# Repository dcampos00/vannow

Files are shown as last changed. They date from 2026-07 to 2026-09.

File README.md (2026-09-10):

# VanNOW: Sistema de Relés Inalámbricos para Camper Van

Este proyecto (**VanNOW**) contiene el diseño de hardware (como código) y el firmware para un sistema de conmutación de relés y transistores inteligente en una camper van, controlado de forma inalámbrica por ESP32 mediante el protocolo autónomo ESP-NOW.

---

## Estructura del Repositorio

- **`docs/`**: Contiene la documentación técnica, decisiones de arquitectura, especificaciones mecánicas y auditorías.
  - [**docs/README.md**](docs/README.md): **Centro de Documentación y Catálogo Maestro.**
  - [propuesta_proyecto.md](docs/propuesta_proyecto.md): Propuesta inicial aprobada.
  - [mechanical_and_enclosure_specs.md](docs/mechanical_and_enclosure_specs.md): Especificaciones de enclosures, cotas y mandos magnéticos.
- **`firmware/`**: Código fuente C++ para los microcontroladores (gestión con PlatformIO).
  - **`central/`**: Firmware del receptor en el gabinete eléctrico central. Controla MOSFETs, PROFETs y optoacopladores.
    - [platformio.ini](firmware/central/platformio.ini)
    - [src/main.cpp](firmware/central/src/main.cpp)
  - **`remote/`**: Firmware para los paneles de pulsadores inalámbricos autónomos. Utiliza Deep Sleep profundo y envía comandos al central.
    - [platformio.ini](firmware/remote/platformio.ini)
    - [src/main.cpp](firmware/remote/src/main.cpp)
- **`hardware/`**: Código de diseño de circuito impreso (PCB) y modelos CAD paramétricos 3D.
  - **`central-pcb/`**: Diseño Atopile de la placa de control central.
    - [ato.yaml](hardware/central-pcb/ato.yaml)
    - [central.ato](hardware/central-pcb/central.ato): Esquema y conexiones de la placa central.
  - **`enclosures/`**: Modelos 3D paramétricos generados con Python (`build123d`), archivos STEP/STL y renders.

---

## Cómo Empezar

### 1. Firmware (PlatformIO)

Para cargar el software en tus módulos ESP32:

1. Abre la carpeta `firmware/central/` o `firmware/remote/` en VS Code con la extensión **PlatformIO** instalada.
2. En el módulo **Central**, compila y sube el código. Abre el monitor serial a `115200 baudios` y copia la **Dirección MAC** del dispositivo.
3. En el archivo [src/main.cpp del módulo remoto](firmware/remote/src/main.cpp#L17), reemplaza la dirección MAC en `centralMacAddress` con la dirección que copiaste del central:

   ```cpp
   uint8_t centralMacAddress[] = {0x12, 0x34, 0x56, 0x78, 0x9A, 0xBC};
   ```

4. Carga el código en el módulo remoto.
5. ¡Listo! Al presionar los pulsadores (conectados a los pines indicados), el remoto transmitirá la señal de conmutación al central.

### 2. Hardware (Atopile)

Para compilar el circuito y generar los archivos de KiCad:

1. Asegúrate de tener instalado Python y Atopile (`pip install atopile`).
2. Abre una terminal en `hardware/central-pcb/`.
3. Ejecuta el comando para compilar:

   ```bash
   ato build
   ```

4. Esto validará las conexiones eléctricas y generará los esquemáticos y la netlist en formato compatible con **KiCad**.

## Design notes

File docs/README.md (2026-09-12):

# VanNOW Documentation Hub

Welcome to the **VanNOW** (Wireless Camper Van Relay System) engineering knowledge base. This directory compiles all architecture proposals, hardware evaluations, firmware specifications, mechanical 3D blueprints, safety audits, and feasibility studies.

---

## 🧭 Role-Based Navigation ("Where Do I Start?")

- **Working on Firmware?** Start with [`firmware_documentation.md`](firmware_documentation.md) for class models and state machines, then check [`roadmap.md`](roadmap.md) for prioritized features and [`logic_audit_2026-09-11.md`](logic_audit_2026-09-11.md) for the active logic findings (channel-map identity, Shower Mode keep-alive oscillation, encoder dual-dispatch).
- **Working on Hardware & PCB?** Review [`logic_audit_2026-09-11.md`](logic_audit_2026-09-11.md) for the current hardware/firmware desynchronization and residual electrical issues, [`logic_audit_2026-09-03.md`](logic_audit_2026-09-03.md) for the historical DevKit socket short (now fixed), [`evaluacion_hardware.md`](evaluacion_hardware.md) for MCU specs, [`analisis_critico_riesgos.md`](analisis_critico_riesgos.md) for flyback/bypass safety rules, and inspect [`references/`](references/) for component datasheets.
- **Working on 3D Printing & Enclosures?** Read [`mechanical_and_enclosure_specs.md`](mechanical_and_enclosure_specs.md) for DIN cabinet envelopes, 50 mm wiring clearances, and magnetic dock retention physics. Check `hardware/enclosures/` for Python CAD generators (`generate_enclosures.py`) and exported STEP/STL models.
- **Benchmarking & Power Budgets?** Review [`eficiencia_energetica.md`](eficiencia_energetica.md) for standby power analysis and [`evaluacion_costos_vanpi.md`](evaluacion_costos_vanpi.md) for BOM costing.

---

## 📚 Master Document Catalog

### 1. Architecture, System Design & Planning
| Document | Language | Status | Summary |
| :--- | :---: | :---: | :--- |
| [**project_status_and_tracking.md**](project_status_and_tracking.md) | EN | Active (Alpha) | Cross-domain status. Not a 1.0 or fab release. 11/24-ch flash envs. |
| [**central_controller_24ch_architecture.md**](central_controller_24ch_architecture.md) | EN | Active (Spec) | Expanded 24-channel Central Controller architecture, 14 PROFET + 10 optocoupler allocation, and modular firmware design. |
| [**propuesta_proyecto.md**](propuesta_proyecto.md) | ES | Active (Base) | Approved baseline project proposal: ESP-NOW wireless topology, 12V channel definitions, and Atopile introduction. |
| [**roadmap.md**](roadmap.md) | ES/EN | Active (Living) | Prioritized 4-tier feature roadmap (NVS persistence, WDT, anti-replay, scenes, LED feedback, web diagnostics). |
| [**gestion_repositorios_dual.md**](gestion_repositorios_dual.md) | ES | Active (Ops) | Private/public repo synchronization procedure and `sync_public.sh` documentation. |

### 2. Firmware & Wireless Protocols
| Document | Language | Status | Summary |
| :--- | :---: | :---: | :--- |
| [**firmware_documentation.md**](firmware_documentation.md) | ES | Active (Master) | Unified firmware architecture, class diagrams, 200 Hz PWM dimming, button/matrix FSMs, and PlatformIO environments. |
| [**atenuacion_remota.md**](atenuacion_remota.md) | ES | Active (Spec) | Remote dimmer button UX: Short-press toggle vs long-press ramp with 150 ms keep-alive packets. |
| [**control_encoder_rotativo.md**](control_encoder_rotativo.md) | ES | Active (Spec) | Rotary encoder (EC11) wireless logic, "Active-on-Demand" 1.5s timeout, and LP-GPIO pinouts. |
| [**analisis_seguridad_rf.md**](analisis_seguridad_rf.md) | ES | Decision | Threat model comparing 433 MHz ASK/OOK vs ESP-NOW; justifies discarding 433 MHz due to replay attacks. |
| [**integracion_cc1101_433mhz.md**](integracion_cc1101_433mhz.md) | ES | Evaluated | Technical evaluation of CC1101 Sub-GHz transceiver integration via SPI (alternative RF route). |

### 3. Hardware, PCB & Mechanical Engineering
| Document | Language | Status | Summary |
| :--- | :---: | :---: | :--- |
| [**remote_pcbs_architecture.md**](remote_pcbs_architecture.md) | EN | Active (Spec) | Architectural specification, UX evaluation & Diode-OR wakeup schematics for Cockpit Hub and Master Entrance Remote. |
| [**mechanical_and_enclosure_specs.md**](mechanical_and_enclosure_specs.md) | EN | Active (Master) | Enclosure dimensions, DIN-rail mounting, 50 mm wiring clearances, magnetic dockable remote (10.5N retention), PETG/ASA printing specs. |
| [**evaluacion_hardware.md**](evaluacion_hardware.md) | ES | Decision | Hardware selection: Lonely Binary ESP32-S3 N16R8 for Central, XIAO ESP32-C6 for Remotes, PCA9685 vs direct GPIOs. |
| [**opciones_encoders_bajo_perfil.md**](opciones_encoders_bajo_perfil.md) | ES | Component | Low-profile (5 mm) encoder selection: Panasonic EVQ-WGD thumbwheel, Alps EC12E SMD, and Alps EC10E hollow-shaft. |
| [**breadboard_prototyping_and_validation_guide.md**](breadboard_prototyping_and_validation_guide.md) | EN | Active (Lab) | Bench bring-up for 24-ch firmware + entrance remote: USB Phase A, fused 12 V Phase B, current pin map. |
| [**lista_compras_prototipo.md**](lista_compras_prototipo.md) | ES | Lab Guide | Component checklist and wiring guide for the breadboard prototype, including 3-step test plan. |
| [**skills/schematic-design**](../.agents/skills/schematic-design/SKILL.md) | EN | Skill | Comprehensive guide for Hardware-as-Code (Atopile), automotive power entry, PROFET switching, ADC clamping, and automotive protection. |
| [**skills/pcb-layout-automation**](../.agents/skills/pcb-layout-automation/SKILL.md) | EN | Skill | Procedural PCB layout, IPC-2152 automotive trace routing, thermal via arrays, and headless KiCad pcbnew DRC validation. |
| [**skills/esp32-firmware-engineering**](../.agents/skills/esp32-firmware-engineering/SKILL.md) | EN | Skill | Embedded firmware engineering for ESP32-S3 and ESP32-C6, 200 Hz PROFET PWM, sliding window anti-replay, LP-GPIO sleep wakeups, and native TDD. |
| [**skills/pcb-rendering**](../.agents/skills/pcb-rendering/SKILL.md) | EN | Skill | Automated KiCad raytracing, 1440p/4K isometric visualization, populated 3D STEP solid export, and ECAD/MCAD clash detection in build123d. |
| [**skills/parametric-cad-enclosures**](../.agents/skills/parametric-cad-enclosures/SKILL.md) | EN | Skill | Production guide for Python Code-as-CAD (`build123d`), heat-set fastener sizing, stepped joints, and software Z-buffer mesh verification. |
| [**skills/cross-domain-sync**](../.agents/skills/cross-domain-sync/SKILL.md) | EN | Skill | Cross-domain co-design audit matrix synchronizing Atopile netlists, KiCad layout, firmware GPIOs, and parametric CAD apertures. |
| [**references/**](references/) | PDF/XLSX | Assets | Official component datasheets (BTS5008 PROFET, MP1584EN, PC817, ESP32-S3, ESP32-C6). |

### 4. Audits, Verification & Risk Analysis
| Document | Language | Status | Summary |
| :--- | :---: | :---: | :--- |
| [**logic_audit_2026-09-11.md**](logic_audit_2026-09-11.md) | EN | Active (Must Read) | Current comprehensive logic audit: 11ch vs 24ch identity split, Shower Mode keep-alive oscillation, encoder dual-dispatch, missing DoubleClick, XIAO D10/GPIO9 LED error. |
| [**logic_audit_2026-09-03.md**](logic_audit_2026-09-03.md) | EN | Historical (Closed blockers) | Prior audit of 7 critical flaws (DevKit GND short, replay bypass, 5 kHz PWM, 3.3V Zener). Blockers fixed; superseded by 2026-09-11. |
| [**auditoria_logica_2026-07-11.md**](auditoria_logica_2026-07-11.md) | ES | Historical | Preliminary audit uncovering 25 hardware/firmware issues (USB-JTAG collisions on GPIO 19/20, PSRAM collisions). |
| [**analisis_critico_riesgos.md**](analisis_critico_riesgos.md) | ES | Active (Safety) | Electrical fire hazards, inductive flyback diode (1N5408), diesel heater/fridge PC817 logic, and ON-OFF-AUTO bypass panel mounting. |

### 5. Feasibility, Energy Budgets & Benchmarking
| Document | Language | Status | Summary |
| :--- | :---: | :---: | :--- |
| [**eficiencia_energetica.md**](eficiencia_energetica.md) | ES | Active (Budget) | Standby power budget: VanNOW (0.15 W, 0.25 Ah/day -> 400 days on 100Ah) vs Home Assistant/VanPi (10–15 W, 20–30 Ah/day -> 5 days). |
| [**evaluacion_costos_vanpi.md**](evaluacion_costos_vanpi.md) | ES | Reference | Cost estimation: VanNOW DIY (~$137 USD) vs Pekaway VanPi official hardware (~348 EUR). |
| [**proyectos_existentes_maduros.md**](proyectos_existentes_maduros.md) | ES | Reference | Industry benchmark comparing VanPi, Home Assistant + ESPHome, and Victron Venus OS. |
| [**estimacion_complejidad_tiempo.md**](estimacion_complejidad_tiempo.md) | ES | Reference | 4-phase project timeline breakdown: 30–50 active hours across 6–10 calendar weeks. |

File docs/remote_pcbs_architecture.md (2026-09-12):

# VanNOW — Cockpit Switch Hub & Master Magnetic Remote Architectural Specification

This document presents the UX evaluation, electrical schematics, mechanical integration, and firmware protocol mapping for the two new remote units in the **VanNOW** camper ecosystem:
1. **Cockpit Dashboard Switch Box (`cockpit-pcb`):** A hidden, battery-powered interface transmitter behind the van dash connecting directly to user-supplied automotive Carling rocker switch blanks.
2. **Master Magnetic Entrance Remote (`entrance-remote-pcb`):** A dockable multi-button and rotary dimmer panel retained magnetically at the van sliding door.

---

## 1. UX & Ergonomic Evaluation: Master Entrance Remote Dimming & Configurations

The user requested an evaluation comparing **Option 1 (Buttons + Rotary Dimmer Knob)** versus **Option 3 (Expanded 10–12 Button Matrix / Dedicated Configuration Buttons)** for intuitive van lighting control.

```
+-----------------------------------------------------------------------------------------------+
|                       COMPARATIVE EVALUATION: VAN ENTRANCE CONTROLLER                         |
+------------------------------+--------------------------------+-------------------------------+
| CRITERIA                     | OPTION 1: 6 BUTTONS + ENCODER  | OPTION 3: 10-12 BUTTON MATRIX |
+------------------------------+--------------------------------+-------------------------------+
| Primary Interaction          | "Select Zone -> Turn Knob"     | "One-Touch Scene / Function"  |
| Dimming Granularity          | 1% steps (tactile detents)     | Timed Hold or 3-step presets  |
| Mechanical Complexity        | Rotary shaft + 6 push buttons  | 10-12 membrane / tactile keys |
| Darkness / Blind Ergonomics  | Tactile knob easily found      | Requires searching key grid   |
| Multi-Scene / Presets        | Click encoder for mode/preset  | Dedicated button per scene    |
| Existing 3D CAD Alignment    | 100% matched to 86x86 mm CAD   | Requires larger faceplate     |
+------------------------------+--------------------------------+-------------------------------+
```

### 1.1 The Challenge: Multi-Zone Dimming in a Camper Van
A camper van has 4 distinct dimmable lighting zones:
- **Zone 1:** Main Ceiling Downlights (200 Hz PWM)
- **Zone 2:** Kitchen Galley Worktop (200 Hz PWM)
- **Zone 3:** Bed / Reading Nook (200 Hz PWM)
- **Zone 4:** Porch / Exterior Awning (PROFET Aux 1)

In addition, it controls high-power appliances: **Water Pump (Seaflo 7.5A)**, **Inverter (Multiplus II)**, and **Ceiling Vent Fan**.

### 1.2 Paradigm Analysis

#### Paradigm A: "Select & Turn" (Option 1 — 6 Buttons + EC11 Rotary Encoder)
- **How It Works:**
  1. Each zone has its own tactile button with a label/icon (Ceiling, Galley, Bed, Porch).
  2. Tapping a button toggles that zone ON/OFF immediately and selects it as the *Active Focus Zone* for 3.0 seconds.
  3. Turning the EC11 rotary knob adjusts the brightness of the active zone in real time with continuous tactile feedback (clicks).
  4. Pushing the encoder knob itself operates as **Instant 100% Boost** or cycles through brightness presets (20% -> 50% -> 100%).
  5. Buttons 5 and 6 are dedicated to **Water Pump Toggle** and **Master Night Shutdown (All OFF)**.
- **Ergonomic Verdict:** **Superior for fine-grained lighting comfort.** When reading or cooking, you can set the exact lumen output in 0.5 seconds without waiting for a slow software ramp.

#### Paradigm B: "Dedicated Scene Presets" (Option 3 — 10–12 Button Keypad Matrix)
- **How It Works:**
  Instead of manual dimming adjustments every time, van lighting is organized into pre-programmed camper scenes:
  - **Button 1 (Day / Bright):** Ceiling 100%, Galley 100%, Bed OFF.
  - **Button 2 (Galley / Cooking):** Galley 100%, Ceiling 40%, Fan ON.
  - **Button 3 (Evening / Cozy):** Ceiling 20%, Bed 25%, Warm ambient.
  - **Button 4 (Night / Sleep):** All lights OFF, Water Pump OFF.
  - **Button 5 (Exterior / Campsite):** Porch ON 80%, Step lights ON.
  - **Buttons 6–10:** Individual toggles for Water Pump, Inverter, Vent Fan, Fridge, Aux.
- **Ergonomic Verdict:** **Superior for zero-cognitive-load operation.** Any guest, child, or tired traveler can hit "Bedtime" or "Cooking" and the entire van configures itself without touching individual dimmers.

### 1.3 Recommended Architectural Decision: The Unified Hybrid Model
We can achieve the best of both paradigms within the **exact 86 mm x 86 mm physical form factor** already designed in 3D CAD:
1. **Short Tap on Zone Button:** Toggles ON/OFF.
2. **Double Tap on Zone Button:** Activates that Zone's Favorite Preset (e.g. 30% Nightlight).
3. **Turn Rotary Knob:** Adjusts brightness of the active zone up/down.
4. **Dedicated Master Night Shutdown Button:** One-touch full van shutdown.
5. **Hardware Compatibility:** The carrier board PCB is engineered with standard matrix traces, allowing the exact same microcontroller firmware to support either:
   - The 6-Button + EC11 Encoder Faceplate (Dockable remote).
   - A 10-Keypad tactile membrane panel if preferred.

---

## 2. Cockpit Dashboard Switch Box (`cockpit-pcb`)

### 2.1 Concept & Vehicle Integration
Modern camper vans (Mercedes Sprinter, Ford Transit, Ram ProMaster, VW Crafter) feature standard blank switch plates on the center console and lower dash. Installing custom all-in-one screens or surface boxes on the dash disrupts vehicle aesthetics and creates clutter.

```
DASHBOARD INTERFACE ARCHITECTURE:
+-------------------------------------------------------------------------+
| VEHICLE COCKPIT DASHBOARD                                               |
|                                                                         |
|   [ Carling Blank 1 ]  [ Carling Blank 2 ]  [ Carling Blank 3 ]         |
|   (Exterior Driving)   (Orion-XS DC-DC)     (Cabin Main Lights)         |
|   [ Carling Blank 4 ]  [ Carling Blank 5 ]  [ Carling Blank 6 ]         |
|   (Water Pump)         (Inverter AC)        (Aux 12V / Fan)             |
|            |                    |                    |                  |
|            +--------------------+--------------------+                  |
|                                 | (Automotive Signal Harness, 22 AWG)   |
|                                 v                                       |
|               +-----------------------------------+                     |
|               | COCKPIT TRANSMITTER BOX (HIDDEN)  |                     |
|               | - 6x Screw Terminal Block         |                     |
|               | - Diode-OR Wakeup (BAS70-04)      |                     |
|               | - Seeed Studio XIAO ESP32-C6      |                     |
|               | - 2x AA Battery Bay (Internal)    |                     |
|               | - Sub-15 uA Deep Sleep            |                     |
|               +-----------------------------------+                     |
|                                 |                                       |
|                                 | ESP-NOW (Encrypted, 2.4 GHz)          |
|                                 v                                       |
|                  [ Central Relay Electrical Cabinet ]                   |
+-------------------------------------------------------------------------+
```

### 2.2 Technical Specifications

| Parameter | Specification | Notes |
| :--- | :--- | :--- |
| **Enclosure Envelope** | $76.0\,\text{mm} \times 58.0\,\text{mm} \times 30.0\,\text{mm}$ | `cockpit_enclosure_*` (20 mm base + 10 mm lid) with dual M4 ears (108 mm span). |
| **Power Supply** | $2\times\,\text{AA}$ Alkaline Cells ($3.0\,\text{V}$ nominal) | Direct connection to $3.3\,\text{V}$ rail. Shelf life $>5$ years. |
| **Standby Current** | **$14.8\,\mu\text{A}$** in Deep Sleep | $2600\,\text{mAh} / 0.015\,\text{mA} \approx 173,000\,\text{hours} \approx 19\,\text{years}$. |
| **Switch Inputs** | 6 independent channels via 3.5 mm pluggable terminal blocks | Compatible with momentary rocker switches, pushbuttons, and Carling V-Series. |
| **Wakeup Architecture** | Diode-OR Schottky matrix to `LP-GPIO 0` (Header D0) | Wakes in $<2\,\text{ms}$ upon pressing any dash switch. |
| **RF Protocol** | ESP-NOW with RFC 6479 anti-replay sequence tracking | Transmission latency $<12\,\text{ms}$ from button press to central relay toggle. |

### 2.3 Switch Mapping from Cockpit

| Channel | Dashboard Switch Target | Load Controlled at Central | Action |
| :---: | :--- | :--- | :--- |
| **SW1** | **Exterior Auxiliary Lights** | Channel 5 Exterior Driver (BTS5008) | Edge Click: Toggle ON / OFF |
| **SW2** | **Victron Orion-XS DC-DC #1** | Channel 15 (PC817 remote enable) | Edge Click: Enable / Disable charger |
| **SW3** | **Cabin Interior Lights** | Channel 0 Zone 1 (200 Hz LEDC) | Edge Click: Toggle ON / OFF |
| **SW4** | **Water Pump (Seaflo)** | Channel 4 (BTS5008 + flyback) | Edge Click: Toggle (10-min failsafe) |
| **SW5** | **Inverter (Multiplus II)** | Channel 14 (PC817 remote switch) | Edge Click: Toggle AC inverter |
| **SW6** | **Maxxair Fan Power** | Channel 8 (BTS5008 12 V cut) | Edge Click: Toggle fan standby power |

---

## 3. Master Magnetic Entrance Remote (`entrance-remote-pcb`)

### 3.1 Physical & Mechanical Alignment
This PCB matches the mechanical clearances of [`remote_enclosure_body.step`](file:///var/home/daniel/Projects/vannow/hardware/enclosures/models/remote_enclosure_body.step) and [`remote_enclosure_faceplate.step`](file:///var/home/daniel/Projects/vannow/hardware/enclosures/models/remote_enclosure_faceplate.step):

```
PCB MECHANICAL OUTLINE:
+-------------------------------------------------------------+ (80.0 mm)
|   [Mount M2.5]                                 [Mount M2.5] |
|                      (O) EC11 ROTARY ENCODER                |
|                           (Master Dimmer)                   |
|                                                             |
|                            (*) Status LED                   |
|                                                             |
|       [BTN 1: Zone 1]                  [BTN 2: Zone 2]      |
|       (Main Ceiling)                   (Kitchen Galley)     |
|                                                             |
|       [BTN 3: Zone 3]                  [BTN 4: Zone 4]      |
|       (Bed / Reading)                  (Porch / Awning)     |
|                                                             |
|       [BTN 5: Water Pump]              [BTN 6: Master OFF]  |
|       (Seaflo 12V)                     (Night Shutdown)     |
|                                                             |
|   +-----------------------------------------------------+   |
|   |         2x AA BATTERY BAY CLEARANCE CUTOUT          |   |
|   +-----------------------------------------------------+   |
|   [Mount M2.5]                                 [Mount M2.5] |
+-------------------------------------------------------------+ (80.0 mm)
```

- **PCB Dimensions:** $80.0\,\text{mm} \times 80.0\,\text{mm} \times 1.6\,\text{mm}$ (clears $2.5\,\text{mm}$ enclosure walls).
- **Mounting Standoffs:** 4x M2.5 holes located at $(\pm 30.0\,\text{mm}, \pm 30.0\,\text{mm})$ from center.
- **Magnet Keep-Out Zones:** 4x clearance areas along the edge centers $(X=\pm 28\,\text{mm}, Y=0)$ and $(X=0, Y=\pm 28\,\text{mm})$ to allow enclosure magnet pockets to seat without copper interference.
- **Component Height Budget:**
  - Omron B3F tactile switches: $5.0\,\text{mm}$ total height.
  - Low-profile EC11 rotary encoder: $5.0\,\text{mm}$ bushing, $15.0\,\text{mm}$ shaft.
  - Seeed Studio XIAO ESP32-C6: socketed via female headers on the rear/bottom.

---

## 4. Hardware Schematics & Wake-Up Circuitry

### 4.1 Cockpit Transmitter Schematics (`cockpit.ato`)
The cockpit PCB uses a 6-channel Diode-OR circuit to wake the ESP32-C6 from deep sleep on any pin transition, while routing each switch line to an independent GPIO for identification:

```
COCKPIT DIODE-OR WAKEUP MATRIX:
                       +3.3V
                         |
                      [47k R1]
                         |
      +------------------+-------------------> D0 / GPIO 0 (LP_GPIO EXT1 Wakeup)
      |         |        |        |        |        |
    [D1]      [D2]     [D3]     [D4]     [D5]     [D6]  (BAS70-04 Low-Leakage Schottky)
      |         |        |        |        |        |
      +---------+--------+--------+--------+--------+
      |         |        |        |        |        |
    (SW1)     (SW2)    (SW3)    (SW4)    (SW5)    (SW6) (Terminal Block Inputs from Dash)
      |         |        |        |        |        |
     GND       GND      GND      GND      GND      GND
      |         |        |        |        |        |
      v         v        v        v        v        v
     D1        D2       D3       D4       D5       D6   (Individual Sense Pins on XIAO)
  (GPIO 1)  (GPIO 2) (GPIO 21) (GPIO 22) (GPIO 23) (GPIO 16)
```

### 4.2 Master Remote Schematics (`entrance_remote.ato`)
The entrance remote incorporates both the 6 tactile push buttons (diode-ORed to D0) and the 2 EC11 quadrature signals:
- **D0 (GPIO 0 / LP-GPIO):** Wakeup line from Buttons 1–6 and Encoder Switch.
- **D1 (GPIO 1 / LP-GPIO):** Encoder Channel A (supports EXT1 wakeup on knob rotation).
- **D2 (GPIO 2 / LP-GPIO):** Encoder Channel B (supports EXT1 wakeup on knob rotation).
- **D3 (GPIO 21):** Sense Button 1 (Zone 1 Lights).
- **D4 (GPIO 22):** Sense Button 2 (Zone 2 Lights).
- **D5 (GPIO 23):** Sense Button 3 (Zone 3 Lights).
- **D6 (GPIO 16):** Sense Button 4 (Zone 4 Lights).
- **D7 (GPIO 17):** Sense Button 5 (Water Pump).
- **D8 (GPIO 19):** Sense Button 6 (Master Night Shutdown).
- **D9 (GPIO 20):** Sense Encoder Push Button.
- **D10 (GPIO 18):** Status Micro-LED (ESP-NOW ACK). GPIO 9 is the BOOT strap and is not used.

### 4.3 Timed Water Pump Shower Mode & User Notification
To conserve fresh water and prevent grey water overflows, the water pump incorporates a dedicated **Shower Mode** (default 5 minutes = 300 seconds with NVS persistence):
* **Triggering:**
  - **Double-Click** or **Long-Press (>400 ms / 1.5s)** on the Water Pump button engages Shower Mode.
  - Single Click operates as standard ON/OFF toggle (backed by the 10-minute flood failsafe).
  - Pressing the button at any time during the 5 minutes immediately cancels and turns the pump OFF.
* **Dual Feedback & Notification System:**
  1. **Visual Remote Feedback:** The status Micro-LED on the remote panel (GPIO 18 / D10) flashes **3 rapid pulses (80 ms ON / 80 ms OFF)** upon initiating Shower Mode.
  2. **Hydraulic / Acoustic Pump Chirp:** The central controller pulses the pump twice (**150 ms ON, 120 ms OFF, 150 ms ON, 120 ms OFF**) before entering steady flow. The mechanical pressure bump creates an audible confirmation through the camper plumbing lines, informing anyone inside the shower stall that the timer is active.
* **NVS Persistence:** The timer duration is persisted in NVS namespace `vannow_state`, key `pump_shower_ms` (configurable programmatically or via serial/web).

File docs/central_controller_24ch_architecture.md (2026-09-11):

# VanNOW Expanded 24-Channel Central Controller Architecture

## 1. Overview & Architectural Motivation

The VanNOW system centralizes all camper van switching, dimming, and energy control inside the electrical cabinet. As van builds scale to incorporate comprehensive power systems (e.g., Victron MultiPlus inverter/chargers, dual Orion-XS DC-DC chargers, MPPT solar regulators), multi-zone dimmable lighting, smart ventilation (Maxxair Fan), plumbing automation, and climate control (diesel heater, 12V compressor fridge), a standard 8-to-11 channel controller quickly becomes saturated.

This architecture expands the Central Controller to **24 independent channels** while establishing a fully modular, parameterized firmware design that allows arbitrary channel configurations (from 1 to 32 channels) to be provisioned through parameters with zero firmware re-compilation.

---

## 2. Load Allocation & Channel Breakdown

The 24 channels are divided into two distinct electrical topologies:
1. **14 High-Side Power Channels (12V PROFET BTS5008-1EKB):** High-current automotive solid-state switching with integrated over-current, thermal shutdown, and short-circuit protection.
2. **10 Isolated Signal Channels (PC817 Optocouplers / Dry Contacts):** Galvanically isolated semiconductor contacts designed for control logic lines, remote terminals, thermostat signals, and momentary keypad simulation.
3. **1 Analog Telemetry Channel (GPIO 1):** Main 12V cabin battery voltage sensing.

### Master Channel Assignment Matrix

| Channel | Category | Hardware Type | Pin (ESP32-S3) | Designated Load / Device | Operational Mode / Safety Policy |
| :--- | :--- | :--- | :--- | :--- | :--- |
| **Ch 0** | Power | PROFET BTS5008 | GPIO 12 | Interior Lights Zone 1 | Dimmable (LEDC PWM 200 Hz), Restore ON |
| **Ch 1** | Power | PROFET BTS5008 | GPIO 13 | Interior Lights Zone 2 | Dimmable (LEDC PWM 200 Hz), Restore ON |
| **Ch 2** | Power | PROFET BTS5008 | GPIO 14 | Interior Lights Zone 3 | Dimmable (LEDC PWM 200 Hz), Restore ON |
| **Ch 3** | Power | PROFET BTS5008 | GPIO 15 | Interior Lights Zone 4 | Dimmable (LEDC PWM 200 Hz), Restore ON |
| **Ch 4** | Power | PROFET BTS5008 | GPIO 4 | Fresh Water Pump | Digital Switch, 10 min Auto-Off, Shower Mode, **Restore = False** |
| **Ch 5** | Power | PROFET BTS5008 | GPIO 5 | Exterior Driver Light | Digital Switch, Restore ON |
| **Ch 6** | Power | PROFET BTS5008 | GPIO 6 | Exterior Passenger Light | Digital Switch, Restore ON |
| **Ch 7** | Power | PROFET BTS5008 | GPIO 7 | Aux Lightbar / Roof Light | Digital Switch, Restore ON |
| **Ch 8** | Power | PROFET BTS5008 | GPIO 17 | Maxxair Fan 12V Main Power | Digital Switch (Standby Cut), 1N5408 Diode, Restore ON |
| **Ch 9** | Power | PROFET BTS5008 | GPIO 8 | Aux Power 1 (Water Boiler) | Digital Switch, Restore ON |
| **Ch 10** | Power | PROFET BTS5008 | GPIO 9 | Aux Power 2 (Grey Dump Valve) | Digital Switch, Motorized Ball Valve, **Restore = False** |
| **Ch 11** | Power | PROFET BTS5008 | GPIO 10 | Aux Power 3 (Tank Heating Pad) | Digital Switch, Low-temp Freeze Protection, **Restore = False** |
| **Ch 12** | Power | PROFET BTS5008 | GPIO 11 | Aux Power 4 (Aux 12V Sockets) | Digital Switch, USB-C PD / 12V Sockets, Restore ON |
| **Ch 13** | Power | PROFET BTS5008 | GPIO 18 | Aux Power 5 (Motorized Awning) | Digital Switch, Auxiliary / Awning, Restore ON |
| **Ch 14** | Signal | Optocoupler PC817 | GPIO 21 | Victron MultiPlus II Remote | Isolated Dry Contact (Remote Switch H/L), Restore ON |
| **Ch 15** | Signal | Optocoupler PC817 | GPIO 38 | Victron Orion-XS #1 Remote | Isolated Dry Contact (Remote Terminal), Restore ON |
| **Ch 16** | Signal | Optocoupler PC817 | GPIO 39 | Victron Orion-XS #2 Remote | Isolated Dry Contact (Remote Terminal), Restore ON |
| **Ch 17** | Signal | Optocoupler PC817 | GPIO 40 | Victron SmartSolar MPPT | Isolated Dry Contact (Remote Terminal), Restore ON |
| **Ch 18** | Signal | Optocoupler PC817 | GPIO 41 | Diesel Heater Thermostat | Isolated Dry Contact (Thermostat Signal Wire), Restore ON |
| **Ch 19** | Signal | Optocoupler PC817 | GPIO 42 | 12V Compressor Fridge | Isolated Dry Contact (Secop/Danfoss T and C), Restore ON |
| **Ch 20** | Signal | Optocoupler PC817 | GPIO 47 | Maxxair Keypad Power Pulse | Momentary Pulse (250 ms), Non-latching, **Restore = False** |
| **Ch 21** | Signal | Optocoupler PC817 | GPIO 48 | Aux Signal 1 (Alarm Chirp) | Digital Switch / Siren Trigger, **Restore = False** |
| **Ch 22** | Signal | Optocoupler PC817 | GPIO 2 | Aux Signal 2 (LPG Gas Solenoid) | Digital Switch, Solenoid Valve, **Restore = False** |
| **Ch 23** | Signal | Optocoupler PC817 | GPIO 16 | Aux Signal 3 (Generator Start) | Momentary Pulse (500 ms), Cranking Pulse, **Restore = False** |
| **ADC** | Telemetry | Analog Resistor Div | GPIO 1 | Main 12V Cabin Battery | 100k / 18k Divider (Ratio 6.555), 1k ESD Protection |

---

## 3. Specific Device Integration Specifications

### 3.1 Maxxair Fan Dual-Channel Architecture
The Maxxair Deluxe roof fan requires a specialized two-tier control strategy:
- **Quiescent Drain Problem:** When off, the internal logic board continuously draws ~15 mA (0.18 W) in standby.
- **Power Restoration Behavior:** Abruptly restoring 12V does not spin up the fan; the internal microcontroller boots up in Standby mode with the dome closed.
- **Solution:**
  1. **Channel 8 (GPIO 17, PROFET):** Hard 12V power cut. Completely eliminates standby drain during storage or parked mode.
  2. **Channel 20 (GPIO 47, PC817 Optocoupler):** Momentary pulse (250 ms). Optocoupler collector and emitter are wired in parallel across the keypad membrane `ON/OFF` button contacts. Emitting a 250 ms pulse simulates a physical keypress, toggling the fan on/off without modifying manufacturer firmware.

### 3.2 Victron Power System Control
- **MultiPlus II Inverter/Charger (Channel 14):** The MultiPlus remote connector features two terminals (`H` and `L`). Connecting them enables the inverter. PC817 collector connects to `H` and emitter to `L`.
- **Orion-XS DC-DC Chargers #1 and #2 (Channels 15 & 16):** Independent remote switching enables flexible alternator charging control (e.g., run 1 charger at 50A for city driving; run both at 100A for highway cruising).
- **SmartSolar MPPT (Channel 17):** Allows remote solar isolation when servicing electrical systems or when the lithium battery is at low temperatures.

### 3.3 Diesel Heater (Channel 18)
- **CRITICAL SAFETY DIRECTIVE:** The main 12V power supply to the diesel heater must NEVER be cut with a relay while operating, as this bypasses the essential cooldown purge cycle and melts the heat exchanger.
- **Implementation:** 12V power remains permanently connected to the fused battery bus. Channel 18 (PC817) switches ONLY the thermostat signal wire (or external on/off remote input on Autoterm/Webasto/Eberspächer units).

### 3.4 12V Compressor Refrigerator (Channel 19)
- Operates Secop / Danfoss BD35F/BD50F controllers via terminals `T` (thermostat) and `C` (common). Closing the contact runs the compressor; opening it shuts down the compressor safely while keeping internal display/thermostat logic active.

### 3.5 Water Pump Safety Automation (Channel 4)
- **10-Minute Safety Auto-Off:** Prevents catastrophic van flooding in case of burst PEX pipe or faucet left on.
- **5-Minute Shower Mode:** Activated via remote `DoubleClick` or `StartHold`. Emits an acoustic double-pulse confirmation chirp (150 ms on, 120 ms pause, 150 ms on, 120 ms pause, continuous run) and automatically terminates after the configured duration (restorable via NVS).
- **Flood Prevention Boot Policy:** `restoreOnBoot = false`. Following a brownout or MCU restart, the pump remains OFF.

---

## 4. ESP32-S3 DevKitC-1 N16R8 Hardware Pinout Matrix

To ensure 100% hardware reliability, all 24 GPIO assignments strictly avoid:
- **Boot Strapping Pins:** GPIO 0, 3, 45, 46.
- **Octal SPI Flash & PSRAM Pins:** GPIO 33, 34, 35, 36, 37 (connected internally on N16R8 modules).
- **Native USB PHY Pins:** GPIO 19, 20 (reserved for native USB debugging and flashing).
- **UART0 Pins:** GPIO 43 (TX), 44 (RX) (reserved for serial telemetry).

### DevKit Header Pin Distribution

```
                 ESP32-S3 DevKitC-1 v1.1
                 +---------------------+
           3V3 --| 1  (J1)     (J3)  1 |-- GND
           3V3 --| 2                 2 |-- TX (GPIO 43) [DEBUG]
            EN --| 3                 3 |-- RX (GPIO 44) [DEBUG]
 [CH 4] GPIO 4 --| 4                 4 |-- GPIO 1  [BATTERY ADC]
 [CH 5] GPIO 5 --| 5                 5 |-- GPIO 2  [CH 22: LPG Solenoid]
 [CH 6] GPIO 6 --| 6                 6 |-- GPIO 42 [CH 19: 12V Fridge]
 [CH 7] GPIO 7 --| 7                 7 |-- GPIO 41 [CH 18: Diesel Heater]
 [CH 3] GPIO 15 -| 8                 8 |-- GPIO 40 [CH 17: MPPT Remote]
[CH 23] GPIO 16 -| 9                 9 |-- GPIO 39 [CH 16: Orion #2]
 [CH 8] GPIO 17 -| 10               10 |-- GPIO 38 [CH 15: Orion #1]
[CH 13] GPIO 18 -| 11               11 |-- GPIO 37 [OCTAL FLASH - NC]
 [CH 9] GPIO 8 --| 12               12 |-- GPIO 36 [OCTAL FLASH - NC]
  [USB] GPIO 19 -| 13               13 |-- GPIO 35 [OCTAL PSRAM - NC]
  [USB] GPIO 20 -| 14               14 |-- GPIO 0  [BOOT - NC]
 [STRAP] GPIO 3 -| 15               15 |-- GPIO 45 [STRAP - NC]
[STRAP] GPIO 46 -| 16               16 |-- GPIO 48 [CH 21: Aux Signal 1]
[CH 10] GPIO 9 --| 17               17 |-- GPIO 47 [CH 20: Maxxair Pulse]
[CH 11] GPIO 10 -| 18               18 |-- GPIO 21 [CH 14: Inverter Remote]
[CH 12] GPIO 11 -| 19               19 |-- GPIO 14 [CH 2: Light Zone 3]
 [CH 0] GPIO 12 -| 20               20 |-- GPIO 13 [CH 1: Light Zone 2]
           5V  --| 21               21 |-- GND
           GND --| 22               22 |-- GND
                 +---------------------+
```

---

## 5. Modular Firmware Architecture

The firmware decouples physical hardware configuration from switching logic:

### 5.1 Polymorphic Channel Classes
- `Channel` (Abstract Base): Defines `handleAction(ActionType, int8_t)`, `setState(bool)`, `update()`, persistence flags, and state-change callbacks.
- `DimmableChannel`: Implements 200 Hz LEDC PWM, 1% per 5 ms smooth exponential fading, 30 ms hold ramping, and rotary encoder velocity scaling.
- `DigitalChannel`: Implements latching on/off switching, configurable auto-off safety timers, and timed shower mode with acoustic chirping.
- `PulseChannel`: Implements non-latching momentary pulse generation with configurable active duration (e.g., 250 ms for Maxxair, 500 ms for generator start).

### 5.2 Parameterized SystemController
```cpp
enum class ChannelType : uint8_t { Dimmable, Digital, MomentaryPulse };

struct ChannelConfig {
    const char* name;
    uint8_t pin;
    ChannelType type;
    uint32_t autoOffTimeoutMs;
    bool restoreOnBoot;
    uint8_t defaultBrightness;
    bool activeLow;
};

// Parameterized initialization supports custom configurations:
SystemController controller(customConfigs, channelCount, customMappings, mappingCount);
```

### 5.3 Decoupled Remote Routing Table
Remote panels emit packets containing `remote_id`, `button_index`, `action`, and `seq`. The routing table maps `(remote_id, button_index)` to target channels or global macro actions:
- `Remote 1 (Entry Panel)`: Zone 1, Zone 2, Water Pump, Inverter, Zone 3, Zone 4, Maxxair Power.
- `Remote 2 (Bed Panel)`: Zone 3, Zone 4, Maxxair Power, **TurnOffAllLights (Macro)**, Zone 1, Zone 2, Water Pump.
- `Remote 3 (Cockpit Panel)`: Exterior Driver, Orion-XS #1, Zone 1, Water Pump, Inverter, Maxxair Power.

---

## 6. Physical Packaging & Parametric 3D Enclosure

### 6.1 Carrier Board Packaging
- **PCB Dimensions:** 180.0 mm × 110.0 mm (FR4 double-sided, 2 oz copper).
- **Connector Strategy:** High-density two-tier (double-decker) 5.08 mm pitch screw terminal blocks. Placing terminals in two vertical tiers accommodates 48 connection poles within a 140 mm run along the board edges.
- **Mounting Holes:** 4x M3 at (±85.0 mm, ±50.0 mm) (170.0 mm × 100.0 mm pitch).

### 6.2 Parametric Enclosure Dimensions (`build123d`)
The 3D model is generated parametrically by `hardware/enclosures/scripts/generate_enclosures.py`:
- **Outer Shell Dimensions:** 205.0 mm (Length) × 135.0 mm (Width) × 52.0 mm (Height).
- **Y-Axis Mounting Ears:** Dual mounting ears placed along the 135 mm width axis with 4.5 mm M4 holes:
  $$\text{Total Width with Ears} = 135.0\,\text{mm} + 2 \times 22.0\,\text{mm} = 179.0\,\text{mm}$$
- **Cabinet Envelope Verification:**
  - Length: 205.0 mm $\le$ 230.0 mm cabinet limit (**25 mm clearance**).
  - Width: 179.0 mm $\le$ 190.0 mm cabinet limit (**11 mm clearance**).
  - Height: 54.2 mm (base + lid) $\le$ 85.0 mm cabinet limit (**30.8 mm clearance**).
  - Wiring Drop: Front cable gland ports preserve $\ge 50.0\,\text{mm}$ drop clearance.
- **Mechanical Features:**
  - Stepped interlocking lip and groove (+2.2 mm / -2.4 mm) for dust and splash sealing.
  - 4x M3 brass heat-set insert corner bosses (dia 4.0 mm × depth 6.0 mm).
  - 4x M3 PCB standoffs with triangular reinforcing gusset ribs.
  - 6x PG9/PG11 cable gland collars (dia 16.0 mm with 22.0 mm outer boss).
  - Convective ventilation slots for PROFET thermal dissipation.
  - 6x SPDT toggle switch mounting stations on the lid with anti-rotation keyways.

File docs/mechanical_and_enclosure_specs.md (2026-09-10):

# VanNOW: Mechanical Enclosure Specifications, 3D Architecture, and Spatial Budget

This specification defines the physical envelopes, 3D mechanical designs, spatial budgeting, mounting interfaces, and thermal/wire management requirements for the **VanNOW** camper van relay system.

---

## 1. Spatial Budget Summary

```
+-----------------------------------------------------------------------------------------+
|                               VAN INTERIOR SPATIAL BUDGET                               |
+------------------------------------+----------------------------------------------------+
| LOCATION                           | ENVELOPE (W x H x D)      | MOUNTING TYPE          |
+------------------------------------+----------------------------------------------------+
| 1. Main Electrical Cabinet         | 230 mm x 190 mm x 85 mm   | 35mm DIN-Rail / M4 Tab |
| 2. Bed Wall Panel (Fixed)          | 86 mm x 86 mm x 22 mm     | Surface / Semi-Flush   |
| 3. Sliding Door Panel (Dockable)   | 90 mm x 135 mm x 24 mm    | Magnetic Self-Aligning |
+------------------------------------+----------------------------------------------------+
```

---

## 2. Central Electrical Cabinet Enclosure

### 2.1 Dimensions & Clearances

| Component | Width ($X$) | Height ($Y$) | Depth ($Z$) | Notes |
| :--- | :---: | :---: | :---: | :--- |
| **Bare PCB Assembly** | **150 mm** | **95 mm** | **28 mm** | 2-layer FR4, 2 oz copper; includes socketed ESP32-S3 and MP1584EN. |
| **External Enclosure** | **175 mm** | **125 mm** | **65 mm** | Rugged industrial ABS/Polycarbonate housing with clear tinted lid. |
| **Required Installation Envelope** | **230 mm** | **190 mm** | **85 mm** | **Total free clearance needed inside cabinet** for wiring & switches. |

### 2.2 Wire Dress & Bend Radius Requirements
* **Automotive Wire Guages:** 12 AWG (Pump, Aux outlets) and 14 AWG (LED zones, ceiling fan) require a minimum static bend radius:
  $$R_{bend} \ge 4 \times D_{wire} \approx 25\,\text{mm} - 35\,\text{mm}$$
* **Vertical Wiring Clearance:** A dedicated clearance zone of **50 mm beneath the enclosure** is strictly mandated. This ensures that wire bundles routed out of the 5.08 mm pitch pluggable screw terminals exit cleanly into slotted cable ducting (40 mm $\times$ 40 mm) without placing mechanical cantilever strain on PCB solder joints.
* **Cable Ingress:** Bottom wall fitted with 4x **PG9 / PG11 cable glands** or silicone multi-cable pass-through grommets.

### 2.3 Mechanical Redundancy Panel (Front Cover)
* **Toggle Switches:** 5x heavy-duty SPDT miniature toggle switches (**ON-OFF-ON / ON-OFF-AUTO**) mounted through 6.35 mm (1/4") panel holes on the lid.
* **Faston Terminal Clearance:** The 65 mm enclosure depth guarantees a minimum 18 mm air gap between the switch rear crimp terminals and the tallest PCB components, eliminating electrical flashover risks.

### 2.4 Thermal Dissipation
* The 8 Infineon BTS5008-1EKB PROFET smart switches utilize large continuous top and bottom copper pours interconnected with $0.3\,\text{mm}$ thermal vias.
* The PCB must be elevated on **M3 $\times$ 15 mm brass threaded standoffs** to permit convective airflow beneath the board.

---

## 3. Remote Wall Switch Panels (Bed & Living Area)

### 3.1 Dimensions & Form Factor
* **Outer Faceplate:** **86 mm $\times$ 86 mm** (standard European / Berker Integro RV switch plate footprint).
* **Overall Thickness:** **22 mm total depth** (housing the carrier PCB, Seeed Studio XIAO ESP32-C6, and 2x AA alkaline batteries).
* **Weight:** $\approx 110\,\text{g}$ (including batteries).

### 3.2 Mounting Modes
1. **Full Surface Mount (Recommended):**
   * Base plate fixed directly to the plywood wall with 4x countersunk $3.0 \times 12\,\text{mm}$ wood screws or **3M VHB 5952 automotive tape**.
   * Protrudes only 22 mm, preventing snagging in camper hallways.
2. **Semi-Recessed Mount:**
   * For 15 mm plywood wall panels, a shallow blind pocket of **55 mm $\times$ 55 mm $\times$ 12 mm** reduces external projection to just **10 mm**.

---

## 4. Dockable Magnetic Entrance / Porch Remote

### 4.1 Concept & Operational Overview
The sliding door entrance panel is engineered as a **dockable dual-purpose controller**:
* **Docked Mode:** Snaps magnetically into its wall cradle on the B-pillar or kitchen galley side. Functions as a permanent tactile entrance switch plate.
* **Handheld / Outdoor Mode:** Effortlessly detached with one hand to control porch lights, exterior awning lights, water pump, or execute a master shutdown from the campsite table, campfire, or outdoor shower.

```
DOCKABLE MAGNETIC ASSEMBLY (EXPLODED VIEW):
                                               +-------------------------+
                                               | HANDHELD REMOTE UNIT    |
                                               | - Seeed XIAO ESP32-C6   |
                                               | - 7-Button Diode Matrix |
                                               | - 2x AA Battery Bay     |
+--------------------------+                   | - 4x Ferrous Discs      |
| WALL CRADLE (FIXED)      |                   +-------------------------+
| - Screwed to Van Pillar  |        Snap Pull               |
| - 4x Neodymium N52 Discs | <====================>         v
| - Self-Centering Bezel   |        Snap Dock       [ Ergonomic Grip ]
+--------------------------+
```

### 4.2 Magnetic Retention & Vehicular Vibration Physics
* **Vibration Acceleration:** Off-road driving and washboard gravel roads induce accelerations exceeding $3.0\,g$ ($a \approx 30\,\text{m/s}^2$).
* **Retention Force Calculation:**
  For a remote mass $m = 0.12\,\text{kg}$, the inertial detachment force is:
  $$F_{inertial} = m \cdot a = 0.12\,\text{kg} \times 30\,\text{m/s}^2 = 3.6\,\text{N}$$
  Applying a safety factor $S_f = 2.5$ against road shocks:
  $$F_{retention} \ge 9.0\,\text{N} \quad (\approx 0.92\,\text{kgf})$$
* **Magnet Configuration:**
  * 4x **Neodymium N52 countersunk magnets** ($\varnothing 10\,\text{mm} \times 2\,\text{mm}$ thickness) positioned at the four corners of the wall cradle.
  * Combined magnetic attraction provides **$10.5\,\text{N}$ of holding force**, guaranteeing the remote will never rattle or dislodge during severe off-road driving, while allowing clean one-handed intentional detachment.
  * **Self-Centering Geometry:** The cradle incorporates a $3\,\text{mm}$ perimeter chamfered lip that physically guides the remote into perfect alignment upon proximity.

### 4.3 Zero Electrical Contacts (Corrosion-Free Design)
* Standard pogo-pin dock contacts rapidly corrode and pit in outdoor marine and humid van environments.
* Because the Seeed Studio XIAO ESP32-C6 consumes only **~15 µA in Deep Sleep**, the remote operates for **$>2.5$ years on 2x standard AA alkaline cells**.
* The dock contains **zero electrical contacts**—it is 100% mechanical and magnetic, making it immune to dust, rain, and oxidation.
* The battery hatch uses a toolless magnetic sliding cover for fast battery replacement without disassembling the enclosure.

### 4.4 Exterior Campsite Keypad Mapping (7-Button Matrix)
The 7-button diode binary matrix provides dedicated control tailored for outdoor camping:

| Button Index | Function | Remote Action | Central Channel Target |
| :---: | :--- | :--- | :--- |
| **0** | **Porch / Awning Light** | Click: Toggle / Hold: Dim | Aux 1 (12V High-Side PROFET) |
| **1** | **Entry Step / Puddle Light** | Click: Toggle ON/OFF | Aux 2 (12V High-Side PROFET) |
| **2** | **Kitchen Galley Lights** | Click: Toggle / Hold: Dim | Zone 2 (PWM 200 Hz) |
| **3** | **Cabin Main Ceiling Lights** | Click: Toggle / Hold: Dim | Zone 1 (PWM 200 Hz) |
| **4** | **Water Pump (Seaflo)** | Click: Toggle ON/OFF | Channel 4 (PROFET + Flyback) |
| **5** | **Ceiling Ventilation Fan** | Click: Toggle ON/OFF | Channel 8 (P-MOSFET) |
| **6** | **Master Night Shutdown** | Click: All Lights & Pump OFF | Global Central Safety Action |

### 4.5 RF Propagation & Open-Air ESP-NOW Range
* **Frequency:** 2.4 GHz ISM band, 802.11 DSSS/OFDM PHY.
* **Line-of-Sight Range (Outdoor Campsite):** **35 to 50 meters** line-of-sight using the integrated ceramic/PCB antenna of the XIAO ESP32-C6.
* **Penetration Range (Through closed van body/windows):** **15 to 25 meters**.
* **Protocol Resilience:** Includes automatic hardware retry (up to 5 attempts) and cryptographic replay protection.

---

## 5. 3D Printing & Manufacturing Guidelines

For DIY fabrication via 3D printing:

| Parameter | Central Enclosure | Remote Faceplates & Cradles |
| :--- | :--- | :--- |
| **Recommended Material** | **PETG** or **ABS / ASA** | **PETG** or **ASA** (UV & Heat resistant) |
| **Prohibited Material** | **PLA** (Warps at $>50^\circ\text{C}$ in hot van interiors) | **PLA** |
| **Layer Height** | $0.20\,\text{mm}$ (Structural) | $0.12\,\text{mm} - 0.16\,\text{mm}$ (Smooth finish) |
| **Infill Density** | $30\% - 40\%$ (Gyroid or Grid) | $25\%$ (Gyroid) |
| **Threaded Fasteners** | M3 $\times$ 4.0 mm brass heat-set inserts | M2.5 $\times$ 3.0 mm brass heat-set inserts |
| **Wall Perimeters** | 4 perimeters ($1.6\,\text{mm}$ wall thickness) | 3 perimeters ($1.2\,\text{mm}$ wall thickness) |

---

## 6. Parametric CAD Models & 3D Engineering Verification

All enclosures and cradles are generated programmatically using **`build123d` (Python Code-as-CAD on OpenCASCADE)** and verified with a custom headless **software Z-buffer rasterizer**.

### 6.1 Generated CAD Inventory

| Part Name | File (STEP / STL) | Outer Envelope ($X \times Y \times Z$) | Solid Volume | Key Engineering Features |
| :--- | :--- | :---: | :---: | :--- |
| **Central Enclosure Base** | [`central_enclosure_base.step`](../hardware/enclosures/models/central_enclosure_base.step) | $219.0 \times 127.2 \times 47.2\,\text{mm}$ | $166.6\,\text{cm}^3$ | Integrated M4 mounting ears, stepped alignment lip ($+2.2\,\text{mm}$), 4x gusseted M3 standoff towers, 4x PG9/PG11 gland collars, passive side vents. |
| **Central Enclosure Lid** | [`central_enclosure_lid.step`](../hardware/enclosures/models/central_enclosure_lid.step) | $175.0 \times 125.0 \times 18.0\,\text{mm}$ | $100.4\,\text{cm}^3$ | $3.5\,\text{mm}$ top wall, $1.5\,\text{mm}$ counterbore clamping shoulder, internal boss columns, perimeter mating groove, 5x SPDT keyway notches. |
| **Remote Enclosure Body** | [`remote_enclosure_body.step`](../hardware/enclosures/models/remote_enclosure_body.step) | $86.0 \times 86.0 \times 18.0\,\text{mm}$ | $39.6\,\text{cm}^3$ | $3.5\,\text{mm}$ floor ($1.4\,\text{mm}$ solid backing behind magnets), 4x edge-centered magnet pockets, 2x AA battery bay, 4x M2.5 corner bosses. |
| **Remote Faceplate** | [`remote_enclosure_faceplate.step`](../hardware/enclosures/models/remote_enclosure_faceplate.step) | $86.0 \times 86.0 \times 5.4\,\text{mm}$ | $33.4\,\text{cm}^3$ | Stepped alignment tongue, 4x M2.5 countersinks, 6x chamfered button apertures, recessed rotary dial pocket with anti-rotation tab, LED light cone. |
| **Magnetic Wall Cradle** | [`remote_magnetic_cradle.step`](../hardware/enclosures/models/remote_magnetic_cradle.step) | $96.0 \times 96.0 \times 11.0\,\text{mm}$ | $47.9\,\text{cm}^3$ | $45^\circ$ self-centering lead-in chamfer, **dual ergonomic finger extraction scallops** ($R=16\,\text{mm}$), 4x magnet pockets, 2x recessed wall countersinks. |

### 6.2 Automation Scripts & Skills
* **Parametric Generator:** [`hardware/enclosures/scripts/generate_enclosures.py`](../hardware/enclosures/scripts/generate_enclosures.py)
* **Software Z-Buffer Renderer:** [`hardware/enclosures/scripts/render_stl.py`](../hardware/enclosures/scripts/render_stl.py)
* **CAD Design Skill & Reference Standards:** [`.agents/skills/parametric-cad-enclosures/SKILL.md`](../.agents/skills/parametric-cad-enclosures/SKILL.md)

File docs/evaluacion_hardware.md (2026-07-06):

# Evaluación de Hardware: Módulos ESP32 y Técnicas de Multiplexación

Este documento evalúa las opciones para simplificar el hardware de control central de la van utilizando técnicas de multiplexación de pines (expansores I2C) y realiza una recomendación técnica comparativa sobre qué variantes del chip ESP32 (S3, C6, C3, Classic) son más adecuadas para cada componente del sistema.

---

## 1. Multiplexación de Salidas (¿Cómo reducir el uso de GPIOs?)

¡Sí, es totalmente posible y muy recomendable! De hecho, usar multiplexación o expansión por I2C en la unidad central es una práctica de diseño excelente por tres razones:

1.  **Reduce el número de pines necesarios** en el ESP32 de 11 a solo **2 pines** (SDA y SCL).
2.  **Protege al ESP32** contra transitorios de corriente o fallas en la etapa de potencia (si un canal falla catastróficamente, destruye el chip expansor de $2, no al microcontrolador principal).
3.  **Facilita el ruteado de la placa (PCB)** y permite ampliar canales en el futuro sin cambiar el controlador.

A continuación, se evalúan las dos mejores alternativas para expandir pines vía I2C:

### Opción A: PCA9685 (Controlador PWM de 16 Canales I2C) - ¡RECOMENDADO!

Este chip se comunica por I2C y ofrece 16 canales de salida con modulación por ancho de pulsos (PWM) por hardware de 12 bits de resolución.

- **Por qué es ideal para tu Van:**
  - **Atenuación nativa de luces:** Puedes controlar el brillo de las 4 zonas de luces LED de forma independiente y ultra suave sin consumir ciclos del procesador del ESP32.
  - **Control de todo tipo de cargas:** Además de PWM para luces, sus salidas pueden conmutar a ON/OFF digital puro (brillo 0% o 100%) para activar los PROFETs de la bomba de agua, ventiladores, o los optoacopladores del inversor.
  - **Solo consume 2 pines** del ESP32 (SDA/SCL).

### Opción B: MCP23017 (Expansor de E/S Digitales de 16 Canales I2C)

Este chip ofrece 16 pines que pueden configurarse individualmente como entradas o salidas digitales.

- **Limitación:** Solo maneja estados lógicos llanos (HIGH/LOW). No soporta PWM por hardware.
- **Uso:** Excelente si solo vas a usar relés mecánicos de encendido/apagado absoluto, pero no sirve para hacer atenuación progresiva en tus zonas de luces de forma eficiente.

---

## 2. Evaluación Comparativa de Módulos ESP32

Analizamos las cuatro principales variantes de SoC (System on Chip) de Espressif disponibles para determinar cuál se adapta mejor al gabinete eléctrico (Central) y a los paneles de pulsadores (Remotos).

| Característica | ESP32-C6 | ESP32-S3 | ESP32-C3 | ESP32 Classic (WROOM) |
| :--- | :--- | :--- | :--- | :--- |
| **Arquitectura** | RISC-V Single-core (160 MHz) | Xtensa LX7 Dual-core (240 MHz) | RISC-V Single-core (160 MHz) | Xtensa Dual-core (240 MHz) |
| **Conectividad** | Wi-Fi 6 (802.11ax), BLE 5.3, **Zigbee 3.0, Thread/Matter** | Wi-Fi 4, BLE 5.0 | Wi-Fi 4, BLE 5.0 | Wi-Fi 4, BLE 4.2 |
| **Pines GPIO (DevKit)** | ~22 pines | **~45 pines** | ~15 pines | ~25 pines |
| **Consumo Deep Sleep**  | **Excelente (~15 $\mu$A)** | Medio (~30-40 $\mu$A) | Excelente (~20 $\mu$A) | Alto (~100-150 $\mu$A) |
| **Formatos XIAO** | **Sí (Seeed Studio)** | Sí (Seeed Studio) | Sí (Seeed Studio) | No (Solo placas grandes) |
| **Soporte ESP-NOW** | Sí (con Wi-Fi 6) | Sí | Sí | Sí |

---

## 3. Recomendación Arquitectónica del Sistema

### A. Para los Módulos Remotos (Pulsadores)

- **Módulo Recomendado:** **Seeed Studio XIAO ESP32-C6**
- **Razón:**
  1.  **Consumo Ultra Bajo:** Al contar con la tecnología de procesamiento de Wi-Fi 6 y la arquitectura RISC-V, consume muy poca corriente en deep sleep (~15 $\mu$A). Tus 2 baterías AA durarán años.
  2.  **Tamaño Mini:** Con solo 17.5 x 21 mm, cabe perfectamente en el espacio interior de cualquier cajetín de interruptor de pared de la van.
  3.  **Futuro Matter/Zigbee:** Si decides integrar el sistema a un hub domótico Matter más adelante, el C6 ya tiene el transceptor de radio necesario (802.15.4) integrado físicamente.

### B. Para la Unidad Central (Gabinete Eléctrico) - ¡SELECCIONADO: Lonely Binary ESP32-S3 N16R8!

Se ha seleccionado el **Lonely Binary ESP32-S3 N16R8** para la unidad central debido a su facilidad de conexionado directo, alta calidad de fabricación (acabado de oro por inmersión) y gran capacidad de almacenamiento y memoria de trabajo (16MB Flash, 8MB PSRAM), descartando el uso de expansores de pines I2C en esta etapa.

- **Componentes:** 1x Lonely Binary ESP32-S3 N16R8.
- **Justificación de Consumo y Compatibilidad:**
  - **Consumo Diario Continuo (24/7):** Al ser un receptor, la central debe mantener su radio de Wi-Fi encendida en modo de escucha activo (Rx) constantemente. A 3.3V, el ESP32-S3 consume ~90 mA, mientras que el C6 consume ~50 mA. Pasado por un regulador buck eficiente (90%), el S3 consume **~0.66 Ah al día a 12V** (frente a los ~0.37 Ah del C6). Esta diferencia de ~0.29 Ah diarios es completamente despreciable en una batería de van típica de 100Ah-200Ah (menos del 0.3% diario).
  - **Compatibilidad ESP-NOW:** La comunicación inalámbrica cruzada entre el emisor (XIAO ESP32-C6, Wi-Fi 6) y el receptor (ESP32-S3, Wi-Fi 4) mediante ESP-NOW es **100% compatible nativamente**. El C6 baja automáticamente a modo de compatibilidad de tramas 802.11b/g/n para comunicarse.
  - **Simplicidad de Hardware:** Con más de 40 GPIOs disponibles en el S3, se conectan directamente todos los canales MOSFET, relés y optoacopladores sin necesidad de integrar un chip multiplexor PCA9685, reduciendo la complejidad del circuito y del firmware.

---

## 4. Próximos Pasos de Diseño (Con ESP32-S3 Central)

Al optar por el **ESP32-S3** para la unidad central:

1.  **Mapeo de Pines:** Definiremos las salidas GPIO directas del ESP32-S3 hacia las señales de control de los optoacopladores (para inversor/calefactor) y los módulos MOSFET (para iluminación y bomba).
2.  **Simplificación del Firmware:** El control se realizará mediante llamadas directas `digitalWrite()` y `ledcWrite()` (para atenuación PWM en canales de iluminación), eliminando la necesidad de gestionar el bus I2C y librerías externas de multiplexación.
3.  **Esquema en Atopile:** El diseño del hardware en Atopile conectará los pines del ESP32-S3 directamente a las etapas de potencia, facilitando la creación de la PCB final (placa base/carrier board) donde se pinchará el DevKitC.

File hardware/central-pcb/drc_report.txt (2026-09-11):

** Drc report for profet.kicad_pcb **
** Created on 2026-09-10T19:34:22 **
** Report includes: Errors **

** Found 0 DRC violations **

** Found 0 unconnected pads **

** Found 0 Footprint errors **

** Ignored checks **
    - Footprint has no courtyard defined
    - Track endpoint not centered on via
    - Tuning profile track geometries
    - Footprint doesn't match symbol's footprint filters
    - Footprint component type doesn't match footprint pads

** End of Report **

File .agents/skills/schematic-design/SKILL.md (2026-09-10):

---
name: schematic-design
description: >-
  Comprehensive guide and verification workflow for designing electronic schematics and Hardware-as-Code
  (Atopile, KiCad). Use when creating or auditing microcontroller carrier boards, automotive 12V/24V power entry,
  smart power switching stages (PROFETs/MOSFETs), precision ADC analog front-ends, or ultra-low-power deep sleep wake-up circuits.
---

# Electronic Schematic Design & Verification Guide

This skill provides a standardized, mathematically rigorous procedure for designing, auditing, and compiling electronic schematics, with specific emphasis on **Hardware-as-Code (Atopile)**, **Automotive 12V/24V Systems**, and **Low-Power Embedded Microcontrollers** (ESP32-S3, ESP32-C6).

---

## Core Principles

1. **Datasheet-First Verification:** Never trust third-party pinout graphics or AI hallucinated pin assignments. Always trace physical pin numbers to official manufacturer schematics and verify top vs. bottom board perspective.
2. **Safety & Automotive Hardening:** Every vehicle-connected DC rail must incorporate reverse polarity protection, transient voltage suppression (ISO 7637-2 / ISO 16750-2), and high-side switching.
3. **Impedance & Bandwidth Matching:** Match analog sensor output impedance to the microcontroller ADC sampling characteristics (R_Th ≤ 10 kΩ, reservoir capacitor C_f = 100 nF). Never clamp high-impedance ADC inputs with low-voltage Zener diodes.
4. **Compile-Time Hardware Constraints:** In Hardware-as-Code (Atopile), enforce programmatic assertions (`assert vcc != gnd`) to detect short circuits, inverted rails, and pin conflicts before PCB layout.

---

## Step-by-Step Schematic Design Workflow

```mermaid
flowchart TD
    A["1. Define Interfaces & Requirements"] --> B["2. Power Entry & Transient Architecture"]
    B --> C["3. Microcontroller Pinout & Carrier Board Mapping"]
    C --> D["4. Switching & Actuation Stages (PROFET / FET)"]
    D --> E["5. Analog Front-End & Clamping"]
    E --> F["6. Low-Power Wakeup Matrix"]
    F --> G["7. Compilation, DRC & Automated Netlist Audit"]
```

### Step 1: Power Entry & Automotive Protection
When designing 12V/24V automotive supplies:
1. **Reverse Polarity Protection:** Use a high-side P-Channel MOSFET with a 15V Zener clamp between Gate and Source to prevent gate oxide punch-through during load dumps.
   - Detailed guide: [automotive_power_entry.md](./references/automotive_power_entry.md)
2. **TVS Clamping (ISO 7637-2 / ISO 16750-2):**
   - Reverse Standoff Voltage: V_RWM ≥ 24 V (to survive 24V jump-starts).
   - Maximum Clamping Voltage: V_C ≤ 38 V (below the 41 V breakdown of downstream silicon).
   - Recommended part: DO-218AB automotive TVS (e.g., `SM8S24A` or `SLD8S24A`).
3. **Buck Converter π-Filter Damping:** Follow the Middlebrook Criterion to prevent negative input resistance oscillation. Add an electrolytic damping capacitor (C_d ≥ 4 · C_in2) with series damping resistor (R_d ≈ √(L / C_in2)).

---

### Step 2: Microcontroller Carrier Board & Pinout Mapping
When embedding commercial dev boards (e.g., ESP32-S3 DevKitC-1, Seeed XIAO ESP32-C6):
1. **Perspective Check:** Verify whether the datasheet pinout is **Top View** (looking at components) or **Bottom View** (looking at solder pins). Carrier board female headers interface with the bottom of the module.
2. **Atopile Architectural Separation:**
   - Define a generic physical header component (`Header_1x22`) with strict pin-to-pad bindings (`signal pin_1 ~ pin 1`).
   - Define semantic interfaces (`Power`, `UART`, `SPI`).
   - Connect the semantic signals to the physical header pins inside the module wrapper.
3. **Compile-Time Assertions:**
   ```ato
   assert power_5v.vcc != power_5v.gnd
   assert j1_left.pin_21 != j3_right.pin_1
   ```
4. Detailed guide: [hardware_as_code_atopile.md](./references/hardware_as_code_atopile.md)

---

### Step 3: Power Switching & PWM Limitations
When switching automotive loads (lights, pumps, fans):
1. **High-Side Switching Only:** Keep chassis ground direct. Use Smart High-Side Switches (Infineon PROFET+ BTS5008-1EKB) with integrated short-circuit, over-temperature, and active inductive clamping.
2. **PWM Frequency Calculation:**
   - Automotive PROFET switches intentionally throttle slew rates (dV/dt) for CISPR 25 Class 5 EMI compliance (t_ON, t_OFF ≈ 150 µs - 250 µs).
   - **Never operate PROFETs at standard 5 kHz PWM.** The period (200 µs) is shorter than the switching transition (500 µs), leading to thermal runaway.
   - **Mandatory PWM Frequency:** Configure firmware PWM between **100 Hz and 400 Hz** (nominally **200 Hz**).
3. **Current Sense (IS) Protection:** When a PROFET faults, the IS pin sources up to 7 mA, generating > 8 V across R_IS. Clamp the IS line to 3.3V using a dual Schottky diode (`BAT54S`) and a series resistor (R_series ≥ 2.2 kΩ).
4. Detailed guide: [power_switching_profet.md](./references/power_switching_profet.md)

---

### Step 4: Analog Front-End & ADC Protection
When measuring voltages with microcontroller SAR ADCs (e.g., ESP32 ADC):
1. **Avoid Low-Voltage Zener Diodes:** 3.3V Zener diodes (e.g., `BZX84-C3V3`) have a very soft knee and leak tens of microamps below breakdown. Across a 15 kΩ divider, this introduces a **≈ 5 V measurement error**!
2. **Use Schottky Rail Clamping:** Connect a `BAT54S` Schottky diode to the 3.3V rail. It provides sharp overvoltage clamping at V_DD + 0.3 V with negligible reverse leakage (< 100 nA).
3. **SAR ADC Reservoir Capacitor:** ESP32 ADCs draw instantaneous charge during sampling (C_sample ≈ 5 pF). Place a 100 nF ceramic capacitor directly at the ADC pin to buffer the sample-and-hold circuit and provide anti-aliasing.
4. Detailed guide: [analog_frontends.md](./references/analog_frontends.md)

---

### Step 5: Low-Power Deep Sleep Wake-Up Design
When designing battery-powered remotes (e.g., ESP32-C6):
1. **LP-GPIO vs. HP-GPIO Constraints:** In Deep Sleep, the High-Power (HP) domain is completely powered off. Only Low-Power (LP) GPIOs (GPIO 0–7) can wake the MCU via `EXT1`.
   - On the Seeed Studio XIAO ESP32-C6, header pins `D0`, `D1`, `D2` are LP-GPIOs. Header pin `D3` is GPIO 21 (HP-GPIO) and **cannot wake the chip**.
2. **Hardware Diode-OR Wakeup Matrix:**
   - If more physical buttons are needed than available LP-GPIO pins, route each button to an HP-GPIO for identification, and diode-OR all buttons through low-leakage Schottky/switching diodes (`1N4148W` or `BAT54C` in SOD-123) to a single shared LP-GPIO wake pin.
   - **Diode Polarity:** Connect Diode Anode to the shared `wakeup_bus` (pulled up to 3.3V via 47 kΩ) and Cathode to the button/switch sense line (pulled to GND upon activation).
   - **Debounce Filtering:** Include a 10 kΩ pull-up and 100 nF ceramic debounce capacitor per switch channel to eliminate mechanical contact bounce while maintaining zero deep-sleep leakage.
3. Detailed guide: [ultra_low_power_wakeups.md](./references/ultra_low_power_wakeups.md)

---

### Step 6: PCB 3D Rendering, Mechanical CAD Export & Fit Check
Before fabricating PCBs, verify component clearances, connector ergonomics, and enclosure mechanical fit:
1. **Raytraced 3D Render:** Run `kicad-cli pcb render` with perspective and floor shadows to inspect physical component spacing and silkscreen legibility.
2. **Populated 3D STEP Export:** Export board solid via `kicad-cli pcb export step --subst-models` and import into `build123d` enclosure models to verify standoff alignment and port clearances.
3. Detailed guide: [pcb_rendering_and_visualization.md](./references/pcb_rendering_and_visualization.md)

---

## Verification & Pre-Fabrication Checklist

Before ordering PCBs or committing schematic changes, verify every item in this checklist:

- [ ] **Physical Header Pinout:** Verified against the manufacturer's primary schematic PDF (not marketing pinout diagrams).
- [ ] **Power/GND Isolation:** Verified that V_IN and GND pins are not shorted or inverted on the carrier board.
- [ ] **Reverse Polarity Protection:** High-side P-MOSFET configured with Source to V_IN and Drain to Load, with 15V Zener across Gate-Source.
- [ ] **Load Dump TVS Rating:** DO-218AB TVS diode with V_RWM ≥ 24 V and V_C ≤ 38 V.
- [ ] **PROFET PWM Frequency:** Firmware configured for 100 Hz - 400 Hz (nominally 200 Hz).
- [ ] **PROFET IS Clamp:** Dual Schottky diode (`BAT54S`) clamping IS to 3.3V with R_series ≥ 2.2 kΩ.
- [ ] **ADC Divider Impedance:** Thévenin resistance R_Th ≤ 15 kΩ with a 100 nF ceramic reservoir capacitor at the MCU pin.
- [ ] **No Low-Voltage Zeners:** No 3.3V Zeners on high-impedance analog lines.
- [ ] **Deep Sleep Wakeup Pins:** All wake switches connected exclusively to LP-GPIOs (or diode-ORed to an LP-GPIO).
- [ ] **Atopile Compilation:** `ato build` passes with zero errors and electrical checks validated.

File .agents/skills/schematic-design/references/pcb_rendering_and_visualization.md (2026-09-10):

# PCB Rendering, 3D Visualization, and Mechanical CAD Export

This guide documents the engineering workflow for generating photorealistic 3D raytraced renders, 2D vector silkscreen assembly drawings, and populated 3D STEP CAD models from KiCad / Atopile PCB designs.

---

## 1. Overview & Architecture

Modern electronic hardware development requires visual and mechanical verification before sending boards to fabrication (Gerbers/BOM/Pick-and-Place):
1. **Photorealistic 3D Raytracing:** Visual inspection of component placements, clearance between connectors, polarity markings, and aesthetic appearance (solder mask color, silkscreen readability).
2. **Mechanical CAD Assembly Integration:** Populated 3D STEP board export for direct import into enclosure CAD models (`build123d` / FreeCAD / OpenCASCADE) to verify standoff heights, connector aperture cutouts, and wire bend radii.
3. **Vector Assembly Documentation:** High-resolution SVG/PNG 2D engineering drawings for assembly manuals and field wiring diagrams.

```mermaid
flowchart LR
    A["Atopile Circuit Design<br/>(central.ato)"] -->|ato build| B["KiCad PCB Layout<br/>(*.kicad_pcb)"]
    B -->|kicad-cli pcb render| C["Photorealistic 3D Renders<br/>(PNG 1440p/4K)"]
    B -->|kicad-cli pcb export step| D["Populated 3D STEP Model<br/>(*.step)"]
    B -->|kicad-cli pcb export svg| E["Vector Silkscreen Drawing<br/>(*.svg)"]
    D -->|import_step()| F["Enclosure CAD Validation<br/>(build123d Assembly)"]
```

---

## 2. Tooling & Headless Execution

KiCad provides the `kicad-cli` tool for headless batch rendering on Linux workstations, CI/CD pipelines, and containerized environments.

### 2.1 Invocation (Native vs Flatpak)
When KiCad is installed via Flatpak (`org.kicad.KiCad`), execute `kicad-cli` inside the Flatpak sandbox:

```bash
# Native binary
kicad-cli pcb render [options] <file.kicad_pcb>

# Flatpak binary
flatpak run --command=kicad-cli org.kicad.KiCad pcb render [options] <file.kicad_pcb>
```

The automated script [`hardware/central-pcb/scripts/render_pcb.py`](../../../hardware/central-pcb/scripts/render_pcb.py) automatically discovers whether KiCad CLI is installed natively or via Flatpak.

---

## 3. Photorealistic 3D Raytracing (`pcb render`)

KiCad's internal raytracing engine builds bounding volume hierarchy (BVH) trees for pads, copper traces, and 3D component meshes, rendering realistic lighting, ambient occlusion, reflections, and contact shadows.

### 3.1 Recommended CLI Command for Isometric Perspective
```bash
flatpak run --command=kicad-cli org.kicad.KiCad pcb render \
  --output hardware/central-pcb/renders/profet_isometric.png \
  --rotate -50,0,40 \
  --perspective \
  --floor \
  --use-board-stackup-colors \
  --quality high \
  --width 2560 \
  --height 1440 \
  hardware/central-pcb/layouts/profet/profet.kicad_pcb
```

### 3.2 Key Parameters Explained

| Parameter | Recommended Value | Engineering Purpose |
| :--- | :--- | :--- |
| `--rotate` | `-50,0,40` | Sets camera rotation (pitch, yaw, roll) to standard 3/4 isometric perspective. |
| `--perspective` | Flag present | Replaces orthographic parallel projection with real camera perspective (depth foreshortening). |
| `--floor` | Flag present | Generates a neutral ground plane with soft contact shadows beneath the board. |
| `--use-board-stackup-colors` | Flag present | Renders the exact solder mask color (e.g., Matte Black, Purple, Blue) and pad finish (ENIG gold / HASL silver) specified in the board stackup setup. |
| `--quality` | `high` | Enables multi-sample anti-aliasing, soft shadow penumbras, and post-processing shaders. |
| `--side` | `top` or `bottom` | Generates pure orthographic inspection projections (no rotation). |
| `--width / --height` | `2560x1440` (1440p) | High pixel density for sharp silkscreen text and package details. |

---

## 4. Board Outline (`Edge.Cuts`) Requirements

If a `.kicad_pcb` file lacks an explicit closed polygon on the `Edge.Cuts` layer:
- KiCad CLI outputs: `Warning: Board outline is missing or malformed. Run DRC for a full analysis.`
- KiCad defaults the board substrate to an arbitrary bounding box surrounding all footprints, causing ragged or oversized board edges.

### 4.1 Defining Clean Board Outlines
A proper PCB boundary is defined on the `Edge.Cuts` layer. In S-expression syntax:
```scheme
(gr_rect (start 18 18) (end 292 172)
    (stroke (width 0.15) (type solid))
    (fill none)
    (layer "Edge.Cuts")
    (uuid "00000000-edge-cuts-rect-000000000001")
)
```

### 4.2 Integrated Mounting Holes
Physical through-holes (for M3 mounting screws) can be placed directly on `Edge.Cuts`:
```scheme
(gr_circle (center 24 24) (end 25.6 24)
    (stroke (width 0.15) (type solid))
    (fill none)
    (layer "Edge.Cuts")
    (uuid "00000000-edge-cuts-hole-000000000001")
)
```
In 3D raytracing, these circles are rendered as true physical cutouts, allowing light and floor reflections to pass through.

---

## 5. 3D STEP Export for Mechanical Enclosure Assembly

To verify that connectors clear enclosure apertures and that PCB mounting holes align with enclosure standoffs, export the board as a STEP solid:

```bash
flatpak run --command=kicad-cli org.kicad.KiCad pcb export step \
  --output hardware/central-pcb/renders/profet.step \
  --subst-models \
  hardware/central-pcb/layouts/profet/profet.kicad_pcb
```

### 5.1 Verification in Python Code-as-CAD (`build123d`)
The exported STEP model can be imported directly into `build123d` scripts:
```python
from build123d import *

# 1. Import enclosure base
enclosure = import_step("hardware/enclosures/models/central_enclosure_base.step")

# 2. Import populated PCB assembly
pcb = import_step("hardware/central-pcb/renders/profet.step")

# 3. Position PCB onto 12mm standoffs (standoff_z = floor + 12mm)
pcb_mounted = pcb.locate(Location((0, 0, 15.5)))

# 4. Check for interference
collision = enclosure.intersect(pcb_mounted)
assert collision.volume == 0, f"Interference detected: volume = {collision.volume} mm3"
```

---

## 6. 2D Vector Silkscreen & Fabrication Plots

For production manuals, assembly verification, and wiring cheat-sheets, generate vector SVGs:

```bash
# Export single SVG with copper, silkscreen, soldermask, and board edge
flatpak run --command=kicad-cli org.kicad.KiCad pcb export svg \
  --mode-single \
  --layers F.Cu,F.SilkS,F.Mask,Edge.Cuts \
  --exclude-drawing-sheet \
  --page-size-mode 2 \
  -o hardware/central-pcb/renders/profet_silkscreen.svg \
  hardware/central-pcb/layouts/profet/profet.kicad_pcb

# Rasterize to 300 DPI PNG
magick -density 300 hardware/central-pcb/renders/profet_silkscreen.svg hardware/central-pcb/renders/profet_silkscreen.png
```

---

## 7. Project Automated Script

To render all boards and views in one step, use the project script:

```bash
# Render all views for PROFET design
python3 hardware/central-pcb/scripts/render_pcb.py --board profet

# Render all views for both PROFET and Modular designs
python3 hardware/central-pcb/scripts/render_pcb.py --board all
```

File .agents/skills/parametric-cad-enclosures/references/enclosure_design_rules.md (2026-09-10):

# Mechanical Enclosure Design Rules & Sizing Standards

This reference establishes engineering design rules, sizing standards, and clearance requirements for automotive and electronics enclosures fabricated via 3D printing (FDM / SLA) or plastic injection molding.

---

## 1. Wall Thickness Guidelines

| Application | Recommended Wall ($T_{wall}$) | Floor Thickness ($T_{floor}$) | Rationale |
| :--- | :--- | :--- | :--- |
| **Small Handheld Remote (86x86mm)** | $2.5\,\text{mm}$ | $3.5\,\text{mm}$ | Houses $2.1\,\text{mm}$ magnet pockets while preserving $1.4\,\text{mm}$ solid backing. |
| **Central Power Cabinet (175x125mm)** | $3.0\,\text{mm}$ | $3.5\,\text{mm}$ | Structural rigidity under automotive vibration; supports PG cable gland torque. |
| **Docking / Wall Cradle (96x96mm)** | $2.5\,\text{mm}$ | $4.5\,\text{mm}$ | Allows deep countersinks for wall mounting screws flush below pocket floor. |

---

## 2. Fastener Stackup & Counterbore Land Thickness

### The Failure Mode
If a screw counterbore is modeled too deep relative to the wall thickness, the remaining plastic shoulder under the screw head is paper-thin. Under screw torque or vehicle vibration, the screw head punches through the wall, dropping the lid.

```
         ┌───────────────────┐               ▲
         │                   │               │
    ─────┘                   └─────          │ Wall Thickness (3.5 mm)
      │  ▲ Counterbore (2.0mm) │             │
      │  ▼                     │             ▼
    ──┼────────────────────────┼───          ─
      │  Solid Shoulder (1.5mm)│             ▲
    ──┴────────────────────────┴───          ▼
```

### The Rule
$$\text{Clamping Shoulder} = T_{wall} - D_{counterbore} \ge 1.5\,\text{mm}$$

For M3 Socket Head Cap Screws (DIN 912):
* Head Diameter: $5.5\,\text{mm} \implies \text{Counterbore Diameter} = 6.2\,\text{mm}$
* Counterbore Depth: $2.0\,\text{mm}$
* Minimum Top Wall Thickness: $3.5\,\text{mm}$ (leaves $1.5\,\text{mm}$ solid shoulder)
* Through Hole: $3.4\,\text{mm}$ (free fit)

---

## 3. Brass Threaded Heat-Set Insert Sizing

Never screw metal fasteners directly into raw plastic for reusable panels. Heat-set inserts flow plastic into external helical knurls, yielding high pull-out ($>1.2\,\text{kN}$) and torque resistance.

```
         Boss Outer Dia (D_boss)
       ◄─────────────────────────►
       ┌─────┬─────────────┬─────┐
       │     │  Insert ID  │     │
       │     │ ◄── D_pilot ──►   │
       │     │             │     │
       │     │             │     │ ▲ Insert Depth + 1.0mm
       │     │             │     │ ▼
       │     └──────┬──────┘     │
       │            │ Solid Land │ ▲ Min 1.5mm
       └────────────┴────────────┘ ▼
```

* **M3 Standard Insert (Ruthex / McMaster M3x5.7):**
  * $D_{pilot} = 4.0 - 4.1\,\text{mm}$
  * $H_{hole} = 6.0\,\text{mm}$ ($0.3 - 0.5\,\text{mm}$ deeper than insert to capture displaced plastic)
  * $D_{boss} \ge 2.0 \cdot D_{pilot} \approx 8.0 - 8.5\,\text{mm}$
* **M2.5 Small Insert (Ruthex M2.5x4.0):**
  * $D_{pilot} = 3.4 - 3.5\,\text{mm}$
  * $H_{hole} = 4.5\,\text{mm}$
  * $D_{boss} \ge 6.5 - 7.0\,\text{mm}$

---

## 4. Interlocking Stepped Perimeter Joint (Lip-and-Groove)

Flat butt-joints between base and lid allow dust/spray ingress, light bleed, and lateral shifting. Every enclosure assembly must use an interlocking stepped flange:

```
        LID
      ┌─────────────────────────┐
      │  ┌───────────────────┐  │
      │  │                   │  │
      └──┼──────┐     ┌──────┼──┘
         │ 0.2mm│     │0.2mm │
         │ Gap  │     │Gap   │
      ┌──┼──────┘     └──────┼──┐
      │  │                   │  │
      │  └───────────────────┘  │
      └─────────────────────────┘
        BASE
```

* **Tongue Width ($W_{tongue}$):** $1.3 - 1.5\,\text{mm}$
* **Tongue Height ($H_{tongue}$):** $2.0 - 2.5\,\text{mm}$
* **Groove Width ($W_{groove}$):** $W_{tongue} + 2 \cdot \text{Tolerance} \approx 1.7 - 1.9\,\text{mm}$
* **Tolerance Gap:** $0.2\,\text{mm}$ per side for FDM 3D printing; $0.1\,\text{mm}$ for SLA / injection molding.

---

## 5. Ergonomic Magnetic Cradle Design

When mounting dockable remotes using strong NdFeB magnets (e.g. 4x N52 magnets generating $17.6\,\text{N}$ holding force):
1. **The Extraction Problem:** If a flush remote sits in a deep snug pocket with $0.4\,\text{mm}$ clearance, user fingers cannot grip any surface. Extracting the unit requires prying with a screwdriver or blade.
2. **The Solution:**
   * **Dual Finger Scallops:** Two semicircular grip reliefs ($R \ge 14\,\text{mm}$, depth $\ge 6.0\,\text{mm}$) cut through the side walls of the cradle pocket.
   * **Self-Centering Lead-In Chamfer:** A $45^\circ$ lead-in taper ($1.5 - 2.0\,\text{mm}$) around the top rim guides the remote blindly into position as magnetic attraction engages.

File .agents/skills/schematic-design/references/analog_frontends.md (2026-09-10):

# Analog Front-Ends: Battery Telemetry & ADC Protection

Precision analog sensing on microcontrollers requires careful impedance matching and protection against high-voltage transients. This guide details design rules for measuring battery voltages using SAR ADCs (such as ESP32-S3 and ESP32-C6).

---

## 1. High-Precision Battery Divider Front-End

```
High-Precision Battery Telemetry Front-End:
                                                         3.3V Rail
                                                            ^
                                                            |
                                                        [ D_clamp: BAT54S ]
                                                            |
 V_BAT (+12V) ---[ R_high: 100k ]---+---[ R_series: 1k ]----+---> ESP32 ADC (GPIO1)
                                    |                       |
                             [ R_low: 18k ]            [ C_f: 100nF ]
                                    |                       |
                                   GND                     GND
```

---

## 2. Divider Sizing & Thévenin Source Impedance

### 2.1 Voltage Ratio
To scale an automotive battery voltage ($V_{BAT,\max} = 18.0\,\text{V}$) into the linear dynamic range of the ESP32 ADC ($V_{ADC} \le 2.45\,\text{V}$ with 11 dB attenuation):
$$K = \frac{R_{low}}{R_{high} + R_{low}} = \frac{18\,\text{k}\Omega}{100\,\text{k}\Omega + 18\,\text{k}\Omega} = 0.1525$$
At nominal float charge ($V_{BAT} = 14.4\,\text{V}$):
$$V_{ADC} = 14.4 \times 0.1525 = 2.20\,\text{V}$$

### 2.2 Thévenin Resistance
$$R_{Th} = R_{high} \parallel R_{low} = \frac{100\,\text{k}\Omega \times 18\,\text{k}\Omega}{118\,\text{k}\Omega} = 15.25\,\text{k}\Omega$$

---

## 3. SAR ADC Switched-Capacitor Settling & The Reservoir Capacitor

ESP32 SAR ADCs use a switched-capacitor track-and-hold circuit:
- Sampling capacitor: $C_{sample} \approx 2\,\text{pF} - 5\,\text{pF}$
- Internal switch resistance: $R_{sw} \approx 1\,\text{k}\Omega - 2\,\text{k}\Omega$
- Sampling window: $t_{sample} \approx 1\,\mu\text{s} - 2\,\mu\text{s}$

### 3.1 The Sampling Error
During the $1\,\mu\text{s}$ sampling window, $C_{sample}$ must charge to within $\frac{1}{2}\,\text{LSB}$ ($0.012\%$) of the input voltage:
$$e^{-t_{sample} / \tau} \le \frac{1}{8192} \implies t_{sample} \ge 9.0 \cdot \tau$$
$$\tau = (R_{source} + R_{sw}) \cdot C_{sample}$$
If $R_{source} = 15.25\,\text{k}\Omega$, $\tau = (15.25\,\text{k}\Omega + 1.5\,\text{k}\Omega) \times 5\,\text{pF} = 83.7\,\text{ns} \implies 9\tau \approx 753\,\text{ns}$.
While close, any multiplexer switching transient or parasitic trace capacitance causes gain error and cross-channel crosstalk.

### 3.2 The Reservoir Capacitor Solution
Placing a **$100\,\text{nF}$ ceramic capacitor ($C_f$)** directly at the ADC pin:
1. **Charge Reservoir:** $C_f = 100\,\text{nF} \gg 8192 \cdot C_{sample} = 41\,\text{nF}$.
   $C_{sample}$ draws its sampling charge directly from $C_f$ in nanoseconds. The voltage droop on $C_f$ is negligible:
   $$\Delta V = V_{in} \cdot \frac{C_{sample}}{C_f + C_{sample}} = 2.2\,\text{V} \times \frac{5\,\text{pF}}{100\,\text{nF}} = 0.11\,\text{mV} \quad (< 0.15\,\text{LSB})$$
2. **Anti-Aliasing Filter:**
   $$f_c = \frac{1}{2\pi \cdot R_{Th} \cdot C_f} = \frac{1}{2\pi \times 15.25\,\text{k}\Omega \times 100\,\text{nF}} \approx 104.3\,\text{Hz}$$
   This completely suppresses 1 kHz – 3 kHz alternator ripple and high-frequency noise from buck converters.

---

## 4. Why Low-Voltage Zener Diodes Ruin ADC Accuracy

### 4.1 Quantum Tunneling vs. Avalanche Breakdown
- **Diodes with $V_Z > 5.6\,\text{V}$ (Avalanche):** Sharp knee, sub-nanoamp leakage ($I_R < 1\,\text{nA}$) below breakdown.
- **Diodes with $V_Z < 5.1\,\text{V}$ (Zener):** Dominated by quantum tunneling across an ultra-thin barrier. They have a **soft, rounded knee** with massive sub-breakdown leakage.

### 4.2 Quantitative Failure Case: 3.3V Zener (`BZX84-C3V3`)
At a normal measurement level ($V_{ADC} \approx 2.1\,\text{V} - 2.3\,\text{V}$), the BZX84-C3V3 leaks **$30\,\mu\text{A}$ to $60\,\mu\text{A}$**.

Across $R_{Th} = 15.25\,\text{k}\Omega$:
$$\Delta V_{ADC\_drop} = 50\,\mu\text{A} \times 15.25\,\text{k}\Omega = 0.7625\,\text{V}$$
Reflected back to the 12V battery reading ($K^{-1} = 6.556$):
$$\Delta V_{BAT\_error} = 0.7625\,\text{V} \times 6.556 \approx \mathbf{5.0\,\text{V}!}$$

> [!CAUTION]
> A 3.3V Zener diode will cause a healthy 14.4V battery to read as **$\approx 9.4\,\text{V}$**, falsely triggering low-voltage cutoffs. Because Zener leakage varies exponentially with ambient temperature, software calibration is mathematically impossible. **Never place low-voltage Zeners on ADC inputs.**

---

## 5. Correct Rail Clamping (BAT54S)

To protect the ADC against continuous overvoltage ($V_{BAT} > 24\,\text{V}$):
1. Use a dual Schottky diode (**BAT54S**) connected between GND and the 3.3V power rail.
2. Forward voltage $V_f \approx 0.32\,\text{V}$ clamps positive transients to $3.3\,\text{V} + 0.32\,\text{V} = 3.62\,\text{V}$, strictly within the ESP32 absolute maximum rating ($V_{DD} + 0.3\,\text{V}$).
3. Reverse leakage of BAT54 is $<100\,\text{nA}$ at $25^\circ\text{C}$, introducing an error of $<1.5\,\text{mV}$ ($<2\,\text{LSB}$).
4. Series resistor $R_{series} = 1\,\text{k}\Omega$ limits fault current injected into the 3.3V rail.

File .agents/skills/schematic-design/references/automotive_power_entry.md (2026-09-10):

# Automotive 12V DC Power Entry & Transient Protection

Vehicular 12V electrical systems (nominal 13.8V, charging up to 14.4V) present one of the harshest electrical environments in electronics design. Circuitry must withstand continuous voltage fluctuations, inductive kicks, and alternator load dump surges governed by **ISO 7637-2:2011** and **ISO 16750-2:2012**.

---

## 1. Power Entry Block Diagram

```
+12V VEHICLE BATTERY
        |
     [ FUSE ] (15A - 30A Fast Blow)
        |
        v
+-------+-----------------------------------------------------------+
| REVERSE POLARITY PROTECTION (P-MOSFET)                            |
|       +---[ Source ]---[ P-FET ]---[ Drain ]----+----> +12V_PROT  |
|       |                  |                    |                   |
|      [Z1] 15V Zener     [R_G] 100k            |                   |
|       |                  |                    |                   |
|       +--------+---------+                    |                   |
|                |                              |                   |
|               [R1] 10k                        |                   |
|                |                              |                   |
+----------------+------------------------------+                   |
                 |                                                  |
                GND                                                 v
+-------------------------------------------------------------------+
| TRANSIENT SUPPRESSION (TVS)                                       |
|       +12V_PROT ---+---> To PROFETs (BTS5008-1EKB)                |
|                    |                                              |
|                  [TVS] Automotive DO-218AB (SM8S24A)              |
|                    |   (V_RWM = 24V, V_C = 38.9V)                 |
|                   GND                                             |
+--------------------+----------------------------------------------+
                     |
                     v
+-------------------------------------------------------------------+
| LC PI-FILTER & MIDDLEBROOK DAMPING (CISPR 25)                     |
|       +12V_PROT ---[ L1 10uH ]---+------------+---> BUCK VIN      |
|                                  |            |     (MP1584EN)    |
|                                [C_in1]      [C_d] 47uF (Elec)     |
|                                10uF X7R       |                   |
|                                (50V)        [R_d] 1.0 Ohm         |
|                                  |            |                   |
|                                 GND          GND                  |
+-------------------------------------------------------------------+
```

---

## 2. Reverse Polarity Protection

### 2.1 Comparison: Schottky Diode vs. P-MOSFET

| Parameter | Series Schottky Diode (e.g., MBR1045) | High-Side P-MOSFET (e.g., DMP3010LK3) |
| :--- | :--- | :--- |
| **Forward Drop ($V_f$)** | $0.4\,\text{V} - 0.7\,\text{V}$ | $I_L \cdot R_{DS(\text{on})} \approx 0.05\,\text{V}$ |
| **Power Dissipation at 10A** | $5.0\,\text{W} - 7.0\,\text{W}$ (Hot, needs heatsink) | $0.5\,\text{W} - 1.0\,\text{W}$ ($R_{DS(\text{on})} = 8\,\text{m}\Omega$) |
| **High Temperature Leakage** | Severe risk of thermal runaway ($I_R > 30\,\text{mA}$ at $125^\circ\text{C}$) | Completely safe; channel held off by gate oxide |

### 2.2 P-MOSFET Implementation & Gate Oxide Protection
- **Orientation:** Connect **Source to Input ($V_{IN}$)** and **Drain to Protected Rail ($V_{PROT}$)**.
- **Normal Operation:** When $+12\,\text{V}$ is connected, current flows through the P-FET body diode, pulling Source to $11.3\,\text{V}$. Resistor $R_1$ pulls the Gate toward GND. $V_{GS}$ drops to $-11.3\,\text{V}$, driving the MOSFET into full saturation and shorting out the body diode ($V_{DS} \approx 0\,\text{V}$).
- **Reverse Connection:** When $-12\,\text{V}$ is connected to $V_{IN}$, Source is at $-12\,\text{V}$ while Gate is at $0\,\text{V}$ via $R_1$. Thus $V_{GS} > 0\,\text{V}$. The MOSFET channel remains off, and the body diode is reverse-biased, blocking all reverse current.
- **Critical Gate Breakdown Rule ($V_{GS,\max}$):**
  - MOSFET gate oxide ruptures at $V_{GS} > 20\,\text{V}$.
  - During automotive load dump surges ($+35\,\text{V}$ to $+40\,\text{V}$), grounding the Gate directly would apply $V_{GS} = -35\,\text{V}$, destroying the MOSFET instantly.
  - **Mandatory Protection:** Place a **15V Zener diode ($Z_1$)** between Gate and Source, and a $10\,\text{k}\Omega$ resistor ($R_1$) from Gate to GND. The Zener clamps $V_{GS}$ safely to $-15\,\text{V}$.

---

## 3. Transient Voltage Suppression (TVS) for ISO 7637-2 / ISO 16750-2

Vehicular transient standards:
- **ISO 7637-2 Pulse 1 (Inductive kick):** $-100\,\text{V}$ to $-150\,\text{V}$, $2\,\text{ms}$ duration.
- **ISO 7637-2 Pulse 2a (Harness inductance):** $+37\,\text{V}$ to $+55\,\text{V}$, $50\,\mu\text{s}$ duration.
- **ISO 16750-2 Pulse 5b (Suppressed Load Dump):** Alternator voltage surge clamped to $35\,\text{V}$, $40 - 400\,\text{ms}$ duration.

### 3.1 TVS Selection Criteria
1. **Reverse Standoff Voltage ($V_{RWM}$):** Must be $\ge 24\,\text{V}$ to prevent conduction during emergency 24V jump-start events.
2. **Maximum Clamping Voltage ($V_C$):** Must be strictly below the maximum breakdown voltage of downstream silicon:
   - Infineon PROFET BTS5008-1EKB active clamp: $V_{S(AZ)} = 41\,\text{V}$. The external TVS **must clamp below 39V** to prevent the PROFET from absorbing the vehicle's entire load dump energy.
3. **Recommended Component:**
   - **SM8S24A** or **SLD8S24A** (DO-218AB package, $6600\,\text{W}$ peak pulse power, $V_{RWM} = 24\,\text{V}$, $V_{BR} = 26.7\,\text{V} - 29.5\,\text{V}$, $V_C = 38.9\,\text{V}$ at peak surge).

---

## 4. Buck Converter $\pi$-Filter & Middlebrook Stability Criterion

Switching buck regulators behave as **constant-power loads**, which exhibit a negative incremental input resistance:
$$R_{in\_neg} = -\frac{V_{IN}^2 \cdot \eta}{P_{OUT}}$$
For $V_{IN} = 12\,\text{V}$, $P_{OUT} = 15\,\text{W}$ (5V at 3A), $\eta = 0.85$:
$$R_{in\_neg} = -\frac{144 \times 0.85}{15} = -8.16\,\Omega$$

### 4.1 Filter Damping Requirement
An undamped LC $\pi$-filter with ceramic MLCC capacitors has an impedance peak:
$$Z_{out,peak} = Q \cdot \sqrt{\frac{L}{C_{in}}}$$
High-$Q$ ceramic capacitors can produce $Z_{out,peak} > 40\,\Omega$. When $\|Z_{out,filter}\| \ge \|R_{in\_neg}\|$, the circuit oscillates, resulting in output ripple, audible whining, or buck regulator shutdown.

### 4.2 Solution: RC Parallel Damping
Add an electrolytic damping capacitor $C_d$ with series damping resistance $R_d$:
$$C_d \ge 4 \cdot C_{in2} \approx 47\,\mu\text{F}$$
$$R_d \approx \sqrt{\frac{L}{C_{in2}}} \approx 1.0\,\Omega$$
This clamps the maximum filter output impedance to $R_d \approx 1\,\Omega \ll 8.16\,\Omega$, ensuring unconditional stability.

---

## 5. MLCC Ceramic Capacitor DC Bias Derating

Class II MLCC dielectrics (X5R, X7R) experience drastic capacitance loss under DC bias voltage:
- A $10\,\mu\text{F}$, 25V 0805 X7R capacitor loses **$60\% - 75\%$** of its capacitance at 14V DC (actual effective capacitance $C_{eff} \approx 2.5\,\mu\text{F} - 3.5\,\mu\text{F}$).
- **Design Rule:** Always specify capacitors rated for **$\ge 50\,\text{V}$** on 12V/14V automotive lines, and choose 1206 or 1210 package sizes for bulk filtering.

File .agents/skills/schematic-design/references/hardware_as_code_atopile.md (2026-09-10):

# Hardware-as-Code (Atopile / KiCad) Module Definitions & Pinout Integrity

This guide establishes strict architectural and verification rules for defining microcontroller carrier boards and module interfaces in Atopile and KiCad.

---

## 1. The Anatomy of Carrier Board Pinout Failures

Carrier board integration commonly suffers from three fatal errors:

1. **Perspective / Mirroring Inversion:**
   - Datasheets typically draw breakout modules from the **Top View** (looking down on ICs and LEDs).
   - The carrier board mates with the module via female pin headers mounted on the top layer of the carrier PCB.
   - The carrier board female sockets interface with the **bottom pins** of the module.
   - If a designer lays out female sockets using a top-view diagram without accounting for mating orientation, the pinout becomes mirrored or inverted, leading directly to $V_{CC}$-to-GND shorts upon module insertion.
2. **Sequential vs. Dual-Row Numbering Inconsistencies:**
   - Single-row headers use consecutive 1-to-$N$ numbering.
   - Dual-row headers vary between zig-zag numbering (Pin 1 opposite Pin 2) and perimeter numbering (Pin 1 to $N/2$ along one side, $N/2+1$ to $N$ along the other).
3. **Board Revision & Source Drift:**
   - Unofficial third-party pinout graphics frequently confuse revisions (e.g., Espressif ESP32-S3-DevKitC-1 v1.0 vs. v1.1 where Pin 1 of J3 transitioned from 3V3 to GND).
   - In the Seeed Studio XIAO family, XIAO ESP32-C3 maps pin `D3` to GPIO 3, whereas XIAO ESP32-C6 maps pin `D3` to GPIO 21 (since GPIO 3 is consumed internally by the Wi-Fi 6 RF switch).

---

## 2. Robust Atopile Architecture Pattern

To prevent pin mapping bugs, Atopile code must decouple the **physical connector** from the **logical module**, using explicit signal aliases and compile-time assertions.

### 2.1 The 3-Tier Layered Design Pattern

```ato
# ==============================================================================
# TIER 1: Physical Primitive Header Connector (Strict 1-to-N pin binding)
# ==============================================================================
component Header_1x22:
    trait is_atomic_part<manufacturer="Generic", partnumber="PinSocket_1x22_2.54mm">
    signal pin_1 ~ pin 1
    signal pin_2 ~ pin 2
    signal pin_3 ~ pin 3
    signal pin_4 ~ pin 4
    # ...
    signal pin_21 ~ pin 21
    signal pin_22 ~ pin 22

# ==============================================================================
# TIER 2: Semantic Interface Abstractions
# ==============================================================================
interface Power:
    signal vcc
    signal gnd

interface UART:
    signal tx
    signal rx

# ==============================================================================
# TIER 3: Semantic Module Wrapper
# ==============================================================================
module ESP32_S3_DevKitC_v1_1:
    # Physical hardware connectors (Sockets on carrier PCB)
    j1_left = new Header_1x22
    j3_right = new Header_1x22

    # Power Interfaces
    power_5v = new Power
    power_3v3 = new Power

    # J1 (Left Header) Pin Mapping (Espressif Official Schematic v1.1)
    power_3v3.vcc ~ j1_left.pin_1
    power_5v.vcc  ~ j1_left.pin_21
    power_5v.gnd  ~ j1_left.pin_22
    power_3v3.gnd ~ j1_left.pin_22

    # J3 (Right Header) Pin Mapping
    # Pin 1 = GND, Pin 21 = GND, Pin 22 = GND
    j3_right.pin_1  ~ power_5v.gnd
    j3_right.pin_21 ~ power_5v.gnd
    j3_right.pin_22 ~ power_5v.gnd

    # IO Aliases (Matching exact schematic nets)
    signal gpio1  ~ j3_right.pin_4
    signal gpio2  ~ j3_right.pin_5
    signal gpio21 ~ j3_right.pin_18

    # --------------------------------------------------------------------------
    # Compile-Time HaC Assertions
    # --------------------------------------------------------------------------
    assert power_5v.vcc != power_5v.gnd
    assert power_3v3.vcc != power_3v3.gnd
    assert j1_left.pin_21 != j3_right.pin_1
```

---

## 3. Golden Netlist Verification Protocol

Before finalizing any carrier board:

1. **Manufacturer Schematic Source:** Download the official PDF schematic directly from the module vendor (e.g., Espressif, Seeed Studio, Raspberry Pi). Never use community blog pinouts.
2. **Ground Net Verification:** Extract all pins mapped to `GND` from the PDF table. Verify that in Atopile, each of those physical pins is connected to the ground net.
3. **Power Pin Isolation:** Ensure the 5V input rail connects exclusively to the module's 5V input pin (e.g., J1 Pin 21 on ESP32-S3-DevKitC-1) and never to J3 Pin 1 or J1 Pin 1.
4. **KiCad Footprint Check:**
   - Pad 1 must be visually identifiable with a square pad and a silkscreen dot.
   - Verify that 3D step models match the orientation of the physical header socket.

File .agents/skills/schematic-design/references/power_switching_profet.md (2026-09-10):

# High-Side Power Switching: Smart Switches (PROFETs) & Slew Rate Limits

Automotive body electronics and van conversions require switching positive rails (High-Side Switching) to prevent accidental ground-fault short circuits. This guide details design rules for Infineon PROFET+ (BTS series) smart power switches.

---

## 1. PROFET Architecture vs. Discrete MOSFETs

```
Infineon PROFET Smart Switch Internal Architecture:
                 +---------------- V_S (+12V Battery)
                 |
           +-----+-----+
           |  Charge   |
           |   Pump    |
           +-----+-----+
                 |
IN (GPIO) ---> [ Gate  ] ---> [ N-MOS Power DMOS ] ---> OUT (To 12V Load)
               [ Logic ]      [      Switch      ]
                 |                    |
DEN (GPIO) --> [Current] <------------+ (Current Mirror Ratio: k_ILIS = 8200)
               [ Mirror]
                 |
                 +--------------------> IS (Current / Fault Diagnostics)
                                              |
                                             [R_IS] 1.2k
                                              |
                                             GND
```

### 1.1 Why PROFETs Replace Discrete MOSFETs in Automotive Design
1. **Autonomous Fault Protection:** Built-in hardware current limiting, short-to-ground protection, and thermal shutdown ($150^\circ\text{C}-175^\circ\text{C}$) latch-off in $<10\,\mu\text{s}$ without MCU intervention.
2. **Inductive Load Demagnetization:** Active Zener clamp across Drain-Source ($V_{DS(AZ)} \approx 41\,\text{V}$) absorbs the inductive flyback energy of motors and relays safely without requiring external freewheeling diodes.
3. **Controlled Slew Rates:** Internal gate driver controls $dV/dt$ to eliminate ringing and comply with CISPR 25 Class 5 radiated emissions.

---

## 2. The Physics of Slew Rates & PWM Frequency Limits

### 2.1 Switching Times of BTS5008-1EKB
According to the Infineon BTS5008-1EKB datasheet:
- Turn-on delay + rise time ($t_{ON}$): **Typ 150 µs, Max 250 µs**
- Turn-off delay + fall time ($t_{OFF}$): **Typ 155 µs, Max 250 µs**
- Total transition time: $t_{trans} = t_{ON} + t_{OFF} \le 500\,\mu\text{s}$

### 2.2 Why 5 kHz PWM Causes Thermal Runaway
If driven with standard microcontroller 5 kHz PWM ($T_{PWM} = 200\,\mu\text{s}$):
$$T_{PWM} = 200\,\mu\text{s} < t_{trans} = 500\,\mu\text{s}$$
The device is permanently trapped transitioning through its linear (resistive) region.

Switching power dissipation per cycle:
$$P_{SW} = f_{PWM} \cdot V_S \cdot I_L \cdot \left(\frac{t_{rise} + t_{fall}}{2}\right)$$
For $V_S = 13.5\,\text{V}$, $I_L = 5\,\text{A}$, $t_{rise} = t_{fall} = 50\,\mu\text{s}$:
- **At 200 Hz:**
  $$P_{SW} = 200 \times 13.5 \times 5 \times 50\times 10^{-6} = 0.675\,\text{W} \quad (\text{Safe, easy PCB cooling})$$
- **At 5000 Hz:**
  $$P_{SW} = 5000 \times 13.5 \times 5 \times 50\times 10^{-6} = 16.88\,\text{W}!$$
  With standard thermal resistance $R_{\theta JA} \approx 35^\circ\text{C/W}$:
  $$\Delta T = 16.88\,\text{W} \times 35^\circ\text{C/W} = 590^\circ\text{C} \implies \text{DESTRUCTION}$$

> [!IMPORTANT]
> **Mandatory Rule:** Set PWM frequency for PROFET switches between **100 Hz and 400 Hz** (nominally **200 Hz** for automotive cabin lighting and dimming).

---

## 3. Current Sensing (IS) & Microcontroller ADC Protection

### 3.1 Sense Resistor Calculation
The IS pin mirrors load current:
$$I_S = \frac{I_L}{k_{ILIS}}$$
For BTS5008-1EKB, nominal $k_{ILIS} = 8200$. For a maximum load current $I_L = 15\,\text{A}$:
$$I_S = \frac{15\,\text{A}}{8200} = 1.83\,\text{mA}$$
To map to the linear range of an ESP32 ADC ($V_{ADC} \approx 2.2\,\text{V}$):
$$R_{IS} = \frac{2.2\,\text{V}}{1.83\,\text{mA}} \approx 1.2\,\text{k}\Omega$$

### 3.2 Overvoltage Fault Clamp Protection
During a fault condition (short circuit, thermal shutdown, or open load), the PROFET drives a constant fault current into the IS pin:
$$I_{S(FAULT)} \approx 4.5\,\text{mA} - 7.0\,\text{mA}$$
Across $R_{IS} = 1.2\,\text{k}\Omega$:
$$V_{IS(FAULT)} = 7.0\,\text{mA} \times 1.2\,\text{k}\Omega = 8.4\,\text{V}$$
Because $8.4\,\text{V}$ exceeds the ESP32 absolute maximum rating ($3.6\,\text{V}$), an unprotected ADC pin will be destroyed.

```
PROFET IS Pin Microcontroller Protection Circuit:
  PROFET IS Pin ---+---[ R_series: 2.2k ]---+---> ESP32 ADC (GPIO)
                   |                        |
                 [R_IS] 1.2k            [D_clamp] BAT54S (Dual Schottky to 3.3V / GND)
                   |                        |
                  GND                      GND
```

1. **Dual Schottky Clamp (BAT54S):** Clamps voltages $>3.6\,\text{V}$ to the 3.3V rail and $<-0.3\,\text{V}$ to GND.
2. **Series Resistor ($R_{series} \ge 2.2\,\text{k}\Omega$):** Restricts the maximum current injected into the 3.3V rail to $<1.5\,\text{mA}$.
3. **Diagnostic Enable (DEN):** When `DEN = LOW`, the IS pin is high-impedance. Firmware must assert `DEN = HIGH` before taking an ADC measurement.

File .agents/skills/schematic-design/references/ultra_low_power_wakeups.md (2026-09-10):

# Ultra-Low-Power Wake-Up Architectures: LP-GPIO & Diode-OR Matrices

Battery-powered remote switches (e.g., powered by 2x AA batteries for multi-year lifespan) require sub-$20\,\mu\text{A}$ deep sleep currents. This guide covers power domain partitioning, pin limitations, and hardware Diode-OR wakeup circuits for ESP32 microcontrollers.

---

## 1. Power Domain Partitioning: Low-Power (LP) vs. High-Power (HP)

```
ESP32-C6 Power Domain Architecture:
+-------------------------------------------------------------+
| ALWAYS-ON (AON) / LOW-POWER (LP) DOMAIN (~15 uA Deep Sleep)  |
|   - LP Core (RISC-V)                                        |
|   - LP Memory                                               |
|   - LP-GPIOs (GPIO 0 through GPIO 7)                        |
|   - Wakeup Controller (EXT0 / EXT1)                         |
+-------------------------------------------------------------+
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

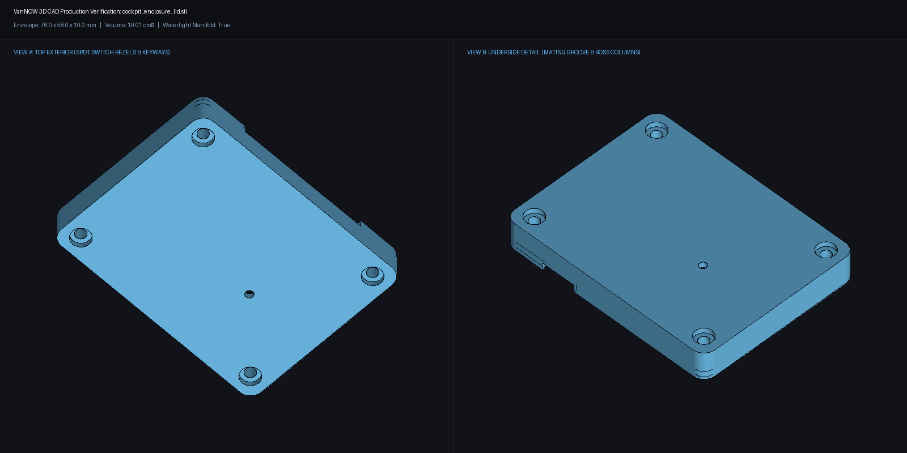
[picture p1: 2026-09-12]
hardware/enclosures/renders/cockpit_enclosure_lid_render.png

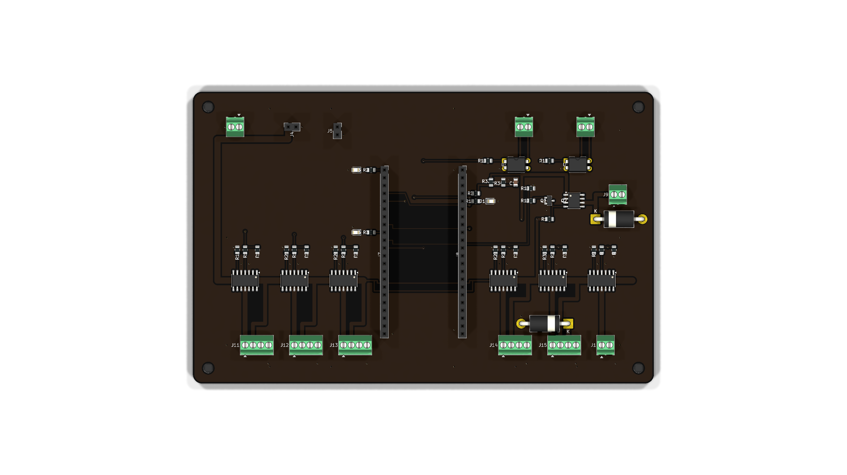
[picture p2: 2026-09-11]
hardware/central-pcb/renders/profet_top.png

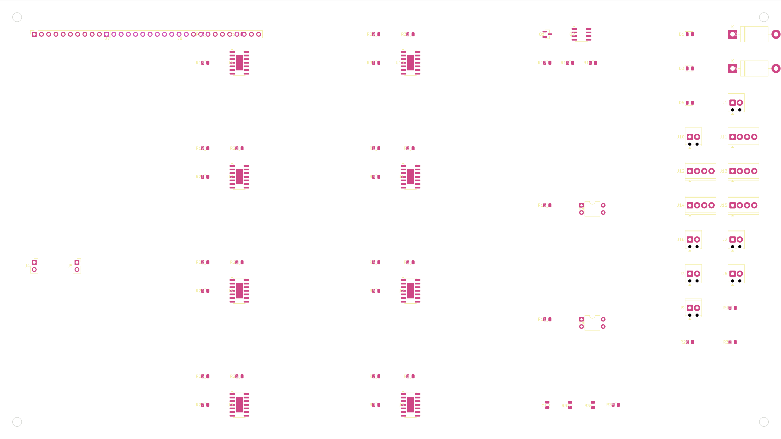
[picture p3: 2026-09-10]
hardware/central-pcb/renders/profet_silkscreen.png

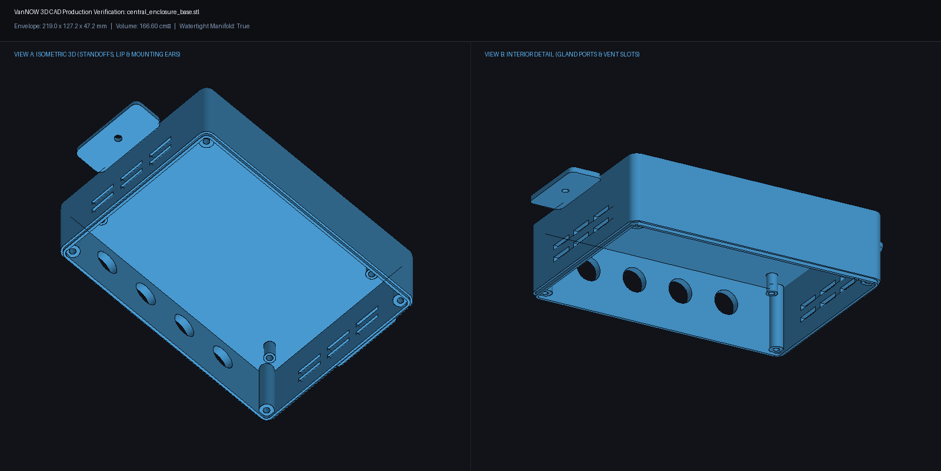
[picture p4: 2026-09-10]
hardware/enclosures/renders/central_enclosure_base_render.png

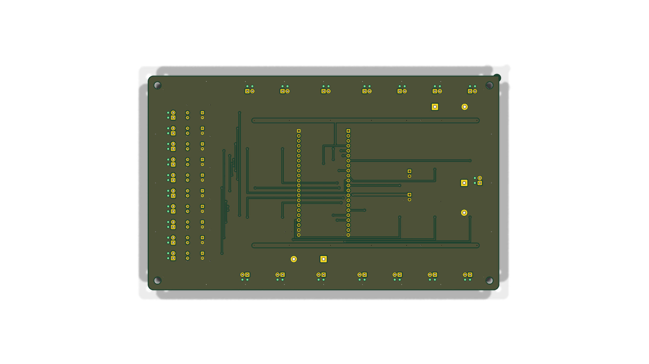
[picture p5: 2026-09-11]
hardware/central-pcb/renders/profet_24ch/profet_24ch_bottom.png

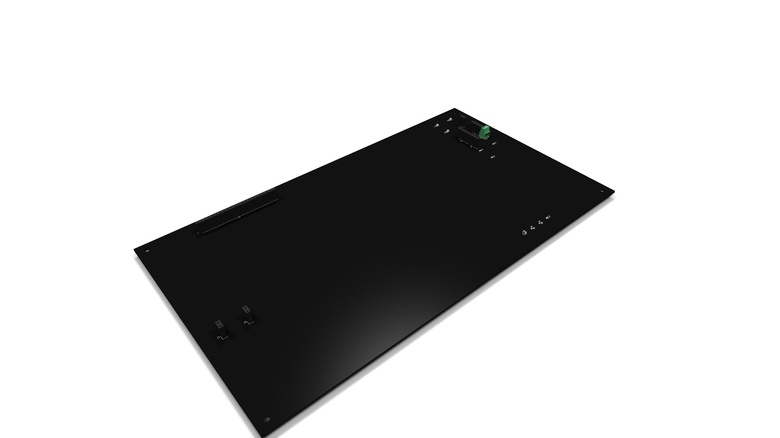
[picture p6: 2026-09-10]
hardware/central-pcb/renders/modular_isometric.png

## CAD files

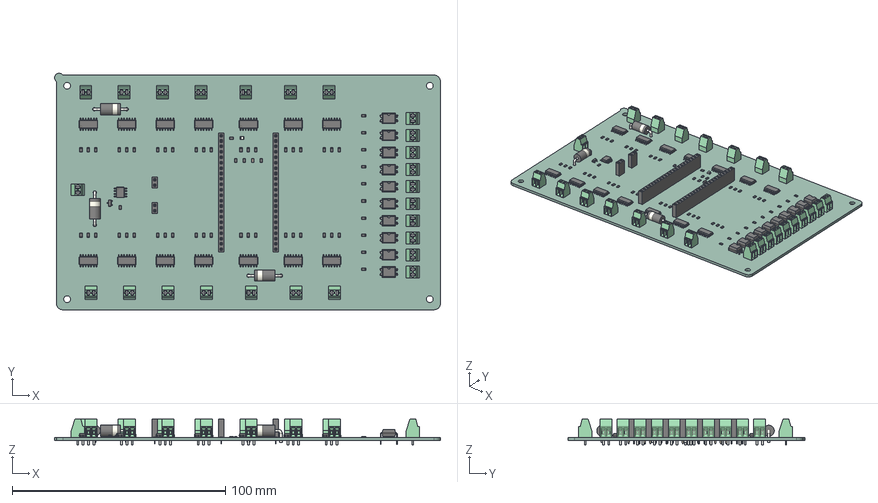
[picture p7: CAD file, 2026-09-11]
hardware/central-pcb/renders/profet_24ch/profet_24ch.step
180.9 x 110.9 x 12.0 mm
R_0805_2012Metric x 57
DIP-4_W7.62mm x 10
TerminalBlock_Phoenix_MPT-0,5-2-2.54_1x02_P2.54mm_Horizontal x 25
SOIC-14_3.9x8.7mm_P1.27mm x 14
LED_0805_2012Metric
PinSocket_1x22_P2.54mm_Vertical x 2
D_DO-201AD_P15.24mm_Horizontal x 3
SOIC-8_3.9x4.9mm_P1.27mm
PinSocket_1x02_P2.54mm_Vertical x 2
C_0805_2012Metric
SOT-23
profet_24ch_PCB

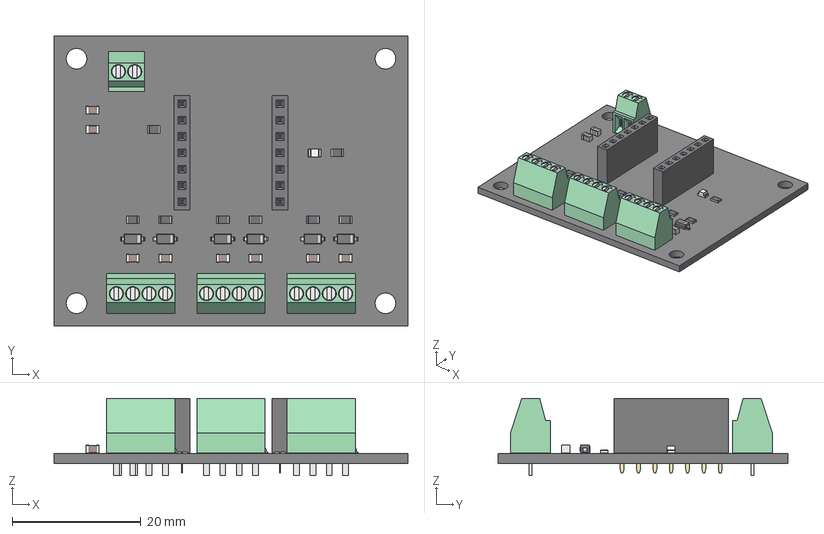
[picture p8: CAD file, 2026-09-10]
hardware/cockpit-pcb/renders/cockpit_pcb.step
55.0 x 45.0 x 12.0 mm
C_0805_2012Metric x 8
R_0805_2012Metric x 8
TerminalBlock_Phoenix_MPT-0,5-4-2.54_1x04_P2.54mm_Horizontal x 3
D_SOD-123 x 6
PinSocket_1x07_P2.54mm_Vertical x 2
LED_0805_2012Metric
TerminalBlock_Phoenix_MPT-0,5-2-2.54_1x02_P2.54mm_Horizontal
default_PCB

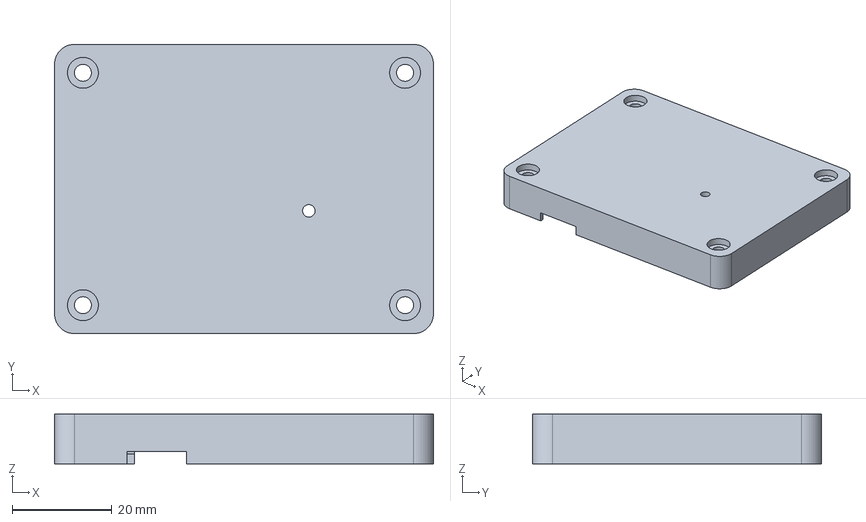
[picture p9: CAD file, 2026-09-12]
hardware/enclosures/models/cockpit_enclosure_lid.step
76.0 x 58.0 x 10.0 mm

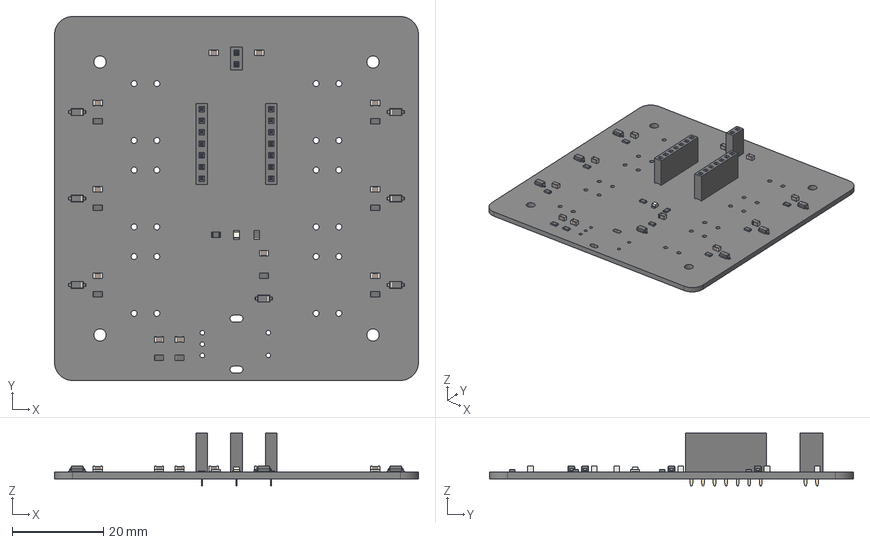
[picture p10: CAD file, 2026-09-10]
hardware/entrance-remote-pcb/renders/entrance_remote_pcb.step
80.0 x 80.0 x 11.6 mm
D_SOD-123 x 7
C_0805_2012Metric x 11
R_0805_2012Metric x 11
PinSocket_1x02_P2.54mm_Vertical
LED_0805_2012Metric
PinSocket_1x07_P2.54mm_Vertical x 2
default_PCB

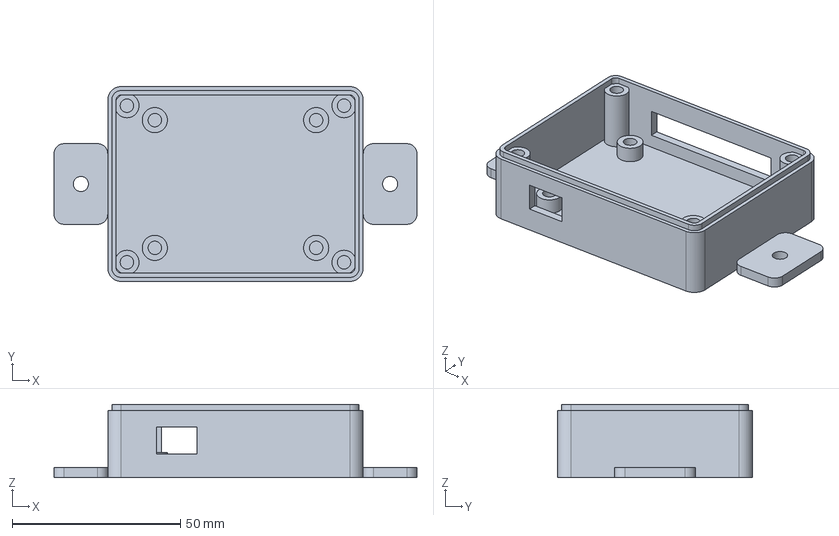
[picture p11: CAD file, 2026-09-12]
hardware/enclosures/models/cockpit_enclosure_base.step
108.0 x 58.0 x 21.8 mm

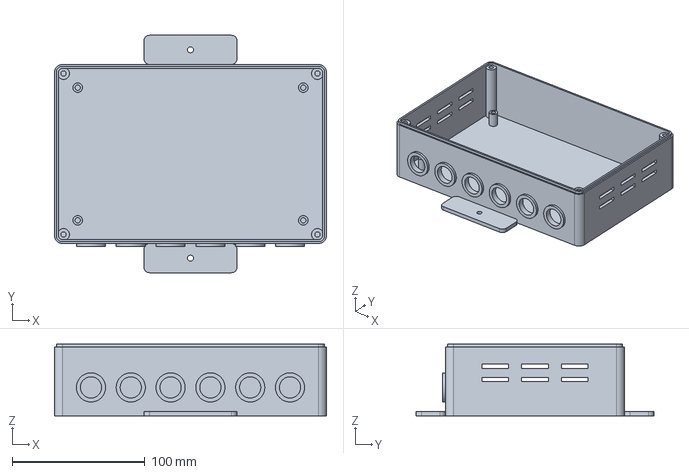
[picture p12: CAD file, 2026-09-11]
hardware/enclosures/models/central_24ch_enclosure_base.step
205.0 x 179.0 x 54.2 mm

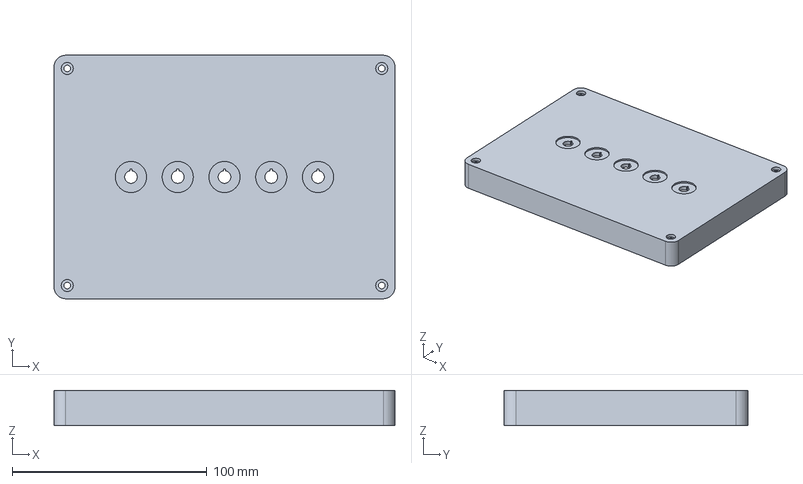
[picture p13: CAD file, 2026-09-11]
hardware/enclosures/models/central_enclosure_lid.step
175.0 x 125.0 x 18.0 mm

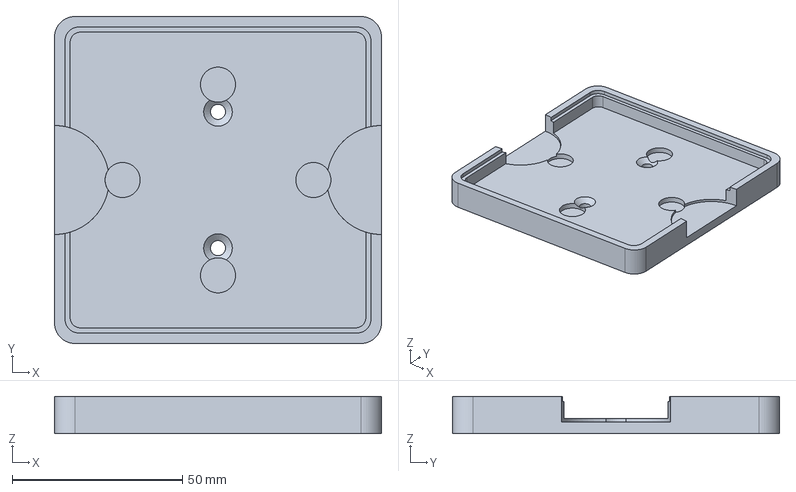
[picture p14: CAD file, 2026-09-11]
hardware/enclosures/models/remote_magnetic_cradle.step
96.0 x 96.0 x 11.0 mm

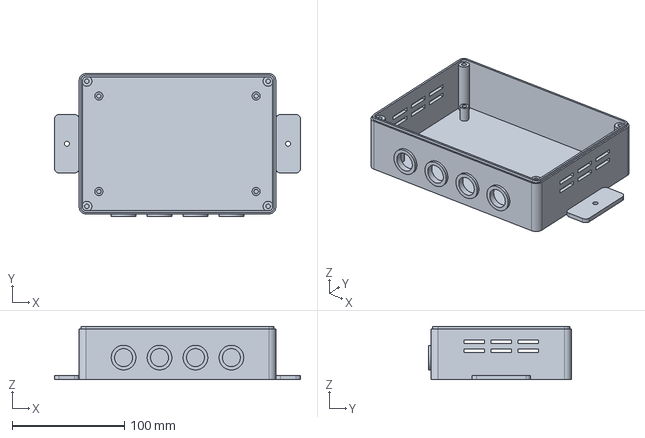
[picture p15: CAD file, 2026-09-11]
hardware/enclosures/models/central_enclosure_base.step
219.0 x 127.2 x 47.2 mm

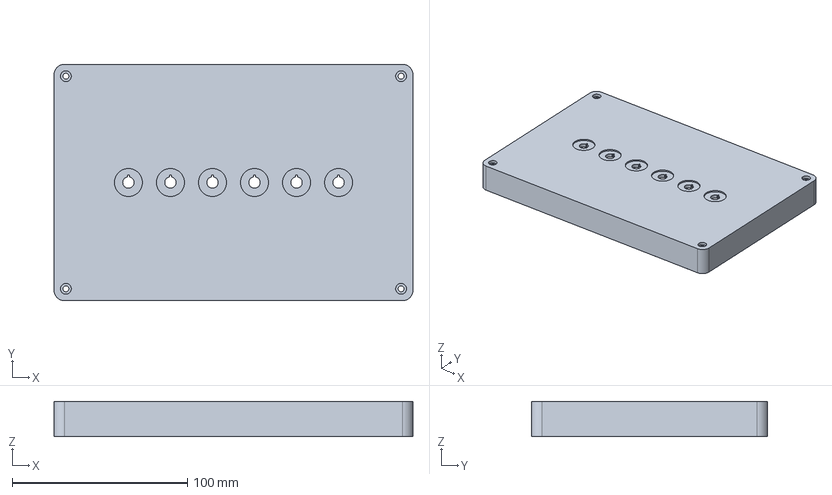
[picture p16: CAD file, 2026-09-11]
hardware/enclosures/models/central_24ch_enclosure_lid.step
205.0 x 135.0 x 20.0 mm

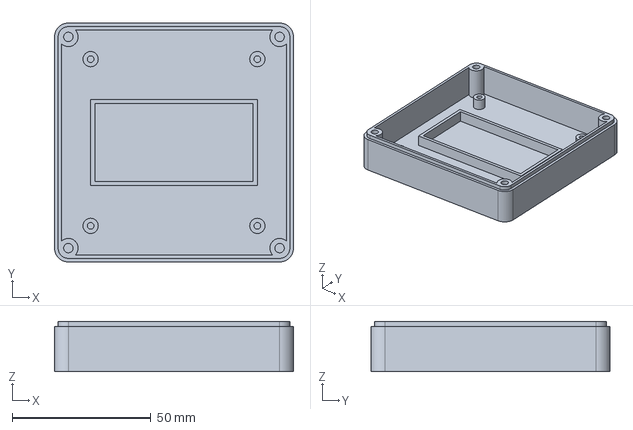
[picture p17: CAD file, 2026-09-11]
hardware/enclosures/models/remote_enclosure_body.step
86.0 x 86.0 x 18.0 mm

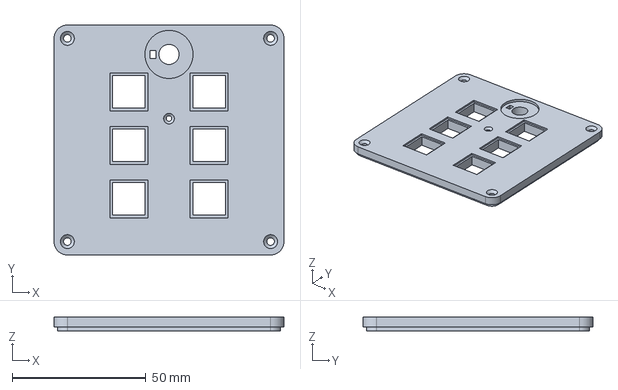
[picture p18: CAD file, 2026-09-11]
hardware/enclosures/models/remote_enclosure_faceplate.step
86.0 x 86.0 x 5.40 mm

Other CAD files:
hardware/enclosures/models/central_24ch_enclosure_base.stl
hardware/enclosures/models/central_24ch_enclosure_lid.stl
hardware/enclosures/models/central_enclosure_base.stl
hardware/enclosures/models/central_enclosure_lid.stl
hardware/enclosures/models/cockpit_enclosure_base.stl
hardware/enclosures/models/cockpit_enclosure_lid.stl
hardware/enclosures/models/remote_enclosure_body.stl
hardware/enclosures/models/remote_enclosure_faceplate.stl
hardware/enclosures/models/remote_magnetic_cradle.stl

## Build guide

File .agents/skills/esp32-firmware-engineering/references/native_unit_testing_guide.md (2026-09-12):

# Native Unit Testing (PlatformIO + Arduino mock)

Host tests must stay under ~1 s and must exercise the gesture that the production bug would hit (especially **repeated `StartHold`**).

## Layout

```
firmware/
├── central/  platformio.ini  [env:native]  test/test_channels/
├── remote/   platformio.ini  [env:native]  test/test_remote_handlers/
└── lib/arduino_mock/         Arduino.h, Preferences.h, esp_sleep.h
```

Central native env ignores `main.cpp` and `wireless`. Remote native env also ignores `RemoteSender.cpp`.

## Mock APIs (real names)

```cpp
#include <unity.h>
#include <Arduino.h>
#include <Preferences.h>
#include "SystemController.h"

void setUp(void) {
    ArduinoMock::reset();
    Preferences::resetMockStorage();  // required: anti-replay now writes NVS
}

void test_shower_keepalives_do_not_cancel(void) {
    SystemController controller;
    controller.begin();
    SwitchMessage msg = {};
    msg.remote_id = 1;
    msg.button_index = 4; // entrance pump
    msg.action = (uint8_t)ActionType::StartHold;
    msg.seq = 10;
    uint8_t mac[6] = {1,2,3,4,5,6};
    controller.dispatchMessage(mac, msg);
    msg.seq = 11;
    controller.dispatchMessage(mac, msg);
    DigitalChannel* pump = static_cast<DigitalChannel*>(controller.getChannel(4));
    TEST_ASSERT_TRUE(pump->isTimedActive());
}
```

Time: `ArduinoMock::advanceMillis(ms)` then `channel.update()` / `controller.update()`.  
Pins: `ArduinoMock::setPinState(pin, LOW)` / `getPinState` / `getLEDCWrite`.

`DimmableChannel` constructor is `(const char* name, uint8_t pin)`. There is no `handleHoldStart()` — use `handleAction(ActionType::StartHold, 0)`.

## Required coverage when touching FSMs

| Change | Test that must exist |
| :--- | :--- |
| Pump shower | `StartHold` + 150 ms + `StartHold` still timed-active; `Click` cancels |
| Any `DigitalChannel` | `StartHold` / `DoubleClick` do **not** start a timer |
| `PulseChannel` | `StartHold` does not `trigger()` |
| Encoder | button 7 dims focused zone, not Ch 0 by default after another zone click |
| `ButtonHandler` | `Click` after 320 ms; `DoubleClick` on second press; latching emits Click on both edges |
| Anti-replay | Reboot `SystemController` rejects a repeated `seq` |

## Commands

```bash
pio test -d firmware/central -e native
pio test -d firmware/remote -e native
```

Gate: 100% pass before commit. Current suites: 25 central + 11 remote.

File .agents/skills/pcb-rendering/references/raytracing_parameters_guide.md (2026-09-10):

# KiCad CLI Raytracing & Rendering Parameters Reference Guide

This reference guide details the parameters, lighting models, camera projections, and material configurations available in `kicad-cli pcb render` for headless rendering.

---

## 1. Camera Control & Projection Models

The KiCad raytracer supports both orthographic (parallel) and perspective (pinhole camera) viewing models.

### 1.1 Rotation Angles (`--rotate X,Y,Z`)
Rotations are applied in degrees around the Euler axes:
* **$X$ (Pitch):** Tilts the board toward or away from the camera.
* **$Y$ (Roll):** Tilts the board sideways.
* **$Z$ (Yaw):** Spins the board around its normal axis.

#### Recommended Presets:
| View Style | `--rotate` Argument | Description |
| :--- | :--- | :--- |
| **Standard Isometric (Hero View)** | `-50,0,40` | Classic 3/4 axonometric perspective. Balances visibility of top traces, connector heights, and side terminals. |
| **Steep Axonometric (Component Focus)** | `-65,0,30` | Steeper angle, ideal for densely populated boards where top text legibility is primary. |
| **Low Horizon (Connector Profile View)** | `-30,0,45` | Low grazing angle, highlighting vertical component clearances (capacitors, heat sinks, terminals). |
| **Top Orthographic** | `--side top` (no rotate) | Pure 2D perpendicular top view for dimensional validation. |
| **Bottom Orthographic** | `--side bottom` (no rotate) | Bottom copper traces and solder joint inspection. |

### 1.2 Perspective vs. Orthographic (`--perspective`)
* **Without `--perspective` (Orthographic):** Parallel rays with no foreshortening. True to scale; parallel lines never converge. Useful for technical drawings and dimensional overlay.
* **With `--perspective` (Perspective):** Simulates a real-world focal lens. Components further away appear smaller, enhancing 3D depth perception and realistic presentation.

### 1.3 Pan, Zoom, and Pivot
* `--zoom <factor>`: Multiplier for camera distance (e.g. `1.2` zooms in by 20%, `0.8` zooms out).
* `--pan X,Y,Z`: Shifts the camera target vector.
* `--pivot X,Y,Z`: Sets the center of rotation relative to board center in centimeters (e.g. `0,0,0`).

---

## 2. Lighting & Ground Shading Architecture

KiCad's raytracer uses a directional and ambient lighting model with an optional ground reflection plane.

### 2.1 Floor & Shadows (`--floor`)
* When `--floor` is enabled:
  1. A horizontal ground plane is inserted beneath the lowest point of the board assembly.
  2. Ambient occlusion and contact shadows are cast onto this floor.
  3. Specular highlights and reflections ground the electronic assembly visually, eliminating the "floating in void" look.

### 2.2 Background Modes (`--background`)
* `transparent` (Default for PNG): Perfect for embedding into documentation, white papers, and dark/light mode web interfaces.
* `opaque` (Default for JPEG): Fills background with the environment color.
* `default`: Uses KiCad's default viewport background gradient.

### 2.3 Fine-Grained Light Source Control
When default lighting requires artistic or high-contrast adjustments:
* `--light-top <R,G,B>` (range 0.0 to 1.0): Direct overhead sun/key light.
* `--light-side <R,G,B>`: Fill light from side quadrants.
* `--light-side-elevation <angle>` (0° to 90°, default 60°): Elevation angle of side fill lights.
* `--light-camera <R,G,B>`: Front-facing fill light originating from the camera lens to prevent deep black shadows on vertical walls.

---

## 3. Materials, Stackup & Surface Finishes

To produce authentic renders matching manufactured prototypes, KiCad utilizes physical material properties configured in the board stackup (`setup.stackup` in `.kicad_pcb`):

### 3.1 Stackup Color Enforcement (`--use-board-stackup-colors`)
Always pass `--use-board-stackup-colors`. This forces the raytracer to read the specific colors defined in the layout rather than the generic green user preset:
* **Matte Black Mask:** `(color "Black")` with low specular roughness.
* **Classic Forest Green:** `(color "Green")`.
* **Deep Blue / Purple:** Popular for open-source and developer boards.

### 3.2 Copper & Plating Reflections
* **ENIG (Electroless Nickel Immersion Gold):** `(copper_finish "ENIG")` renders pads and through-hole barrels with realistic warm metallic gold reflectance.
* **HASL (Hot Air Solder Leveling):** Renders pads with bright silver-tin metallic specular highlights.

---

## 4. Production Shell Recipes

### Recipe A: 4K Ultra-HD Marketing Hero Render
```bash
flatpak run --command=kicad-cli org.kicad.KiCad pcb render \
  --output pcb_hero_4k.png \
  --rotate -50,0,40 \
  --perspective \
  --floor \
  --use-board-stackup-colors \
  --quality high \
  --width 3840 \
  --height 2160 \
  board.kicad_pcb
```

### Recipe B: Transparent Background Cutout for Documentation
```bash
flatpak run --command=kicad-cli org.kicad.KiCad pcb render \
  --output pcb_transparent.png \
  --rotate -48,0,38 \
  --perspective \
  --background transparent \
  --use-board-stackup-colors \
  --quality high \
  --width 2560 \
  --height 1440 \
  board.kicad_pcb
```

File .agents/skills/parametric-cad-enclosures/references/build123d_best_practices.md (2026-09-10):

# build123d Best Practices & Architectural Idioms

This reference details critical lessons, anti-patterns, and robust geometric idioms discovered when modeling production electronics enclosures with **build123d** on OpenCASCADE.

---

## 1. The Global Plane-Reset Trap

### The Issue
In `build123d`, global plane objects such as `Plane.XY`, `Plane.XZ`, and `Plane.YZ` are static geometric coordinate frames whose origin is permanently fixed at $(0, 0, 0)$.

When passing `Plane.XZ` into `BuildSketch(Plane.XZ)` inside a `with Locations((x, y, z)):` block:
```python
# ❌ DANGEROUS: The outer location (x, y, z) is silently discarded!
with Locations((50.0, -60.0, 25.0)):
    with BuildSketch(Plane.XZ):
        Circle(radius=8.0)
    extrude(amount=5.0)
```
The resulting cylinder will be created at $(0, 0, 0)$ on the XZ plane, causing invisible features inside the wrong walls or cutting through the middle of the enclosure!

### The Solution: 3D Primitives with Explicit Rotation
Use standard 3D primitives (`Cylinder`, `Box`, `Cone`) with the `rotation` parameter:
```python
# ✅ SAFE & IDIOMATIC:
with Locations((50.0, -60.0, 25.0)):
    Cylinder(radius=8.0, height=5.0, rotation=(90, 0, 0))
```
3D primitives are fully location-aware and correctly inherit translation, rotation, and alignment (`align=(Align.CENTER, ...)`).

---

## 2. 2D Sketch Profiles vs. Fragile 3D Booleans

### The Anti-Pattern
Creating a solid 3D box, applying a 3D corner fillet, using `offset(amount=-wall)` to hollow it, and then fusing separate 3D mounting lugs to the outside:
```python
# ❌ FRAGILE:
Box(length, width, height)
fillet(base.edges().filter_by(Axis.Z), 6.0)
offset(amount=-wall, openings=base.faces().sort_by(Axis.Z)[-1])

# Adding mounting ears separately:
with Locations((-length/2 - 10, 0), (length/2 + 10, 0)):
    Box(20, 50, floor)
    fillet(base.edges().filter_by(Axis.Z), 4.0) # Selects ALL Z-edges of the ENTIRE part!
```
**Why this fails:**
1. Global edge filters like `edges().filter_by(Axis.Z)` target all vertical edges in the entire model, repeatedly attempting to re-fillet already filleted edges.
2. `offset(openings=...)` on non-convex or pre-filleted solids frequently causes self-intersecting B-Rep surfaces or OpenCASCADE kernel crashes.
3. Butt-joining separate 3D blocks creates non-manifold lines along the tangent seams.

### The Idiomatic Pattern: Layered 2D Sketches
Construct the part bottom-up in continuous 2D sketch layers:
```python
with BuildPart() as base:
    # Layer 1: Floor plate with mounting ears as a SINGLE unified 2D sketch
    with BuildSketch(Plane.XY) as s_floor:
        RectangleRounded(length, width, 6.0)
        with Locations((-length / 2 - 11.0, 0), (length / 2 + 11.0, 0)):
            RectangleRounded(22.0, 52.0, 4.0)
            Circle(radius=2.25, mode=Mode.SUBTRACT) # M4 mounting holes
    extrude(amount=floor_thickness)

    # Layer 2: Hollow vertical walls extruded up from floor
    with BuildSketch(Plane.XY.offset(floor_thickness)) as s_walls:
        RectangleRounded(length, width, 6.0)
        RectangleRounded(length - 2 * wall, width - 2 * wall, 6.0 - wall, mode=Mode.SUBTRACT)
    extrude(amount=height - floor_thickness)

    # Layer 3: Stepped perimeter alignment lip
    with BuildSketch(Plane.XY.offset(height)) as s_lip:
        RectangleRounded(length - 2 * lip_w, width - 2 * lip_w, 6.0 - lip_w)
        RectangleRounded(length - 2 * wall, width - 2 * wall, 6.0 - wall, mode=Mode.SUBTRACT)
    extrude(amount=lip_h)
```
**Benefits:**
- 100% guaranteed watertight manifold solid (`is_valid == True`).
- Deterministic wall thickness at every point.
- Zero fragile topological edge selections.

---

## 3. Sketch Slot Geometry Constraints
In `build123d`, `RectangleRounded(width, height, radius)` enforces:
$$\text{width} > 2 \cdot \text{radius} \quad \text{and} \quad \text{height} > 2 \cdot \text{radius}$$
If `radius == height / 2`, it raises `ValueError("width and height must be > 2*radius")`.

* **To create slots with fully rounded semicircular ends:** Use `SlotOverall(length, width)`:
  ```python
  with BuildSketch(Plane.YZ):
      SlotOverall(length=18.0, width=3.2)
  ```

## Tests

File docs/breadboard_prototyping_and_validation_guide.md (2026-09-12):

# VanNOW — Breadboard Prototyping & Hardware Validation Guide

Authoritative bench procedure for the **24-channel firmware** on `fix/logic-audit-2026-09-11` (and later). It supersedes older pin tables in this file and in [`lista_compras_prototipo.md`](lista_compras_prototipo.md). Do **not** use that shopping list for wiring.

This is a **lab bring-up**, not a fabrication release. Do not order PCBs from this guide.

Two phases:

1. **Phase A — USB 5 V only (no 12 V):** ESP-NOW, entrance faceplate, encoder focus dimming, shower timer, NVS restore.
2. **Phase B — fused 12 V:** buck 5 V, battery ADC, logic-level MOSFET + flyback, optocoupler dry contact.

---

## 0. Identity (read before wiring)

| Item | Value |
| :--- | :--- |
| Central firmware | Default **24** channels (`-e esp32-s3-devkitc-1`). Zone 1 = **GPIO 12**, pump = **GPIO 4**. Legacy 11-ch PCB: `-e esp32-s3-profet-11ch`. |
| Remote image | Entrance only: `seeed_xiao_esp32c6` (`REMOTE_ID=1`). Do **not** flash `cockpit_xiao_esp32c6` on this breadboard. |
| Encoder | Button index **7**. Turn dims the last focused lighting zone. Click sets that zone to **100%**. |
| Shower | **5 min** on the pump only. Double-click (or first hold) on **button 4**. Cancel with a single click. Chirp is the **pump output** (GPIO 4), not a buzzer pin. |
| Status LED | XIAO **D10 = GPIO 18**. Never drive GPIO 9 (BOOT). |
| DevKit RGB | GPIO **38** (v1.1) and **48** (v1.0) are channel outputs. Do not hang LEDs on them. |
| ESP-NOW MACs | Both sides program `AA:BB:CC:DD:EE:FF` (central) and `…:11` (entrance). Leave them matching. |
| XIAO `3V3` | Regulator **output**. Do not feed 2×AA into it (audit H-12). Phase A uses USB-C. |

XIAO ESP32-C6 silk ≠ GPIO number:

| Silk | GPIO | Entrance use |
| :---: | :---: | :--- |
| D0 | 0 | Diode-OR wakeup bus |
| D1 | 1 | Encoder A |
| D2 | 2 | Encoder B |
| D3 | 21 | Zone 1 (button 0) |
| D4 | 22 | Zone 2 (button 1) |
| D5 | 23 | Zone 3 (button 2) |
| D6 | 16 | Zone 4 (button 3) |
| D7 | 17 | Water pump (button 4) |
| D8 | 19 | Night off (button 5) |
| D9 | 20 | Encoder SW only |
| D10 | 18 | Status LED |

---

## 1. Prototype Bill of Materials

### 1.1 Phase A (USB only)

| Qty | Item | Purpose |
| :---: | :--- | :--- |
| 1 | Lonely Binary ESP32-S3 N16R8 (or DevKitC-1) | Central |
| 1 | Seeed XIAO ESP32-C6 | Entrance remote |
| 2 | USB-C cables | Flash + 5 V |
| 1 | Alps EC11 with push switch | Focus dimmer |
| 6 | Tactile buttons (or 3: Zone 1, pump, night) | Faceplate |
| 6 | BAT54 / BAS70 / 1N4148 | Diode-OR to D0 (one per button + encoder SW) |
| 1 | 47 kΩ | Wake bus pull-up to 3.3 V |
| 3 | 220 Ω or 330 Ω | LED current limit |
| 2 | 5 mm LEDs (green, red) | Zone 1 and pump on the central |
| 1 | 5 mm LED (green) | Remote status on D10 |
| 2 | Breadboards + jumper kit | Separate central / remote |

Encoder A/B wake on LP-GPIO 1/2; they do not need diodes. Buttons and encoder SW do.

### 1.2 Phase B (add when Phase A passes)

| Qty | Item | Purpose |
| :---: | :--- | :--- |
| 1 | 12 V source (1–2 A wall brick, bench PSU, or fused van battery) | Bus |
| 1 | MP1584EN (reputable) or Pololu D24V10F5 | 12 V → 5.00 V |
| 1 | Mini blade fuse **5 A** at the +12 V source | Protection |
| 1 | LR7843 / D4184 logic-level MOSFET module | Bench load switch |
| 1 | PC817 2-ch module | Inverter dry-contact sim |
| 1 | 1N5408 or 1N5822 | Pump flyback |
| 1 | 100 kΩ 1% + 18 kΩ 1% + 1 kΩ + 100 nF | ADC front-end (GPIO 1) |
| 1 | 12 V LED strip scrap or small motor | Load |

Phase B with an N-channel module is **low-side** (load to drain, source to GND). That is acceptable for an isolated bench strip. Van production switching is **high-side PROFET**. Do not extend a low-side breadboard into chassis-return van wiring.

---

## 2. Phase A wiring

Power both boards from USB-C. Common GND between boards is not required (ESP-NOW is wireless).

### 2.1 Central (ESP32-S3)

```
USB-C 5 V → ESP32-S3

GPIO 12 ──[ 220 Ω ]──► green LED anode ──► GND     Zone 1 (Ch 0)
GPIO 4  ──[ 220 Ω ]──► red LED anode   ──► GND     Pump (Ch 4); shower chirp is this LED
GND ── common LED cathode rail
```

Do not wire a third LED to GPIO 38 or 48.

### 2.2 Entrance remote (XIAO ESP32-C6)

Diode-OR: **anode to the D0 bus**, **cathode to the sense pin**. Pressing a button pulls the sense pin and the bus to GND.

```
USB-C 5 V → XIAO          (do not connect 2×AA to 3V3)

3V3 ──[ 47 kΩ ]──┬──────── D0 (GPIO 0) wakeup bus
                 │
    Zone1 ──|<|──┤   cathode to D3, other button pin to GND
    Zone2 ──|<|──┤   cathode to D4
    Zone3 ──|<|──┤   cathode to D5
    Zone4 ──|<|──┤   cathode to D6
    Pump  ──|<|──┤   cathode to D7
    Night ──|<|──┤   cathode to D8
    EncSW ──|<|──┘   cathode to D9

EC11 A (CLK) → D1 (GPIO 1)
EC11 B (DT)  → D2 (GPIO 2)
EC11 COM     → GND

D10 (GPIO 18) ──[ 220 Ω ]──► status LED anode ──► GND
```

Minimum set if you are short on buttons: Zone 1, pump, night, encoder (plus diodes on those three buttons and EncSW).

### 2.3 Pin table

| From | Pin | To | Pin | Notes |
| :--- | :--- | :--- | :--- | :--- |
| USB | VBUS | ESP32-S3 | USB-C | Central 5 V |
| ESP32-S3 | GPIO 12 | 220 Ω → green LED | anode | Zone 1 |
| ESP32-S3 | GPIO 4 | 220 Ω → red LED | anode | Pump + shower chirp |
| USB | VBUS | XIAO | USB-C | Remote 5 V. Not 3V3. |
| XIAO 3V3 | 3V3 | 47 kΩ | one end | Pull-up only |
| 47 kΩ | other end | XIAO | D0 | Wake bus |
| Each button / EncSW | one side | GND | | Active low |
| Each button / EncSW | other side | diode cathode + sense silk | D3–D9 as above | |
| Diode anodes | | D0 bus | | |
| EC11 | A / B / COM | D1 / D2 / GND | | No diodes on A/B |
| XIAO | D10 | 220 Ω → LED | anode | Status flash |

---

## 3. Phase A protocol

### A1 — Build and flash

From the repo root, on this branch:

```bash
pio test -d firmware/central -e native
pio test -d firmware/remote -e native

pio run -d firmware/central -e esp32-s3-devkitc-1 -t upload
pio run -d firmware/remote -e seeed_xiao_esp32c6 -t upload
```

Serial (115200):

```bash
pio device monitor -d firmware/central -e esp32-s3-devkitc-1
pio device monitor -d firmware/remote -e seeed_xiao_esp32c6
```

Central should print `Starting VanNOW Central Controller...` then `System initialized. Awaiting wireless ESP-NOW commands.` and `Central MAC Address: AA:BB:CC:DD:EE:FF`.

The remote flashes D10 once on a cold boot, then sleeps. After a button wake it prints `Remote active. Listening for physical input transitions.`

If the remote never wakes, the diode-OR or D0 pull-up is wrong. If the central prints `Rejected packet: sender MAC address not in allow-list`, the remote image is not `REMOTE_ID=1` (you flashed cockpit).

### A2 — Link and Zone 1

1. Tap Zone 1 (D3).
2. Remote: `Sending payload: Remote 1 | Btn 0 | Act 0 | Steps 0 | Bat …`
3. Central:

```
--- Message from [AA:BB:CC:DD:EE:11] ---
Remote ID: 1 | Button: 0 | Action: 0 | Seq: …
Channel [Lights Zone 1] (Index 0) state updated.
```

4. Green LED on GPIO 12 turns on (default restore brightness is 80% if NVS is empty).
5. Tap Zone 1 again: LED off, `Seq` increments.

Action numbers: `0` Click, `1` StartHold, `3` EncoderTurn, `4` DoubleClick.

### A3 — Encoder focus dimming

1. Turn Zone 1 on.
2. Rotate the EC11: green LED should ramp. Central `Button: 7` and `Action: 3`.
3. Click the encoder shaft: LED goes to 100%. Central: `Encoder boost: channel [Lights Zone 1] set to 100%`.
4. Tap Zone 2 (if wired), then rotate: dimming follows Zone 2, not Zone 1.
5. Hold Zone 1 > 500 ms: keep-alive `StartHold` (`Action: 1`) every ~150 ms; brightness ramps. Release to lock.

The encoder SW must be **only** on D9. Do not also jumper it to a zone pin.

### A4 — Pump, shower, night

1. Tap pump (D7, button 4): red LED on GPIO 4 on; tap again: off.
2. Double-tap pump within ~320 ms: `[Shower Mode] Activated: 300000 ms with acoustic chirp`. The **red** LED does two short pulses, then stays on. Remote D10 flashes three times.
3. Further holds during shower print `[Shower Mode] Keep-alive ignored; use Click to cancel.`
4. Single tap pump: shower cancels, red LED off.
5. Turn Zone 1 on, tap night (D8, button 5): `Action: Turn off all dimmable lights`. Green off; pump unchanged.

Pump safety auto-off is **10 min** (`restoreOnBoot=false`). Shower timer is **5 min**.

### A5 — NVS

1. Set Zone 1 to a visible mid brightness (encoder or hold). Leave pump off.
2. Unplug central USB. Plug back in.
3. Expect `[NVS] Restored dimmable channel 0 (Lights Zone 1) ON at N%` and the green LED at that level. Pump stays off.

Brightness in logs is **0–100**, not 0–255.

### A6 — Sleep current (optional, after A2–A5)

Do **not** inject 2×AA into `3V3`.

1. Disconnect XIAO USB.
2. Power the XIAO **5V** pin from 4.5–5.0 V (3×AA alkaline or a small USB pack) with the DMM in series on the positive lead. GND to XIAO GND.
3. After 1.5 s idle the remote prints `Entering Deep Sleep mode now.`
4. Expect **tens to hundreds of µA** on a breadboard (XIAO LDO + leakage). The ~15 µA chip figure will not show up here.
5. A press should spike to tens of mA, then collapse again.

Skip A6 if you only have 2×AA and no 4.5–5 V source.

---

## 4. Phase B — 12 V

Start only after A2–A5 pass. Fuse the +12 V lead at the source.

### 4.1 Buck first (no ESP32 connected)

1. 12 V → MP1584 `IN+` / `IN-`.
2. Adjust the trimmer to **5.00 V ± 0.05 V** on `OUT+`.
3. Remove 12 V. Then `OUT+` → ESP32-S3 `5V`, `OUT-` → `GND`.
4. Re-apply 12 V. Central must boot as in A1. USB-C can stay disconnected.

### 4.2 Battery ADC (GPIO 1)

```
+12 V ──[ 100 kΩ 1% ]──┬──[ 1 kΩ ]── GPIO 1
                       ├──[ 18 kΩ 1% ]── GND
                       └──[ 100 nF ]──── GND
```

At 12.50 V the GPIO node is `12.50 × 18 / 118 ≈ 1.91 V`. Heartbeat line: `[Heartbeat] Central Active | Cabin Battery: … V`.

### 4.3 Zone 1 MOSFET (bench low-side only)

GPIO 12 → MOSFET module IN (or 1 kΩ to gate). Isolated 12 V LED strip between +12 V and drain; source to GND. 200 Hz dimming. After 10 min at 100% the logic-level FET should stay cool. An IRF520 will get hot at 3.3 V gate — do not use one.

### 4.4 Pump flyback

Inductive source on Ch 4 (GPIO 4). **1N5408 across the load**: cathode to +12 V, anode to the switched node. Toggle twenty times. Scope (optional): spike clamped near the rail.

### 4.5 Optocoupler (inverter sim)

GPIO **21** (Ch 14) → PC817 LED input. Continuity on the output: closed when the channel is on, open when off. No continuity from ESP32 GND to the output pins.

Cockpit SW5 is what drives this channel in the van. On this entrance breadboard, GPIO 21 only changes if you send a cockpit packet or drive the pin from a temporary mapping. For a first bench check you may jumper a momentary 3.3 V into the PC817 input through its module resistor, or add a one-line test mapping later. Do not use GPIO 15 (that is Zone 4 PWM).

---

## 5. Sign-off (before any PCB order)

| Test | Pass | A | B |
| :--- | :--- | :---: | :---: |
| ESP-NOW entrance → central | Button 0 toggles GPIO 12; seq increases | [ ] | [ ] |
| Diode-OR wake | Sleeps, wakes on Zone 1 / pump / EncSW | [ ] | — |
| Encoder | Button 7 dims focus zone; click = 100% | [ ] | [ ] |
| Shower | Double-click pump; GPIO 4 chirps; click cancels | [ ] | [ ] |
| Night | Button 5 clears dimmers; pump stays | [ ] | [ ] |
| NVS | Lights restore; pump stays off | [ ] | [ ] |
| No GPIO 9 / 38 / 48 LEDs | Status on D10; no RGB pins used | [ ] | [ ] |
| Sleep current | Optional; not via 3V3 | [ ] | — |
| Buck 5.00 V ± 0.05 V | Before connecting the S3 | — | [ ] |
| ADC ± 1.5% vs DMM | GPIO 1 divider | — | [ ] |
| FET cool at full PWM | LR7843 / D4184, not IRF520 | — | [ ] |
| Flyback | 1N5408 on pump load | — | [ ] |
| PC817 isolation | GPIO 21 path; output isolated | — | [ ] |

Still open after a green sheet (do not treat as van-ready): Phoenix MPT 0.5 vs pump inrush (H-11), DevKit RGB vs Ch 15/21 (H-09), hardcoded ESP-NOW keys (FW-16), 11-ch vs 24-ch PCB identity.

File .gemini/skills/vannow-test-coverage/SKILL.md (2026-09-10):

---
name: vannow-test-coverage
description: Compiles, runs, and generates code coverage statistics for the VanNOW C++ firmware (Central and Remote nodes) using native PlatformIO unit tests and manual GCC/Gcov compilation.
---

# VanNOW Firmware Tests and Code Coverage

Use this skill when you or the user needs to run unit tests, check test status, troubleshoot compilation errors in native mock targets, or measure/generate code coverage reports for the `central` and `remote` firmware projects.

---

## 1. Directory Structure

The firmware is written in C++ and organized as PlatformIO projects inside the `firmware/` directory:

- [central/](file:///home/daniel/Projects/vannow/firmware/central): Contains the main system controller firmware, handling 11 power output channels.
- [remote/](file:///home/daniel/Projects/vannow/firmware/remote): Contains the button, encoder, and power management logic for the wireless wall panel remotes.
- [lib/](file:///home/daniel/Projects/vannow/firmware/lib): Contains shared libraries:
  - `arduino_mock`: Fake Arduino runtime to run test suites on native desktop/host environments.
  - `protocol`: Defines the ESP-NOW payload structures.
  - `wireless`: Driver wrapper logic (excluded in native target tests).

---

## 2. Running Unit Tests via PlatformIO

Both the `central` and `remote` projects have a `native` environment in their respective `platformio.ini` files. This compiles and executes tests locally on the host machine.

### Central Firmware Tests
To run tests for the central module:
```bash
cd firmware/central
~/.platformio/penv/bin/pio test -e native
```

### Remote Firmware Tests
To run tests for the remote module:
```bash
cd firmware/remote
~/.platformio/penv/bin/pio test -e native
```

### Compilation Troubleshooting
If the native unit test execution in the `remote` folder fails to compile with errors like `fatal error: WirelessManager.h: No such file or directory`, make sure `RemoteSender.cpp` is excluded from the compilation filter in native mode.

Ensure the `src_filter` in [remote/platformio.ini](file:///home/daniel/Projects/vannow/firmware/remote/platformio.ini) matches:
```ini
[env:native]
...
src_filter = +<*> -<main.cpp> -<RemoteSender.cpp>
```
*(Since `RemoteSender.cpp` depends on the hardware-specific Wi-Fi stack in `lib/wireless`, it cannot be built natively and must be bypassed in native tests.)*

---

## 3. Measuring Code Coverage

To calculate statement (line) coverage on host builds:

### Automated Script (Recommended)
You can run the pre-configured script from anywhere in the workspace:
```bash
./.gemini/skills/vannow-test-coverage/scripts/run_coverage.py
```
This script compiles both projects with `--coverage` flags, executes their tests, extracts the line-by-line coverage counts using `gcov`, formats them into a markdown table, and automatically cleans up binary artifacts.

### Manual Coverage Build Workflow
If you need to perform the compilation and calculation steps manually:

#### 1. Compile Central Tests with Coverage
```bash
cd firmware/central
g++ -O0 -g --coverage \
  -I src -I test/test_channels -I ../lib/arduino_mock/src -I ../lib/protocol -I .pio/libdeps/native/Unity/src \
  src/Channel.cpp src/DigitalChannel.cpp src/DimmableChannel.cpp src/SystemController.cpp \
  ../lib/arduino_mock/src/Arduino.cpp .pio/libdeps/native/Unity/src/unity.c \
  test/test_channels/test_channels.cpp -o test_channels_cov
```

#### 2. Run Central Tests & Generate Data
```bash
./test_channels_cov
gcov test_channels_cov-Channel.gcda test_channels_cov-DigitalChannel.gcda test_channels_cov-DimmableChannel.gcda test_channels_cov-SystemController.gcda
```

#### 3. Compile Remote Tests with Coverage
```bash
cd ../remote
g++ -O0 -g --coverage \
  -I src -I test/test_remote_handlers -I ../lib/arduino_mock/src -I ../lib/protocol -I .pio/libdeps/native/Unity/src \
  src/ButtonHandler.cpp src/EncoderHandler.cpp src/PowerManager.cpp \
  ../lib/arduino_mock/src/Arduino.cpp .pio/libdeps/native/Unity/src/unity.c \
  test/test_remote_handlers/test_remote_handlers.cpp -o test_remote_handlers_cov
```

#### 4. Run Remote Tests & Generate Data
```bash
./test_remote_handlers_cov
gcov test_remote_handlers_cov-ButtonHandler.gcda test_remote_handlers_cov-EncoderHandler.gcda test_remote_handlers_cov-PowerManager.gcda
```

---

## 4. Hardware/SDK Exclusions
The following components cannot be run in host native test targets and must be verified in system/integration tests on actual target microcontrollers:
1. **`lib/wireless/src/WirelessManager.cpp`**: Employs ESP32 SDK functions (`esp_now_init`, `esp_now_send`, etc.) to setup Wi-Fi station mode.
2. **`remote/src/RemoteSender.cpp`**: Uses the `WirelessManager` library to transmit actions over ESP-NOW.
3. **`main.cpp` entry points**: Boots the hardware, configures pins, registers interrupts, and handles low-level setup.

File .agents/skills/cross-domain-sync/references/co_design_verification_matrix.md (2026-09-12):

# Cross-Domain Co-Design Verification Matrix

Authoritative **24-channel** mapping after the 2026-09-11 logic audit (`VANNOW_CHANNEL_PROFILE=24`, env `esp32-s3-devkitc-1`).

The 11-channel PROFET carrier (`VanCentralControllerPROFET`, 150×95 mm) is legacy. Flash it only with `pio run -d firmware/central -e esp32-s3-profet-11ch` (`VANNOW_CHANNEL_PROFILE=11`). Do not put the 24-ch image on that board.

---

## 1. Central Controller 24-Channel Alignment Matrix

| System Channel | Atopile Net / Stage | DevKit GPIO | Firmware (`DEFAULT_24CH_CONFIG`) | Type | Notes |
| :--- | :--- | :---: | :--- | :--- | :--- |
| **Ch 0** Zone 1 lights | `led_zone1` | 12 | `Lights Zone 1` | Dimmable 200 Hz | |
| **Ch 1** Zone 2 lights | `led_zone2` | 13 | `Lights Zone 2` | Dimmable 200 Hz | |
| **Ch 2** Zone 3 lights | `led_zone3` | 14 | `Lights Zone 3` | Dimmable 200 Hz | |
| **Ch 3** Zone 4 lights | `led_zone4` | 15 | `Lights Zone 4` | Dimmable 200 Hz | |
| **Ch 4** Water pump | `pump` + 1N5408 | 4 | `Water Pump` | Digital, 10 min auto-off, no restore | Shower via DoubleClick / first StartHold |
| **Ch 5** Exterior driver | `ext_driver` | 5 | `Exterior Driver Light` | Digital | Cockpit SW1 |
| **Ch 6** Exterior passenger | `ext_passenger` | 6 | `Exterior Passenger Light` | Digital | |
| **Ch 7** Lightbar | `lightbar` | 7 | `Aux Lightbar / Roof` | Digital | |
| **Ch 8** Maxxair 12 V | `fan_pwr` + 1N5408 | 17 | `Maxxair Fan Power` | Digital | Cockpit SW6 |
| **Ch 9** Aux 1 boiler | `aux_pwr1` | 8 | `Aux Power 1 (Boiler)` | Digital | |
| **Ch 10** Aux 2 grey valve | `aux_pwr2` | 9 | `Aux Power 2 (Grey Valve)` | Digital | no restore |
| **Ch 11** Aux 3 tank heat | `aux_pwr3` | 10 | `Aux Power 3 (Tank Heat)` | Digital | no restore |
| **Ch 12** Aux 4 sockets | `aux_pwr4` | 11 | `Aux Power 4 (Aux Sockets)` | Digital | |
| **Ch 13** Aux 5 awning | `aux_pwr5` | 18 | `Aux Power 5 (Awning)` | Digital | |
| **Ch 14** MultiPlus remote | `inverter_opto` | 21 | `Inverter (Multiplus II)` | Digital | Cockpit SW5 |
| **Ch 15** Orion-XS #1 | `orion1_opto` | 38 | `DC-DC Orion-XS #1` | Digital | Shares DevKit v1.1 RGB LED |
| **Ch 16** Orion-XS #2 | `orion2_opto` | 39 | `DC-DC Orion-XS #2` | Digital | |
| **Ch 17** SmartSolar | `mppt_opto` | 40 | `SmartSolar MPPT` | Digital | |
| **Ch 18** Diesel heater | `heater_opto` | 41 | `Diesel Heater` | Digital | thermostat contact only |
| **Ch 19** Fridge | `fridge_opto` | 42 | `12V Fridge Compressor` | Digital | |
| **Ch 20** Maxxair keypad | `fan_pulse_opto` | 47 | `Maxxair Keypad Pulse` | Pulse 250 ms | |
| **Ch 21** Alarm | `aux_sig1_opto` | 48 | `Aux Signal 1 (Alarm)` | Digital | Shares DevKit v1.0 RGB LED |
| **Ch 22** LPG valve | `aux_sig2_opto` | 2 | `Aux Signal 2 (LPG Valve)` | Digital | no restore |
| **Ch 23** Generator start | `aux_sig3_opto` | 16 | `Aux Signal 3 (Gen Start)` | Pulse 500 ms | |
| **ADC** cabin battery | `voltage_sensor` | 1 | `BATTERY_ADC_PIN = 1` | 100k/18k + BAT54S clamp | |

PCB: `hardware/central-pcb/layouts/profet_24ch/` — 180 mm × 110 mm, M3 holes at (±85 mm, ±50 mm) / 170 × 100 mm pitch. Enclosure: `central_24ch_*` 205 × 135 mm.

---

## 2. Entrance Remote Alignment Matrix

| Control | Atopile | XIAO pin | Firmware | Wake | Central mapping |
| :--- | :--- | :--- | :--- | :--- | :--- |
| Diode-OR bus | `wakeup_line` | GPIO 0 (D0) | pull-up only | LP EXT1 | — |
| Encoder A | `ENC_A` | GPIO 1 (D1) | `EncoderHandler` pin A | LP EXT1 | button 7 `EncoderTurn` → focused zone |
| Encoder B | `ENC_B` | GPIO 2 (D2) | `EncoderHandler` pin B | LP EXT1 | button 7 |
| Encoder SW | `ENC_SW` | GPIO 20 (D9) | `EncoderHandler` pin SW **only** | via Diode-OR | button 7 `Click` → 100% boost |
| Zone 1 | `btn_zone1` | GPIO 21 (D3) | button 0 | via Diode-OR | Ch 0 |
| Zone 2 | `btn_zone2` | GPIO 22 (D4) | button 1 | via Diode-OR | Ch 1 |
| Zone 3 | `btn_zone3` | GPIO 23 (D5) | button 2 | via Diode-OR | Ch 2 |
| Zone 4 | `btn_zone4` | GPIO 16 (D6) | button 3 | via Diode-OR | Ch 3 |
| Water pump | `btn_pump` | GPIO 17 (D7) | button 4 | via Diode-OR | Ch 4 |
| Night shutdown | `btn_night` | GPIO 19 (D8) | button 5 | via Diode-OR | `TurnOffAllLights` |
| Status LED | `status_led` | **GPIO 18 (D10)** | `STATUS_LED_PIN 18` | — | — |

Build: `pio run -d firmware/remote -e seeed_xiao_esp32c6` (`REMOTE_ID=1`).

---

## 3. Cockpit Hub Alignment Matrix

| Switch | Atopile | XIAO pin | Firmware (latching edges) | Central mapping |
| :--- | :--- | :--- | :--- | :--- |
| Wake bus | `wakeup_line` | GPIO 0 (D0) | pull-up | — |
| SW1 | `ch1` | GPIO 1 (D1) | button 0 | Ch 5 exterior |
| SW2 | `ch2` | GPIO 2 (D2) | button 1 | Ch 15 Orion #1 |
| SW3 | `ch3` | GPIO 21 (D3) | button 2 | Ch 0 Zone 1 |
| SW4 | `ch4` | GPIO 22 (D4) | button 3 | Ch 4 pump |
| SW5 | `ch5` | GPIO 23 (D5) | button 4 | Ch 14 inverter |
| SW6 | `ch6` | GPIO 16 (D6) | button 5 | Ch 8 Maxxair power |
| Status LED | `status_led` | GPIO 18 (D10) | `STATUS_LED_PIN 18` | — |

Build: `pio run -d firmware/remote -e cockpit_xiao_esp32c6` (`REMOTE_ID=3`). Inputs are **latching**: Click on each edge, no `StartHold`.

---

## 4. Pre-Sync Audit Checklist

- [ ] Pin change in `central.ato` → `SystemController.cpp` `DEFAULT_24CH_CONFIG` + this matrix + `pio test -e native`
- [ ] Pin change in `entrance_remote.ato` / `cockpit.ato` → `firmware/remote/src/main.cpp`
- [ ] PCB outline change → `generate_enclosures.py` standoff pitch
- [ ] Do not flash 24-channel firmware onto the 11-channel PROFET carrier

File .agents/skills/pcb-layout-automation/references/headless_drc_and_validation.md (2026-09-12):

# Headless DRC

A DRC-clean 11-channel board does **not** validate 24-channel firmware. Run DRC on the PCB that will be ordered.

## Commands

```bash
# Production 24-channel
flatpak run --command=kicad-cli org.kicad.KiCad pcb drc \
  --output hardware/central-pcb/layouts/profet_24ch/drc_report.txt \
  --severity-all \
  hardware/central-pcb/layouts/profet_24ch/profet_24ch.kicad_pcb

# Legacy 11-channel
flatpak run --command=kicad-cli org.kicad.KiCad pcb drc \
  --output hardware/central-pcb/layouts/profet/profet-drc.rpt \
  --severity-all \
  hardware/central-pcb/layouts/profet/profet.kicad_pcb

# Remotes
flatpak run --command=kicad-cli org.kicad.KiCad pcb drc \
  --output hardware/entrance-remote-pcb/layouts/default/drc_report.txt \
  --severity-all \
  hardware/entrance-remote-pcb/layouts/default/default.kicad_pcb
```

Native fallback: `kicad-cli pcb drc --output … --severity-all <pcb>`.

KiCad 8+ may support `--schematic-parity`. Use it when an Atopile netlist is exported; the 24-channel script historically created pads that were not in `*.ato` — that gap is closed for load terminals, keep it closed.

## Parse gate

Accept only reports with `Found 0 DRC violations` and `Found 0 unconnected pads` (or equivalent `Total violations: 0` / `Unconnected items: 0`). Fail the script if either count is non-zero.

Do not ignore courtyard collisions on PROFETs or Phoenix blocks. Ignoring “footprint has no courtyard” is acceptable if the project already excludes that check.

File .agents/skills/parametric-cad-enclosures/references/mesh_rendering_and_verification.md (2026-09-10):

# Headless CAD Mesh Rendering & Verification Architecture

This reference explains the mathematical foundation, performance optimizations, and implementation details of headless 3D CAD mesh rendering for automated design verification.

---

## 1. Why Matplotlib `mplot3d` Fails for CAD Enclosures

Standard Matplotlib 3D (`mpl_toolkits.mplot3d`) uses a naive **Painter's Algorithm**:
1. Triangles are sorted strictly by the Euclidean distance from the camera to the triangle centroid.
2. Polygons are then drawn sequentially from furthest to nearest.

### Fatal Flaws on Non-Convex Geometry
* **Cyclic Overlaps:** In hollow boxes, interior standoffs, and screw holes, triangle $A$ can be partially in front of $B$, while $B$ is in front of $C$, and $C$ is in front of $A$. Centroid sorting breaks down completely.
* **Lack of Z-Buffering:** Because there is no per-pixel depth test, back faces frequently draw over front faces, resulting in inside-out, transparent, or "broken" visuals.
* **Tessellation Clutter:** Calling `Poly3DCollection(..., edgecolors=...)` renders every Delaunay triangulation seam generated by OpenCASCADE across flat planar faces, cluttering the image with spiderweb artifacts.

---

## 2. Software Z-Buffer Rasterizer Architecture

A vectorized software rasterizer implemented with pure NumPy and Pillow delivers **100% solid, artifact-free, sub-second renders** without requiring X11, EGL, or heavy GPU drivers.

```mermaid
flowchart LR
    A["STL Mesh Input"] --> B["Camera Transformation & Screen Projection"]
    B --> C["Backface Culling (cross2d < 0)"]
    C --> D["Three-Point Blinn-Phong Shading"]
    D --> E["Rasterization Loop (Barycentric Z-Buffer)"]
    E --> F["CAD Feature Crease Edge Overlay"]
    F --> G["Multi-View Technical Sheet Output"]
```

---

## 3. Mathematical Formulation

### 1. Screen Projection
Given world vertices $V_{world}$ centered at origin, camera rotation $R = R_x(\theta_{elev}) R_z(\phi_{azim})$:
$$V_{cam} = R \cdot V_{world}$$
Scale to fit image dimensions $W \times H$:
$$\text{scale} = 0.82 \cdot \frac{\min(W, H)}{\max(\text{span}_X, \text{span}_Y)}$$
$$X_{screen} = X_{cam} \cdot \text{scale} + \frac{W}{2}$$
$$Y_{screen} = -Y_{cam} \cdot \text{scale} + \frac{H}{2} \quad (\text{inverted for pixel space})$$
$$Z_{screen} = -Z_{cam} \quad (\text{smaller/more negative is closer})$$

### 2. Screen-Space Backface Culling
With inverted $Y_{screen}$, standard counter-clockwise winding yields:
$$\text{cross2d} = (X_1 - X_0)(Y_2 - Y_0) - (Y_1 - Y_0)(X_2 - X_0)$$
$$\text{Visible} \iff \text{cross2d} < 0$$
This instantly culls $>50\%$ of all polygons without testing per-pixel depth.

### 3. Three-Point Blinn-Phong Lighting
In camera coordinates where $+Z_{cam}$ points towards the viewer:
* **Key Light:** $L_{key} = [0.45, -0.35, 0.82]^T$ (upper-right front)
* **Fill Light:** $L_{fill} = [-0.50, 0.40, 0.75]^T$ (upper-left front)
* **Half-Vector:** $H = \frac{L_{key} + V}{\|L_{key} + V\|}$ where $V = [0, 0, 1]^T$

$$\text{Intensity} = K_a + K_d \cdot \max(0, N \cdot L_{key}) + K_f \cdot \max(0, N \cdot L_{fill}) + K_s \cdot (\max(0, N \cdot H))^p$$
Recommended coefficients: $K_a = 0.28, K_d = 0.58, K_f = 0.20, K_s = 0.22, p = 20$.

### 4. Vectorized Barycentric Rasterization
For each triangle with bounding box $[X_{min}, X_{max}] \times [Y_{min}, Y_{max}]$:
$$w_0 = \frac{(Y_1 - Y_2)(x - X_2) + (X_2 - X_1)(y - Y_2)}{\text{denom}}$$
$$w_1 = \frac{(Y_2 - Y_0)(x - X_2) + (X_0 - X_2)(y - Y_2)}{\text{denom}}$$
$$w_2 = 1 - w_0 - w_1$$
A pixel is inside if $w_0 \ge 0 \land w_1 \ge 0 \land w_2 \ge 0$.
Interpolate depth: $Z_{frag} = w_0 Z_0 + w_1 Z_1 + w_2 Z_2$.
Update pixel if $Z_{frag} < Z_{buffer}[y, x]$.

---

## 4. Feature Crease Edge Detection

To render crisp technical CAD lines without triangulation noise:
1. Identify true geometric crease edges where the dihedral angle between adjacent faces exceeds $30^\circ$:
   ```python
   crease_mask = mesh.face_adjacency_angles > np.radians(30)
   crease_edges = mesh.face_adjacency_edges[crease_mask]
   ```
2. Depth-test crease edge midpoints against the rasterized Z-buffer:
   ```python
   if Z_mid <= Z_buffer[y_mid, x_mid] + tolerance:
       draw.line([(x0, y0), (x1, y1)], fill=dark_ink_color, width=1)
   ```
This ensures hidden internal crease edges are suppressed while visible profile and step lines are rendered sharply.

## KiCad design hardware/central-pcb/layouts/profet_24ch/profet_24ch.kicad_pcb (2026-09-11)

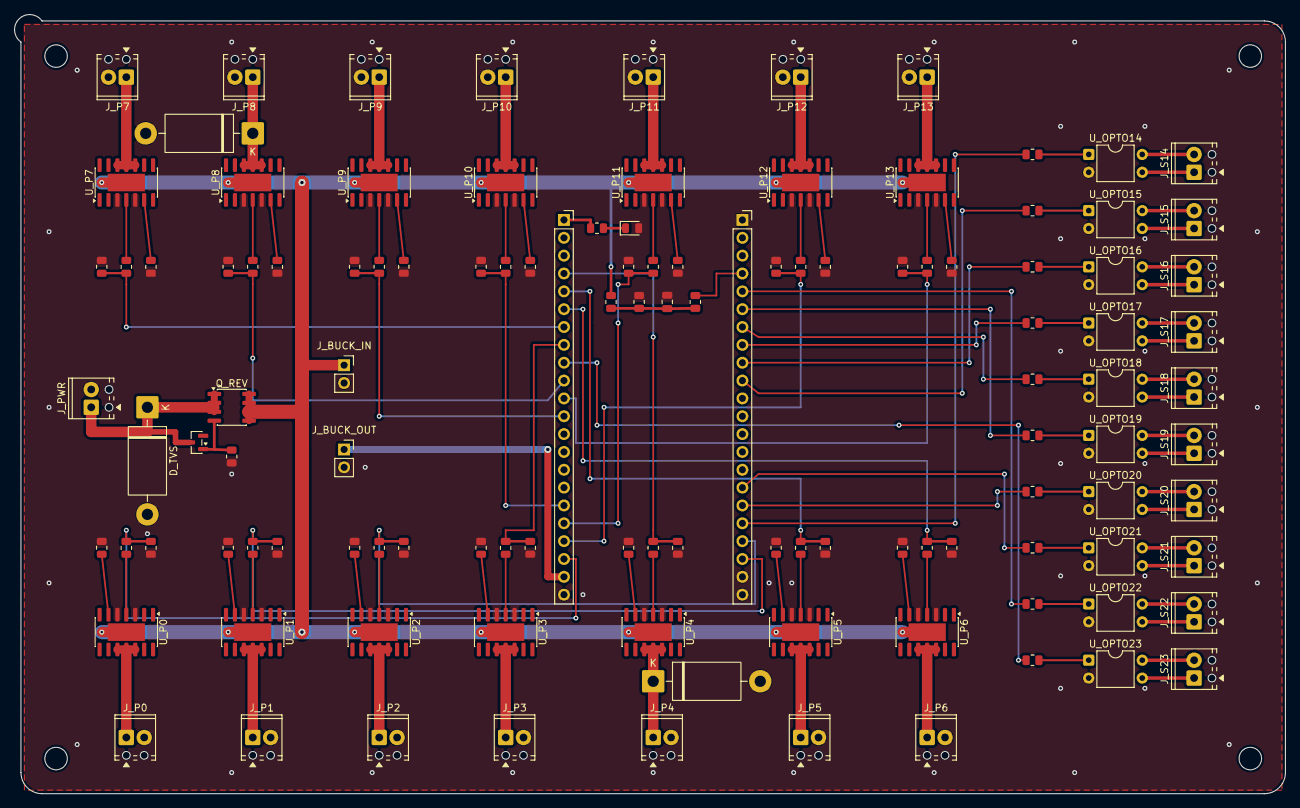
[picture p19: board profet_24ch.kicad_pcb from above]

Board: 2 copper layers, 180.9 x 110.9 mm, 117 parts (0 on the bottom side), 105 nets.

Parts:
C_FILT: C_0805_2012Metric
D_FAN: D_DO-201AD_P15.24mm_Horizontal
D_PUMP: D_DO-201AD_P15.24mm_Horizontal
D_PWR: LED_0805_2012Metric
D_TVS: D_DO-201AD_P15.24mm_Horizontal
J_BUCK_IN: PinSocket_1x02_P2.54mm_Vertical
J_BUCK_OUT: PinSocket_1x02_P2.54mm_Vertical
J_MCU_L: PinSocket_1x22_P2.54mm_Vertical
J_MCU_R: PinSocket_1x22_P2.54mm_Vertical
J_P0, J_P1, J_P2, J_P3, J_P4, J_P5, J_P6, J_P7, J_P8, J_P9, J_P10, J_P11, J_P12, J_P13: TerminalBlock_Phoenix_MPT-0,5-2-2.54_1x02_P2.54mm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; TerminalBlock_Phoenix_MPT-0,5-2-2.54_1x02_P2.54mm_Horizontal
J_PWR: TerminalBlock_Phoenix_MPT-0,5-2-2.54_1x02_P2.54mm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; TerminalBlock_Phoenix_MPT-0,5-2-2.54_1x02_P2.54mm_Horizontal
J_S14, J_S15, J_S16, J_S17, J_S18, J_S19, J_S20, J_S21, J_S22, J_S23: TerminalBlock_Phoenix_MPT-0,5-2-2.54_1x02_P2.54mm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; TerminalBlock_Phoenix_MPT-0,5-2-2.54_1x02_P2.54mm_Horizontal
Q_REV: SOIC-8_3.9x4.9mm_P1.27mm
R_ADC: R_0805_2012Metric
R_CS0, R_CS1, R_CS2, R_CS3, R_CS4, R_CS5, R_CS6, R_CS7, R_CS8, R_CS9, R_CS10, R_CS11, R_CS12, R_CS13: R_0805_2012Metric
R_DIV_H: R_0805_2012Metric
R_DIV_L: R_0805_2012Metric
R_G0, R_G1, R_G2, R_G3, R_G4, R_G5, R_G6, R_G7, R_G8, R_G9, R_G10, R_G11, R_G12, R_G13: R_0805_2012Metric
R_OPTO14, R_OPTO15, R_OPTO16, R_OPTO17, R_OPTO18, R_OPTO19, R_OPTO20, R_OPTO21, R_OPTO22, R_OPTO23: R_0805_2012Metric
R_PD0, R_PD1, R_PD2, R_PD3, R_PD4, R_PD5, R_PD6, R_PD7, R_PD8, R_PD9, R_PD10, R_PD11, R_PD12, R_PD13: R_0805_2012Metric
R_PMOS: R_0805_2012Metric
R_PWR: R_0805_2012Metric
U_OPTO14, U_OPTO15, U_OPTO16, U_OPTO17, U_OPTO18, U_OPTO19, U_OPTO20, U_OPTO21, U_OPTO22, U_OPTO23: DIP-4_W7.62mm
U_P0, U_P1, U_P2, U_P3, U_P4, U_P5, U_P6, U_P7, U_P8, U_P9, U_P10, U_P11, U_P12, U_P13: SOIC-14-1EP_3.9x8.7mm_P1.27mm_EP4.3x4.7mm
Z_PMOS: SOT-23

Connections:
+3V3: J_MCU_L.1, R_PWR.1
+5V: J_BUCK_OUT.1, J_MCU_L.21
+12V: J_BUCK_IN.1, Q_REV.5, Q_REV.6, Q_REV.7, Q_REV.8, R_DIV_H.2, U_P0.15, U_P1.15, U_P2.15, U_P3.15, U_P4.15, U_P5.15, U_P6.15, U_P7.15, U_P8.15, U_P9.15, U_P10.15, U_P11.15, U_P12.15, U_P13.15
+12V_RAW: D_TVS.1, J_PWR.1, Q_REV.1, Q_REV.2, Q_REV.3, Z_PMOS.3
CH0_CTRL: J_MCU_L.20, R_G0.1, R_PD0.1
CH0_IN: R_G0.2, U_P0.4
CH0_IS: R_CS0.1, U_P0.6
CH0_OUT: J_P0.1, U_P0.10, U_P0.11, U_P0.12
CH1_CTRL: J_MCU_R.20, R_G1.1, R_PD1.1
CH1_IN: R_G1.2, U_P1.4
CH1_IS: R_CS1.1, U_P1.6
CH1_OUT: J_P1.1, U_P1.10, U_P1.11, U_P1.12
CH2_CTRL: J_MCU_R.19, R_G2.1, R_PD2.1
CH2_IN: R_G2.2, U_P2.4
CH2_IS: R_CS2.1, U_P2.6
CH2_OUT: J_P2.1, U_P2.10, U_P2.11, U_P2.12
CH3_CTRL: J_MCU_L.8, R_G3.1, R_PD3.1
CH3_IN: R_G3.2, U_P3.4
CH3_IS: R_CS3.1, U_P3.6
CH3_OUT: J_P3.1, U_P3.10, U_P3.11, U_P3.12
CH4_CTRL: J_MCU_L.4, R_G4.1, R_PD4.1
CH4_IN: R_G4.2, U_P4.4
CH4_IS: R_CS4.1, U_P4.6
CH4_OUT: D_PUMP.1, J_P4.1, U_P4.10, U_P4.11, U_P4.12
CH5_CTRL: J_MCU_L.5, R_G5.1, R_PD5.1
CH5_IN: R_G5.2, U_P5.4
CH5_IS: R_CS5.1, U_P5.6
CH5_OUT: J_P5.1, U_P5.10, U_P5.11, U_P5.12
CH6_CTRL: J_MCU_L.6, R_G6.1, R_PD6.1
CH6_IN: R_G6.2, U_P6.4
CH6_IS: R_CS6.1, U_P6.6
CH6_OUT: J_P6.1, U_P6.10, U_P6.11, U_P6.12
CH7_CTRL: J_MCU_L.7, R_G7.1, R_PD7.1
CH7_IN: R_G7.2, U_P7.4
CH7_IS: R_CS7.1, U_P7.6
CH7_OUT: J_P7.1, U_P7.10, U_P7.11, U_P7.12
CH8_CTRL: J_MCU_L.10, R_G8.1, R_PD8.1
CH8_IN: R_G8.2, U_P8.4
CH8_IS: R_CS8.1, U_P8.6
CH8_OUT: D_FAN.1, J_P8.1, U_P8.10, U_P8.11, U_P8.12
CH9_CTRL: J_MCU_L.12, R_G9.1, R_PD9.1
CH9_IN: R_G9.2, U_P9.4
CH9_IS: R_CS9.1, U_P9.6
CH9_OUT: J_P9.1, U_P9.10, U_P9.11, U_P9.12
CH10_CTRL: J_MCU_L.17, R_G10.1, R_PD10.1
CH10_IN: R_G10.2, U_P10.4
CH10_IS: R_CS10.1, U_P10.6
CH10_OUT: J_P10.1, U_P10.10, U_P10.11, U_P10.12
CH11_CTRL: J_MCU_L.18, R_G11.1, R_PD11.1
CH11_IN: R_G11.2, U_P11.4
CH11_IS: R_CS11.1, U_P11.6
CH11_OUT: J_P11.1, U_P11.10, U_P11.11, U_P11.12
CH12_CTRL: J_MCU_L.19, R_G12.1, R_PD12.1
CH12_IN: R_G12.2, U_P12.4
CH12_IS: R_CS12.1, U_P12.6
CH12_OUT: J_P12.1, U_P12.10, U_P12.11, U_P12.12
CH13_CTRL: J_MCU_L.11, R_G13.1, R_PD13.1
CH13_IN: R_G13.2, U_P13.4
CH13_IS: R_CS13.1, U_P13.6
CH13_OUT: J_P13.1, U_P13.10, U_P13.11, U_P13.12
CH14_ANODE: R_OPTO14.2, U_OPTO14.1
CH14_C: J_S14.2, U_OPTO14.4
CH14_CTRL: J_MCU_R.18, R_OPTO14.1
CH14_E: J_S14.1, U_OPTO14.3
CH15_ANODE: R_OPTO15.2, U_OPTO15.1
CH15_C: J_S15.2, U_OPTO15.4
CH15_CTRL: J_MCU_R.10, R_OPTO15.1
CH15_E: J_S15.1, U_OPTO15.3
CH16_ANODE: R_OPTO16.2, U_OPTO16.1
CH16_C: J_S16.2, U_OPTO16.4
CH16_CTRL: J_MCU_R.9, R_OPTO16.1
CH16_E: J_S16.1, U_OPTO16.3
CH17_ANODE: R_OPTO17.2, U_OPTO17.1
CH17_C: J_S17.2, U_OPTO17.4
CH17_CTRL: J_MCU_R.8, R_OPTO17.1
CH17_E: J_S17.1, U_OPTO17.3
CH18_ANODE: R_OPTO18.2, U_OPTO18.1
CH18_C: J_S18.2, U_OPTO18.4
CH18_CTRL: J_MCU_R.7, R_OPTO18.1
CH18_E: J_S18.1, U_OPTO18.3
CH19_ANODE: R_OPTO19.2, U_OPTO19.1
CH19_C: J_S19.2, U_OPTO19.4
CH19_CTRL: J_MCU_R.6, R_OPTO19.1
CH19_E: J_S19.1, U_OPTO19.3
CH20_ANODE: R_OPTO20.2, U_OPTO20.1
CH20_C: J_S20.2, U_OPTO20.4
CH20_CTRL: J_MCU_R.17, R_OPTO20.1
CH20_E: J_S20.1, U_OPTO20.3
CH21_ANODE: R_OPTO21.2, U_OPTO21.1
CH21_C: J_S21.2, U_OPTO21.4
CH21_CTRL: J_MCU_R.16, R_OPTO21.1
CH21_E: J_S21.1, U_OPTO21.3
CH22_ANODE: R_OPTO22.2, U_OPTO22.1
CH22_C: J_S22.2, U_OPTO22.4
CH22_CTRL: J_MCU_R.5, R_OPTO22.1
CH22_E: J_S22.1, U_OPTO22.3
CH23_ANODE: R_OPTO23.2, U_OPTO23.1
CH23_C: J_S23.2, U_OPTO23.4
CH23_CTRL: J_MCU_L.9, R_OPTO23.1
CH23_E: J_S23.1, U_OPTO23.3
GND: C_FILT.2, D_FAN.2, D_PUMP.2, D_PWR.2, D_TVS.2, J_BUCK_IN.2, J_BUCK_OUT.2, J_MCU_L.22, J_MCU_R.1, J_MCU_R.21, J_MCU_R.22, J_P0.2, J_P1.2, J_P2.2, J_P3.2, J_P4.2, J_P5.2, J_P6.2, J_P7.2, J_P8.2, J_P9.2, J_P10.2, J_P11.2, J_P12.2, J_P13.2, J_PWR.2, R_CS0.2, R_CS1.2, R_CS2.2, R_CS3.2, R_CS4.2, R_CS5.2, R_CS6.2, R_CS7.2, R_CS8.2, R_CS9.2, R_CS10.2, R_CS11.2, R_CS12.2, R_CS13.2, R_DIV_L.2, R_PD0.2, R_PD1.2, R_PD2.2, R_PD3.2, R_PD4.2, R_PD5.2, R_PD6.2, R_PD7.2, R_PD8.2, R_PD9.2, R_PD10.2, R_PD11.2, R_PD12.2, R_PD13.2, R_PMOS.1, U_OPTO14.2, U_OPTO15.2, U_OPTO16.2, U_OPTO17.2, U_OPTO18.2, U_OPTO19.2, U_OPTO20.2, U_OPTO21.2, U_OPTO22.2, U_OPTO23.2, U_P0.3, U_P0.5, U_P1.3, U_P1.5, U_P2.3, U_P2.5, U_P3.3, U_P3.5, U_P4.3, U_P4.5, U_P5.3, U_P5.5, U_P6.3, U_P6.5, U_P7.3, U_P7.5, U_P8.3, U_P8.5, U_P9.3, U_P9.5, U_P10.3, U_P10.5, U_P11.3, U_P11.5, U_P12.3, U_P12.5, U_P13.3, U_P13.5
LED_PWR_A: D_PWR.1, R_PWR.2
PMOS_GATE: Q_REV.4, R_PMOS.2, Z_PMOS.1
V_BAT_ADC: J_MCU_R.4, R_ADC.2
V_BAT_DIV: C_FILT.1, R_ADC.1, R_DIV_H.1, R_DIV_L.1

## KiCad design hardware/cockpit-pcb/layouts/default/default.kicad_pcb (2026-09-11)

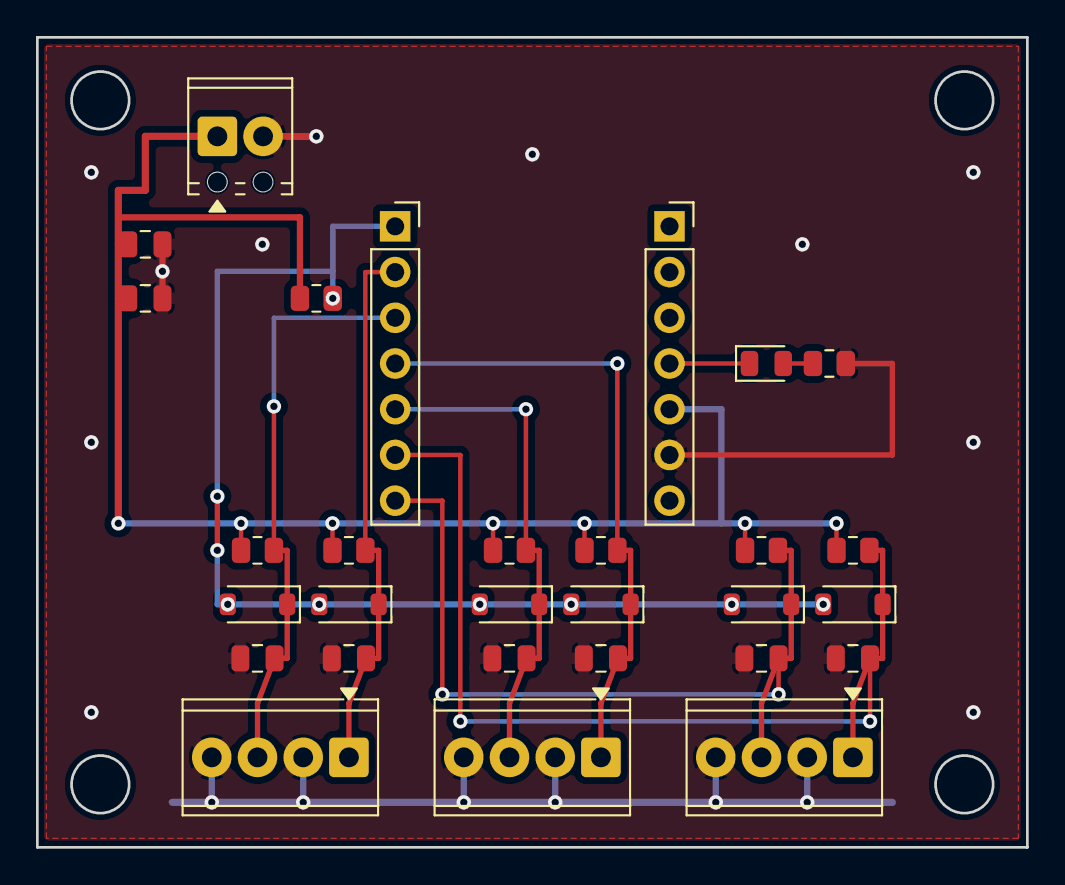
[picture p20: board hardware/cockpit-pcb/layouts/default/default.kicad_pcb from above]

Board: 2 copper layers, 55.0 x 45.0 mm, 29 parts (0 on the bottom side), 11 nets.

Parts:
C1, C2, C3, C4, C5, C6, C7, C8: C_0805_2012Metric
D1, D2, D3, D4, D5, D6: D_SOD-123
D7: LED_0805_2012Metric
J1: TerminalBlock_Phoenix_MPT-0,5-2-2.54_1x02_P2.54mm_Horizontal
J2, J3: PinSocket_1x07_P2.54mm_Vertical
J4, J5, J6: TerminalBlock_Phoenix_MPT-0,5-4-2.54_1x04_P2.54mm_Horizontal
R1, R2, R3, R4, R5, R6, R7, R8: R_0805_2012Metric

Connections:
1: C3.1, D1.1, J2.2, J4.1, R1.2
1-1: C5.1, D3.1, J2.4, J5.1, R3.2
1-2: C7.1, D5.1, J2.6, J6.1, R5.2
anode: D7.1, J3.4
cathode: D7.2, R7.1
gnd: C1.2, C2.2, C3.2, C4.2, C5.2, C6.2, C7.2, C8.2, J1.2, J3.6, J4.2, J4.4, J5.2, J5.4, J6.2, J6.4, R7.2
mcu_sense: C4.1, D2.1, J2.3, J4.3, R2.2
mcu_sense-1: C6.1, D4.1, J2.5, J5.3, R4.2
mcu_sense-2: C8.1, D6.1, J2.7, J6.3, R6.2
vcc: C1.1, C2.1, J1.1, J3.5, R1.1, R2.1, R3.1, R4.1, R5.1, R6.1, R8.1
wakeup_bus: D1.2, D2.2, D3.2, D4.2, D5.2, D6.2, J2.1, R8.2

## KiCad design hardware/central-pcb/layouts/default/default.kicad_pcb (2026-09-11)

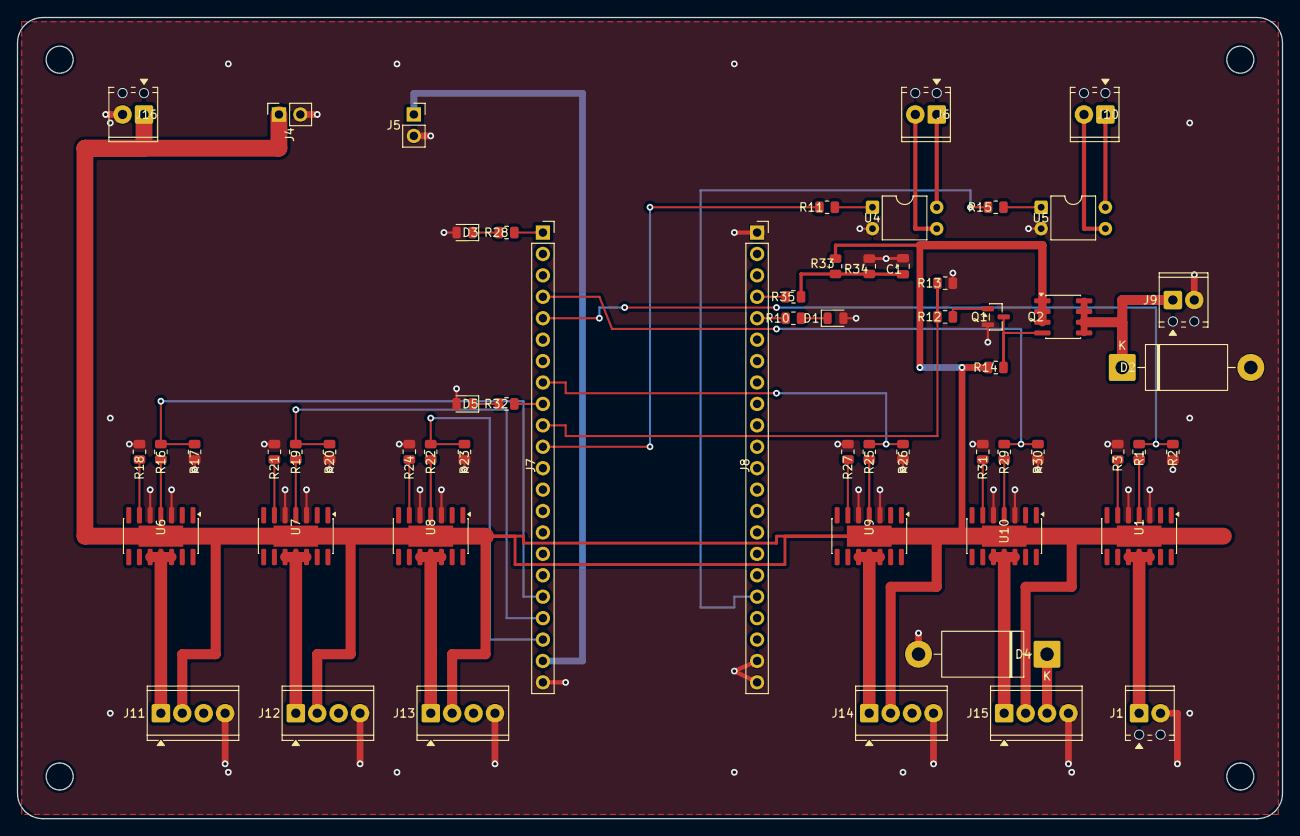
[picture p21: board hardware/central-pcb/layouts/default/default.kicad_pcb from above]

Board: 2 copper layers, 150.0 x 95.0 mm, 59 parts (0 on the bottom side), 48 nets.

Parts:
C1: C_0805_2012Metric
D1, D3, D5: LED_0805_2012Metric
D2, D4: D_DO-201AD_P15.24mm_Horizontal
J1, J6, J9, J10, J16: TerminalBlock_Phoenix_MPT-0,5-2-2.54_1x02_P2.54mm_Horizontal
J4, J5: PinSocket_1x02_P2.54mm_Vertical
J7, J8: PinSocket_1x22_P2.54mm_Vertical
J11, J12, J13, J14, J15: TerminalBlock_Phoenix_MPT-0,5-4-2.54_1x04_P2.54mm_Horizontal
Q1: SOT-23
Q2: SOIC-8_3.9x4.9mm_P1.27mm
R1, R2, R3, R10, R11, R12, R13, R14, R15, R16, R17, R18, R19, R20, R21, R22, R23, R24, R25, R26, R27, R28, R29, R30, R31, R32, R33, R34, R35: R_0805_2012Metric
U1, U6, U7, U8, U9, U10: SOIC-14-1EP_3.9x8.7mm_P1.27mm_EP4.3x4.7mm
U4, U5: DIP-4_W7.62mm

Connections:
1: J8.5, R10.1
1-1: J7.9, R32.1
1-2: J7.1, R28.1
1-3: D2.1, J9.1, Q2.5, Q2.6, Q2.7, Q2.8
anode: D1.1, R10.2
anode-1: D3.1, R28.2
anode-2: D5.1, R32.2
cathode: D4.1, J15.3
control: J7.5, R1.1, R2.1
control-3: J7.11, R11.1
control-4: J7.18, R16.1, R17.1
control-5: J7.19, R19.1, R20.1
control-6: J7.20, R22.1, R23.1
control-7: J7.8, R25.1, R26.1
control-8: J7.10, R12.1, R13.1
control-9: J8.18, R15.1
control-10: J7.4, R29.1, R30.1
current_sense: R3.1, U1.6
dcdc_opto-anode: R11.2, U4.1
drain: Q1.3, Q2.4, R14.1
gate: Q1.1, R12.2
gnd: C1.2, D1.2, D2.2, D3.2, D4.2, D5.2, J1.2, J4.2, J5.2, J7.22, J8.1, J8.21, J8.22, J9.2, J11.4, J12.4, J13.4, J14.4, J15.4, J16.2, Q1.2, R2.2, R3.2, R13.2, R17.2, R18.2, R20.2, R21.2, R23.2, R24.2, R26.2, R27.2, R30.2, R31.2, R34.2, U1.3, U1.5, U4.2, U5.2, U6.3, U6.5, U7.3, U7.5, U8.3, U8.5, U9.3, U9.5, U10.3, U10.5
input: R1.2, U1.4
inverter_opto-anode: R15.2, U5.1
led_zone1_stage-current_sense: R18.1, U6.6
led_zone1_stage-input: R16.2, U6.4
led_zone2_stage-current_sense: R21.1, U7.6
led_zone2_stage-input: R19.2, U7.4
led_zone3_stage-current_sense: R24.1, U8.6
led_zone3_stage-input: R22.2, U8.4
led_zone4_stage-current_sense: R27.1, U9.6
led_zone4_stage-input: R25.2, U9.4
out_collector: J6.1, U4.4
out_collector-1: J10.1, U5.4
out_emitter: J6.2, U4.3
out_emitter-1: J10.2, U5.3
power_in: J4.1, J11.2, J12.2, J13.2, J14.2, J15.2, J16.1, Q2.1, Q2.2, Q2.3, R14.2, R33.1, U1.15, U6.15, U7.15, U8.15, U9.15, U10.15
power_out: J1.1, U1.10, U1.11, U1.12
power_out-3: J11.1, U6.10, U6.11, U6.12
power_out-4: J12.1, U7.10, U7.11, U7.12
power_out-5: J13.1, U8.10, U8.11, U8.12
power_out-6: J14.1, U9.10, U9.11, U9.12
power_out-7: J15.1, U10.10, U10.11, U10.12
pump_stage-current_sense: R31.1, U10.6
pump_stage-input: R29.2, U10.4
v_mcu_5v: J5.1, J7.21
v_out: J8.4, R35.2
voltage_sensor-1: C1.1, R33.2, R34.1, R35.1

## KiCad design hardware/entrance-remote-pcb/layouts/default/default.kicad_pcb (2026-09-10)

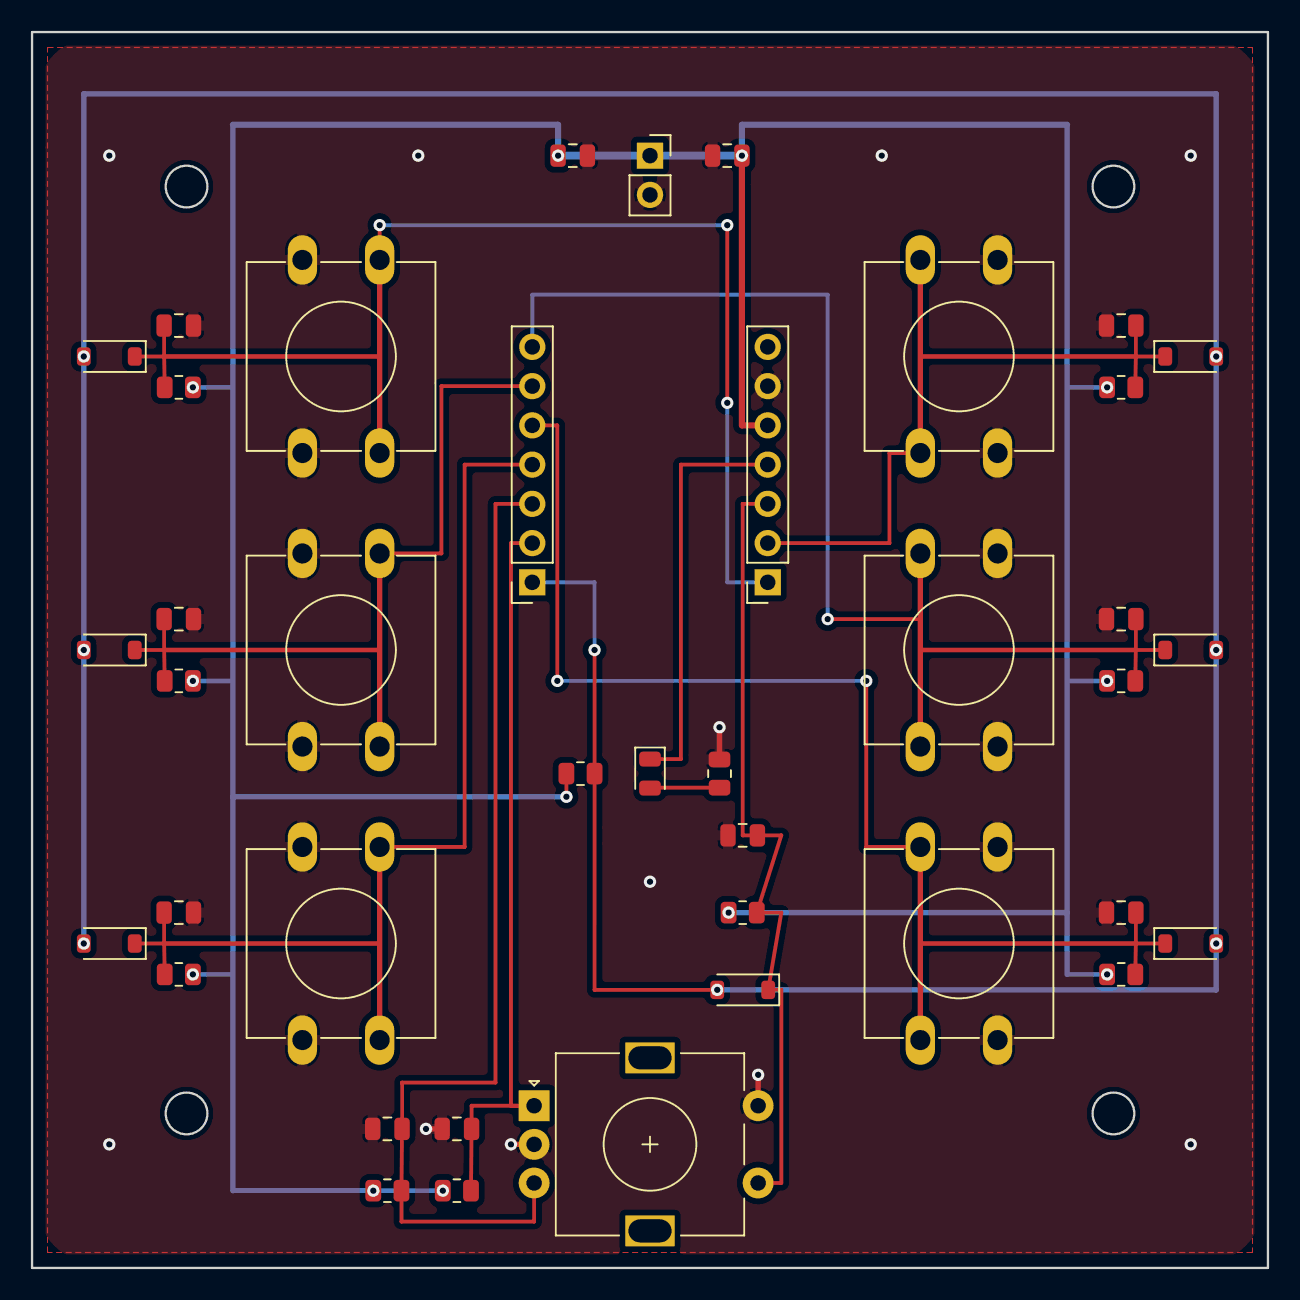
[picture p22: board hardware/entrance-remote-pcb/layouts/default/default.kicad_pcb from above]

Board: 2 copper layers, 80.0 x 80.0 mm, 40 parts (0 on the bottom side), 14 nets.

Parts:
C1, C2, C3, C4, C5, C6, C7, C8, C9, C10, C11: C_0805_2012Metric
D1, D2, D3, D4, D5, D6, D7: D_SOD-123
D8: LED_0805_2012Metric
J1: PinSocket_1x02_P2.54mm_Vertical
J2, J3: PinSocket_1x07_P2.54mm_Vertical
R1, R2, R3, R4, R5, R6, R7, R8, R9, R10, R11: R_0805_2012Metric
SW1, SW2, SW3, SW4, SW5, SW6: SW_PUSH-12mm
SW7: RotaryEncoder_Alps_EC11E-Switch_Vertical_H20mm

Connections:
1: C1.1, D1.1, J3.2, R1.2, SW1.1
1-1: C2.1, D2.1, J3.1, R2.2, SW2.1
1-2: C3.1, D3.1, J2.4, R3.2, SW3.1
1-3: C4.1, D4.1, J2.5, R4.2, SW4.1
1-4: C5.1, D5.1, J2.6, R5.2, SW5.1
1-5: C6.1, D6.1, J2.7, R6.2, SW6.1
1-6: C11.1, D7.1, J3.3, R9.2, SW7.S1
2: C1.2, C2.2, C3.2, C4.2, C5.2, C6.2, C7.2, C8.2, C9.2, C10.2, C11.2, J1.2, J3.6, R10.2, SW1.2, SW2.2, SW3.2, SW4.2, SW5.2, SW6.2, SW7.C, SW7.S2
A: C9.1, J2.2, R7.2, SW7.A
B: C10.1, J2.3, R8.2, SW7.B
anode: D8.1, J3.4
cathode: D8.2, R10.1
vcc: C7.1, C8.1, J1.1, J3.5, R1.1, R2.1, R3.1, R4.1, R5.1, R6.1, R7.1, R8.1, R9.1, R11.1
wakeup_bus: D1.2, D2.2, D3.2, D4.2, D5.2, D6.2, D7.2, J2.1, R11.2

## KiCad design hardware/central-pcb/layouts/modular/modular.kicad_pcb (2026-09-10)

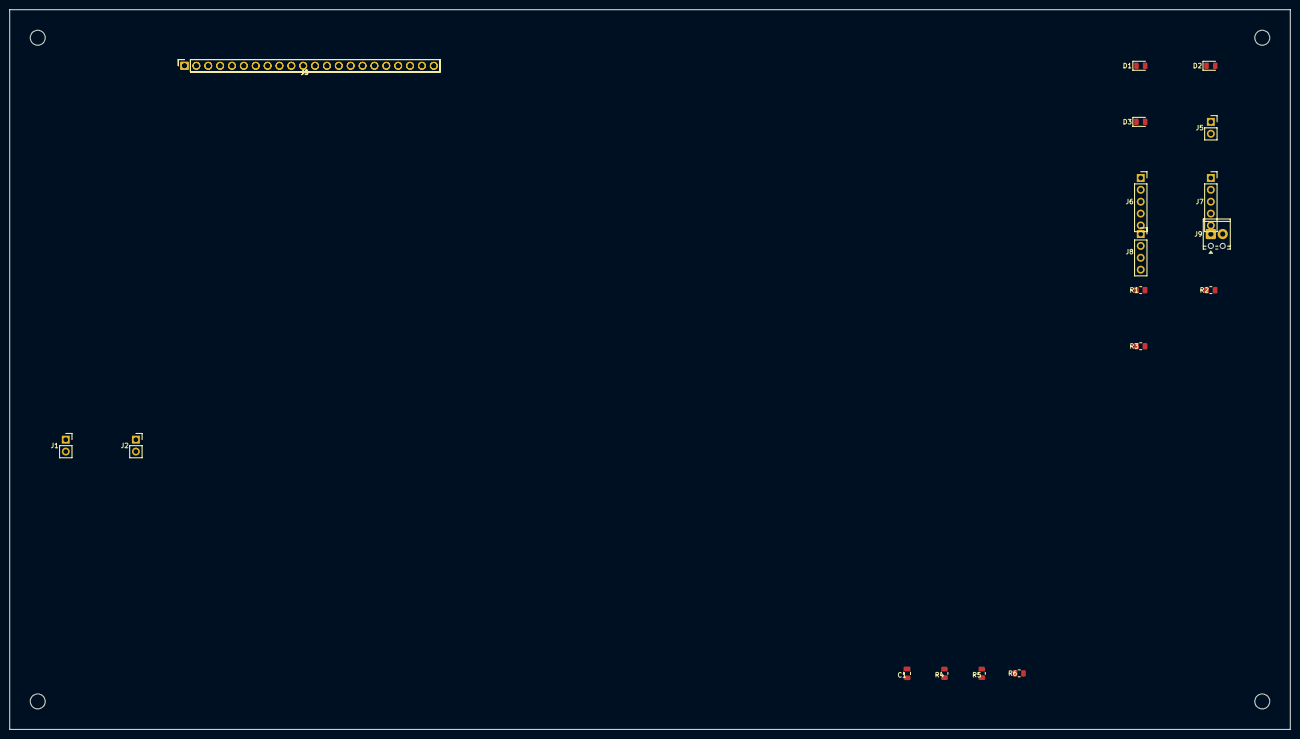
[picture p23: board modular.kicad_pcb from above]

Board: 2 copper layers, 274.0 x 154.0 mm, 19 parts (0 on the bottom side), 22 nets, no tracks yet.

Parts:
C1: C_0805_2012Metric
D1, D2, D3: LED_0805_2012Metric
J1, J2, J5: PinSocket_1x02_P2.54mm_Vertical
J3, J4: PinSocket_1x22_P2.54mm_Vertical
J6, J7: PinSocket_1x05_P2.54mm_Vertical
J8: PinSocket_1x04_P2.54mm_Vertical
J9: TerminalBlock_Phoenix_MPT-0,5-2-2.54_1x02_P2.54mm_Horizontal
R1, R2, R3, R4, R5, R6: R_0805_2012Metric

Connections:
1: J4.5, R1.1
1-1: J3.9, R3.1
1-2: J3.1, R2.1
2: C1.2, D1.2, D2.2, D3.2, J1.2, J2.2, J3.22, J4.1, J4.21, J4.22, J5.1, J6.1, J7.1, J8.1, J9.2, R5.2
2-1: J3.18, J6.2
2-2: J4.18, J8.2
2-3: J3.4, J7.2
2-4: J3.7, J5.2
3: J3.19, J6.3
3-1: J3.10, J7.3
3-2: J3.11, J8.3
4: J3.20, J6.4
4-1: J3.5, J7.4
5: J3.8, J6.5
5-1: J3.6, J7.5
anode: D1.1, R1.2
anode-1: D2.1, R2.2
anode-2: D3.1, R3.2
v_bat_12v: J1.1, J9.1, R4.1
v_mcu_5v: J2.1, J3.21
v_out: J4.4, R6.2
voltage_sensor-1: C1.1, R4.2, R5.1, R6.1

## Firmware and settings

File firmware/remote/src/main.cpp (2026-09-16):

/**
 * @file main.cpp
 * @brief Seeed Studio XIAO ESP32-C6 Remote Switch Panel (Battery Powered)
 *
 * Entrance panel (default) or Cockpit hub (build flag). Wakes from Deep Sleep,
 * stays awake 1.5 s for hold/turn events, then returns to sleep.
 */

#include <Arduino.h>
#include "BinaryMatrixHandler.h"
#include "ButtonHandler.h"
#include "EncoderHandler.h"
#include "PowerManager.h"
#include "RemoteSender.h"

#define PANEL_TYPE_BUTTONS  1
#define PANEL_TYPE_ENCODER  2
#define PANEL_TYPE_MATRIX   3
#define PANEL_TYPE_ENTRANCE 4
#define PANEL_TYPE_COCKPIT  5

#ifndef CONFIG_PANEL_TYPE
#define CONFIG_PANEL_TYPE PANEL_TYPE_ENTRANCE
#endif

#ifndef REMOTE_ID
#if (CONFIG_PANEL_TYPE == PANEL_TYPE_COCKPIT)
#define REMOTE_ID 3
#else
#define REMOTE_ID 1
#endif
#endif

uint8_t centralMacAddress[] = {0xAA, 0xBB, 0xCC, 0xDD, 0xEE, 0xFF};

#if (REMOTE_ID == 1)
const uint8_t myMacAddress[6] = {0xAA, 0xBB, 0xCC, 0xDD, 0xEE, 0x11};
#elif (REMOTE_ID == 2)
const uint8_t myMacAddress[6] = {0xAA, 0xBB, 0xCC, 0xDD, 0xEE, 0x22};
#elif (REMOTE_ID == 3)
const uint8_t myMacAddress[6] = {0xAA, 0xBB, 0xCC, 0xDD, 0xEE, 0x33};
#else
const uint8_t myMacAddress[6] = {0xAA, 0xBB, 0xCC, 0xDD, 0xEE, 0x11};
#endif

#define BATTERY_ADC_PIN 255
#define STATUS_LED_PIN  18  // XIAO ESP32-C6 D10 = GPIO 18 (not GPIO 9 / BOOT)
#define ENCODER_BUTTON_INDEX 7

void indicateAction(ActionType action, uint8_t buttonIdx) {
    pinMode(STATUS_LED_PIN, OUTPUT);
    if (buttonIdx == 4 && (action == ActionType::DoubleClick || action == ActionType::StartHold)) {
        for (int p = 0; p < 3; p++) {
            digitalWrite(STATUS_LED_PIN, HIGH);
            delay(80);
            digitalWrite(STATUS_LED_PIN, LOW);
            delay(80);
        }
    } else {
        digitalWrite(STATUS_LED_PIN, HIGH);
        delay(50);
        digitalWrite(STATUS_LED_PIN, LOW);
    }
}

#if (CONFIG_PANEL_TYPE == PANEL_TYPE_ENTRANCE)
ButtonHandler btnZone1(21, 0); // D3  Zone 1
ButtonHandler btnZone2(22, 1); // D4  Zone 2
ButtonHandler btnZone3(23, 2); // D5  Zone 3
ButtonHandler btnZone4(16, 3); // D6  Zone 4
ButtonHandler btnPump(17, 4);  // D7  Water Pump
ButtonHandler btnNight(19, 5); // D8  Master Night Shutdown
ButtonHandler* buttons[6] = {
    &btnZone1, &btnZone2, &btnZone3, &btnZone4, &btnPump, &btnNight
};
const uint8_t NUM_BUTTONS = 6;
EncoderHandler encoder(1, 2, 20); // D1 Enc A, D2 Enc B, D9 Enc SW (exclusive owner of GPIO 20)
const uint8_t wakeupPins[] = {0, 1, 2};

#elif (CONFIG_PANEL_TYPE == PANEL_TYPE_COCKPIT)
ButtonHandler sw1(1, 0, ButtonHandler::InputMode::Latching);  // D1 Exterior
ButtonHandler sw2(2, 1, ButtonHandler::InputMode::Latching);  // D2 Orion-XS #1
ButtonHandler sw3(21, 2, ButtonHandler::InputMode::Latching); // D3 Zone 1
ButtonHandler sw4(22, 3, ButtonHandler::InputMode::Latching); // D4 Water Pump
ButtonHandler sw5(23, 4, ButtonHandler::InputMode::Latching); // D5 Inverter
ButtonHandler sw6(16, 5, ButtonHandler::InputMode::Latching); // D6 Maxxair power
ButtonHandler* buttons[6] = { &sw1, &sw2, &sw3, &sw4, &sw5, &sw6 };
const uint8_t NUM_BUTTONS = 6;
const uint8_t wakeupPins[] = {0};

#elif (CONFIG_PANEL_TYPE == PANEL_TYPE_ENCODER)
EncoderHandler encoder(0, 1, 2);
const uint8_t wakeupPins[] = {0, 1, 2};

#elif (CONFIG_PANEL_TYPE == PANEL_TYPE_MATRIX)
BinaryMatrixHandler matrix(0, 1, 2);
const uint8_t wakeupPins[] = {0, 1, 2};

#else
ButtonHandler btn0(0, 0);
ButtonHandler btn1(1, 1);
ButtonHandler btn2(2, 2);
ButtonHandler* buttons[3] = { &btn0, &btn1, &btn2 };
const uint8_t NUM_BUTTONS = 3;
const uint8_t wakeupPins[] = {0, 1, 2};
#endif

const uint8_t NUM_WAKEUP_PINS = sizeof(wakeupPins) / sizeof(wakeupPins[0]);

PowerManager powerManager(1500);
RemoteSender remoteSender(REMOTE_ID, centralMacAddress, BATTERY_ADC_PIN);

void setup() {
    Serial.begin(115200);

#if (CONFIG_PANEL_TYPE == PANEL_TYPE_ENTRANCE)
    for (int i = 0; i < NUM_BUTTONS; i++) {
        buttons[i]->begin();
    }
    encoder.begin();
    pinMode(0, INPUT_PULLUP);
#elif (CONFIG_PANEL_TYPE == PANEL_TYPE_COCKPIT)
    for (int i = 0; i < NUM_BUTTONS; i++) {
        buttons[i]->begin();
    }
    pinMode(0, INPUT_PULLUP);
#elif (CONFIG_PANEL_TYPE == PANEL_TYPE_ENCODER)
    encoder.begin();
#elif (CONFIG_PANEL_TYPE == PANEL_TYPE_MATRIX)
    matrix.begin();
#else
    for (int i = 0; i < NUM_BUTTONS; i++) {
        buttons[i]->begin();
    }
#endif

    pinMode(STATUS_LED_PIN, OUTPUT);

    esp_sleep_wakeup_cause_t wakeupReason = esp_sleep_get_wakeup_cause();
    if (wakeupReason != ESP_SLEEP_WAKEUP_EXT1) {
        Serial.println("Cold boot detected. Providing visual confirmation and entering sleep.");
        digitalWrite(STATUS_LED_PIN, HIGH);
        delay(150);
        digitalWrite(STATUS_LED_PIN, LOW);
        powerManager.goToSleep(wakeupPins, NUM_WAKEUP_PINS);
    }

    if (!remoteSender.begin(myMacAddress)) {
        Serial.println("Fatal: Error initializing RemoteSender. Going to sleep.");
        remoteSender.persistSequence();
        powerManager.goToSleep(wakeupPins, NUM_WAKEUP_PINS);
    }

    powerManager.begin();
    Serial.println("Remote active. Listening for physical input transitions.");
}

void loop() {
#if (CONFIG_PANEL_TYPE == PANEL_TYPE_ENTRANCE)
    encoder.update();
    ActionType encAction;
    int8_t encSteps = 0;
    if (encoder.checkEvent(encAction, encSteps)) {
        powerManager.feed();
        remoteSender.send(encAction, ENCODER_BUTTON_INDEX, encSteps);
        indicateAction(encAction, ENCODER_BUTTON_INDEX);
    }

    for (int i = 0; i < NUM_BUTTONS; i++) {
        ActionType action;
        if (buttons[i]->checkEvent(action)) {
            powerManager.feed();
            remoteSender.send(action, i, 0);
            indicateAction(action, i);
        }
    }

#elif (CONFIG_PANEL_TYPE == PANEL_TYPE_COCKPIT)
    for (int i = 0; i < NUM_BUTTONS; i++) {
        ActionType action;
        if (buttons[i]->checkEvent(action)) {
            powerManager.feed();
            remoteSender.send(action, i, 0);
            indicateAction(action, i);
        }
    }

#elif (CONFIG_PANEL_TYPE == PANEL_TYPE_ENCODER)
    encoder.update();
    ActionType action;
    int8_t steps = 0;
    if (encoder.checkEvent(action, steps)) {
        powerManager.feed();
        remoteSender.send(action, 0, steps);
        indicateAction(action, 0);
    }

#elif (CONFIG_PANEL_TYPE == PANEL_TYPE_MATRIX)
    uint8_t buttonIdx = 0;
    ActionType action;
    if (matrix.checkEvent(buttonIdx, action)) {
        powerManager.feed();
        remoteSender.send(action, buttonIdx, 0);
        indicateAction(action, buttonIdx);
    }

#else
    for (int i = 0; i < NUM_BUTTONS; i++) {
        ActionType action;
        if (buttons[i]->checkEvent(action)) {
            powerManager.feed();
            remoteSender.send(action, i, 0);
            indicateAction(action, i);
        }
    }
#endif

    if (powerManager.isExpired()) {
        remoteSender.persistSequence();
        powerManager.goToSleep(wakeupPins, NUM_WAKEUP_PINS);
    }

    // FIX [MEDIUM-03]: Increased delay from 250µs to 5ms to reduce power consumption
    // Button debounce is 30ms, so 200 Hz loop rate (5ms) is still 6× faster than needed
    delay(5);
}

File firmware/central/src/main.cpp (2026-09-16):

/**
 * @file main.cpp
 * @brief ESP32 Central Controller for Camper Van Remote Switching System
 * 
 * Runs on the ESP32-S3 Central unit in the electrical cabinet.
 * Listens for ESP-NOW messages from remote panels, dispatches commands
 * to the registered digital and dimmable channels, and monitors battery levels.
 */

#include <Arduino.h>
#include "SystemController.h"
#include "WirelessManager.h"
#include "protocol.h"

#if defined(ARDUINO_ARCH_ESP32)
#include <esp_task_wdt.h>
#define WDT_TIMEOUT_SECONDS 10

// FreeRTOS queue for thread-safe transfer from wifi_task to loopTask
struct PacketQueueItem {
    uint8_t senderMac[6];
    SwitchMessage msg;
};
static QueueHandle_t packetQueue = nullptr;
#endif

// Instantiate the global system coordinator and wireless manager
SystemController systemController;
WirelessManager wirelessManager;

// Provisioned Central MAC address
const uint8_t centralMac[6] = {0xAA, 0xBB, 0xCC, 0xDD, 0xEE, 0xFF};

// Allow-listed Remote MAC addresses (must match actual remotes)
const uint8_t remoteMacs[][6] = {
    {0xAA, 0xBB, 0xCC, 0xDD, 0xEE, 0x11}, // Remote 1 (Entry Panel)
    {0xAA, 0xBB, 0xCC, 0xDD, 0xEE, 0x22}, // Remote 2 (Bed Panel)
    {0xAA, 0xBB, 0xCC, 0xDD, 0xEE, 0x33}  // Remote 3 (Cockpit Panel)
};
const uint8_t NUM_REMOTES = sizeof(remoteMacs) / sizeof(remoteMacs[0]);
const uint8_t ESP_NOW_LMK[16] = {0x01, 0x02, 0x03, 0x04, 0x05, 0x06, 0x07, 0x08, 0x09, 0x0A, 0x0B, 0x0C, 0x0D, 0x0E, 0x0F, 0x10};

// Callback when data is received over ESP-NOW (executes in wifi_task context)
void OnDataRecv(const esp_now_recv_info *recv_info, const uint8_t *incomingData, int len) {
    if (len != sizeof(SwitchMessage)) {
        Serial.printf("Error: Invalid packet size received (%d bytes, expected %d)\n", len, sizeof(SwitchMessage));
        return;
    }

    // 1. MAC Address Allow-list validation
    int remoteIdx = -1;
    for (int i = 0; i < NUM_REMOTES; i++) {
        if (memcmp(recv_info->src_addr, remoteMacs[i], 6) == 0) {
            remoteIdx = i;
            break;
        }
    }

    if (remoteIdx == -1) {
        Serial.println("Rejected packet: sender MAC address not in allow-list.");
        return;
    }

#if defined(ARDUINO_ARCH_ESP32)
    // 2. Post packet to FreeRTOS queue to avoid data race with loopTask
    PacketQueueItem item;
    memcpy(item.senderMac, recv_info->src_addr, 6);
    memcpy(&item.msg, incomingData, sizeof(SwitchMessage));
    if (packetQueue && xQueueSend(packetQueue, &item, 0) != pdTRUE) {
        Serial.println("[WARN] ESP-NOW packet queue full, dropped frame.");
    }
#else
    SwitchMessage msg;
    memcpy(&msg, incomingData, sizeof(msg));
    systemController.dispatchMessage(recv_info->src_addr, msg);
#endif
}

void setup() {
    Serial.begin(115200);
    delay(1000);
    Serial.println("Starting VanNOW Central Controller (alpha, not 1.0)...");

#ifdef RGB_BUILTIN
    // GPIO 38 (v1.1) / GPIO 48 (v1.0) are optocoupler outputs. Do not drive the DevKit WS2812.
    pinMode(RGB_BUILTIN, INPUT);
#endif

    // Initialize physical outputs, safety timers, and restore persisted states
    systemController.begin();

    Serial.print("Central MAC Address: ");
    Serial.println(WiFi.macAddress());

#if defined(ARDUINO_ARCH_ESP32)
    // Create thread-safe packet queue (depth 32 to prevent overflow under NVS write load)
    // FIX [HIGH-02]: Increased from 16 to 32 to handle bursty traffic during Serial/NVS blocking
    packetQueue = xQueueCreate(32, sizeof(PacketQueueItem));

    // Initialize Task Watchdog Timer (10s timeout)
#if ESP_IDF_VERSION >= ESP_IDF_VERSION_VAL(5, 0, 0)
    esp_task_wdt_config_t twdt_config = {
        .timeout_ms = WDT_TIMEOUT_SECONDS * 1000,
        .idle_core_mask = 0,
        .trigger_panic = true,
    };
    esp_task_wdt_init(&twdt_config);
#else
    esp_task_wdt_init(WDT_TIMEOUT_SECONDS, true);
#endif
    esp_task_wdt_add(NULL); // Subscribe current loopTask
    Serial.printf("Task Watchdog Timer configured with %d second timeout.\n", WDT_TIMEOUT_SECONDS);
#endif

    // Initialize Wi-Fi and ESP-NOW via WirelessManager with provisioned MAC
    if (!wirelessManager.begin(centralMac)) {
        Serial.println("Fatal: Error initializing wireless subsystem. Rebooting...");
        delay(2000);
        ESP.restart();
    }

    // Register allowed remote panels as encrypted peers
    for (int i = 0; i < NUM_REMOTES; i++) {
        if (!wirelessManager.addPeer(remoteMacs[i], ESP_NOW_LMK)) {
            Serial.printf("Error adding Remote %d to peer list.\n", i + 1);
        }
    }

    // Register callback for incoming data
    if (!wirelessManager.registerReceiveCallback(OnDataRecv)) {
        Serial.println("Fatal: Error registering receive callback. Rebooting...");
        delay(2000);
        ESP.restart();
    }

    Serial.println("System initialized. Awaiting wireless ESP-NOW commands.");
}

void loop() {
#if defined(ARDUINO_ARCH_ESP32)
    // Pet Task Watchdog Timer
    esp_task_wdt_reset();

    // Process queued ESP-NOW packets safely in loopTask context
    PacketQueueItem item;
    while (packetQueue && xQueueReceive(packetQueue, &item, 0) == pdTRUE) {
        systemController.dispatchMessage(item.senderMac, item.msg);
    }
#endif

    // Process channel transitions, dimming ramps, auto-off timers, and debounce
    systemController.update();

    // Heartbeat reporting to confirm operational status
    static uint32_t lastHeartbeat = 0;
    uint32_t now = millis();
    if (now - lastHeartbeat > 30000) {
        lastHeartbeat = now;
        float mainBattery = systemController.readMainBatteryVoltage();
        Serial.printf("[Heartbeat] Central Active | Cabin Battery: %.2f V\n", mainBattery);
    }
    
    // FIX [MEDIUM-02]: Reduced delay from 5ms to 1ms for better responsiveness (loop rate 1 kHz vs 200 Hz)
    // Maintains sufficient headroom for 200 Hz PROFET PWM while reducing input latency
    delay(1);
}

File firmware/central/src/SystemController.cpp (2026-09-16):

#include "SystemController.h"
#include <string.h>

const ChannelConfig SystemController::DEFAULT_24CH_CONFIG[DEFAULT_24CH_COUNT] = {
    // 14 High-Side Power Channels (12V PROFET BTS5008)
    {"Lights Zone 1",            12, ChannelType::Dimmable,       0,      true,  80, false}, // Ch 0
    {"Lights Zone 2",            13, ChannelType::Dimmable,       0,      true,  80, false}, // Ch 1
    {"Lights Zone 3",            14, ChannelType::Dimmable,       0,      true,  80, false}, // Ch 2
    {"Lights Zone 4",            15, ChannelType::Dimmable,       0,      true,  80, false}, // Ch 3
    {"Water Pump",                4, ChannelType::Digital,   600000,     false,   0, false}, // Ch 4 (10m safety timer, flood prevention: restore=false)
    {"Exterior Driver Light",     5, ChannelType::Digital,        0,      true,   0, false}, // Ch 5
    {"Exterior Passenger Light",  6, ChannelType::Digital,        0,      true,   0, false}, // Ch 6
    {"Aux Lightbar / Roof",       7, ChannelType::Digital,        0,      true,   0, false}, // Ch 7
    {"Maxxair Fan Power",        17, ChannelType::Digital,        0,      true,   0, false}, // Ch 8
    {"Aux Power 1 (Boiler)",      8, ChannelType::Digital,        0,      true,   0, false}, // Ch 9
    {"Aux Power 2 (Grey Valve)",  9, ChannelType::Digital,        0,     false,   0, false}, // Ch 10
    {"Aux Power 3 (Tank Heat)",  10, ChannelType::Digital,        0,     false,   0, false}, // Ch 11
    {"Aux Power 4 (Aux Sockets)",11, ChannelType::Digital,        0,      true,   0, false}, // Ch 12
    {"Aux Power 5 (Awning)",     18, ChannelType::Digital,        0,      true,   0, false}, // Ch 13

    // 10 Isolated Signal Channels (PC817 Optocouplers / Dry Contacts)
    {"Inverter (Multiplus II)",  21, ChannelType::Digital,        0,      true,   0, false}, // Ch 14
    {"DC-DC Orion-XS #1",        38, ChannelType::Digital,        0,      true,   0, false}, // Ch 15
    {"DC-DC Orion-XS #2",        39, ChannelType::Digital,        0,      true,   0, false}, // Ch 16
    {"SmartSolar MPPT",          40, ChannelType::Digital,        0,      true,   0, false}, // Ch 17
    {"Diesel Heater",            41, ChannelType::Digital,        0,      true,   0, false}, // Ch 18
    {"12V Fridge Compressor",    42, ChannelType::Digital,        0,      true,   0, false}, // Ch 19
    {"Maxxair Keypad Pulse",     47, ChannelType::MomentaryPulse, 250,   false,   0, false}, // Ch 20 (250ms momentary pulse)
    {"Aux Signal 1 (Alarm)",     48, ChannelType::Digital,        0,     false,   0, false}, // Ch 21
    {"Aux Signal 2 (LPG Valve)",  2, ChannelType::Digital,        0,     false,   0, false}, // Ch 22
    {"Aux Signal 3 (Gen Start)", 16, ChannelType::MomentaryPulse, 500,   false,   0, false}  // Ch 23 (500ms momentary pulse)
};

// Legacy 11-channel VanCentralControllerPROFET carrier (150x95 mm).
// GPIO 2 / 16 are cabin/remote status LEDs on that board — not load channels.
const ChannelConfig SystemController::DEFAULT_11CH_CONFIG[DEFAULT_11CH_COUNT] = {
    {"Lights Zone 1",            12, ChannelType::Dimmable,       0,      true,  80, false}, // Ch 0
    {"Lights Zone 2",            13, ChannelType::Dimmable,       0,      true,  80, false}, // Ch 1
    {"Lights Zone 3",            14, ChannelType::Dimmable,       0,      true,  80, false}, // Ch 2
    {"Lights Zone 4",            15, ChannelType::Dimmable,       0,      true,  80, false}, // Ch 3
    {"Water Pump",                4, ChannelType::Digital,   600000,     false,   0, false}, // Ch 4
    {"Exterior Driver Light",     5, ChannelType::Digital,        0,      true,   0, false}, // Ch 5
    {"Aux Power 2",               6, ChannelType::Digital,        0,      true,   0, false}, // Ch 6
    {"Aux Power 3",               7, ChannelType::Digital,        0,      true,   0, false}, // Ch 7
    {"Maxxair Fan Power",        17, ChannelType::Digital,        0,      true,   0, false}, // Ch 8 discrete FET
    {"Inverter (Multiplus II)",  21, ChannelType::Digital,        0,      true,   0, false}, // Ch 9
    {"DC-DC Orion-XS #1",        18, ChannelType::Digital,        0,      true,   0, false}, // Ch 10 (GPIO 18 opto)
};

const RemoteMapping SystemController::DEFAULT_REMOTE_MAPPINGS[20] = {
    // Remote 1: Entrance panel — faceplate order (4 zones + pump + night). Encoder uses ENCODER_BUTTON_INDEX.
    {1, 0, 0, SpecialRemoteAction::None},             // BTN1 -> Ch 0: Lights Zone 1
    {1, 1, 1, SpecialRemoteAction::None},             // BTN2 -> Ch 1: Lights Zone 2
    {1, 2, 2, SpecialRemoteAction::None},             // BTN3 -> Ch 2: Lights Zone 3
    {1, 3, 3, SpecialRemoteAction::None},             // BTN4 -> Ch 3: Lights Zone 4
    {1, 4, 4, SpecialRemoteAction::None},             // BTN5 -> Ch 4: Water Pump
    {1, 5, -1, SpecialRemoteAction::TurnOffAllLights}, // BTN6 -> Master Night Shutdown

    // Remote 2: Bed Panel (7 buttons)
    {2, 0, 2, SpecialRemoteAction::None},  // Button 0 -> Ch 2: Lights Zone 3
    {2, 1, 3, SpecialRemoteAction::None},  // Button 1 -> Ch 3: Lights Zone 4
    {2, 2, 8, SpecialRemoteAction::None},  // Button 2 -> Ch 8: Maxxair Fan Power
    {2, 3, -1, SpecialRemoteAction::TurnOffAllLights}, // Button 3 -> Master Lights Off
    {2, 4, 0, SpecialRemoteAction::None},  // Button 4 -> Ch 0: Lights Zone 1
    {2, 5, 1, SpecialRemoteAction::None},  // Button 5 -> Ch 1: Lights Zone 2
    {2, 6, 4, SpecialRemoteAction::None},  // Button 6 -> Ch 4: Water Pump

    // Remote 3: Cockpit Panel (6 Carling rocker switches, edge-only)
    {3, 0, 5, SpecialRemoteAction::None},  // SW1 -> Ch 5: Exterior Driver Light
    {3, 1, 15, SpecialRemoteAction::None}, // SW2 -> Ch 15: Orion-XS #1 Remote Enable
    {3, 2, 0, SpecialRemoteAction::None},  // SW3 -> Ch 0: Lights Zone 1
    {3, 3, 4, SpecialRemoteAction::None},  // SW4 -> Ch 4: Water Pump
    {3, 4, 14, SpecialRemoteAction::None}, // SW5 -> Ch 14: Inverter MultiPlus II
    {3, 5, 8, SpecialRemoteAction::None}   // SW6 -> Ch 8: Maxxair Fan Power
};

const size_t SystemController::DEFAULT_REMOTE_MAPPING_COUNT = 19;
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

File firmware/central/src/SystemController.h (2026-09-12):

#ifndef SYSTEM_CONTROLLER_H
#define SYSTEM_CONTROLLER_H

#include <Arduino.h>
#include "Channel.h"
#include "DigitalChannel.h"
#include "DimmableChannel.h"
#include "PulseChannel.h"
#include "protocol.h"

#include "AntiReplayFilter.h"
#include <Preferences.h>

// Compile-time carrier identity. Flash 24 onto profet_24ch (180x110 mm),
// 11 onto the legacy VanCentralControllerPROFET carrier (150x95 mm).
#ifndef VANNOW_CHANNEL_PROFILE
#define VANNOW_CHANNEL_PROFILE 24
#endif

// Channel operational archetype
enum class ChannelType : uint8_t {
    Dimmable,
    Digital,
    MomentaryPulse
};

// Parameterized configuration entry for modular channel definition
struct ChannelConfig {
    const char* name;
    uint8_t pin;
    ChannelType type;
    uint32_t autoOffTimeoutMs; // 0 = disabled. For MomentaryPulse: pulse active duration in ms.
    bool restoreOnBoot;        // Whether state should restore from NVS across reboots
    uint8_t defaultBrightness; // For dimmable channels (0 - 100)
    bool activeLow;           // Invert pin output polarity (true = active LOW)
};

// Special multi-channel or global macro actions
enum class SpecialRemoteAction : int16_t {
    None = 0,
    TurnOffAllLights = -1
};

// Decoupled remote button mapping definition
struct RemoteMapping {
    uint8_t remoteId;
    uint8_t buttonIndex;
    int16_t targetChannelIndex;        // Channel array index (0..MAX_CHANNELS-1), or < 0 if purely special
    SpecialRemoteAction specialAction; // Special macro action if any
};

class SystemController {
public:
    static constexpr uint8_t MAX_CHANNELS = 32;
    static constexpr uint8_t MAX_REMOTE_MAPPINGS = 64;
    static constexpr uint8_t DEFAULT_24CH_COUNT = 24;
    static constexpr uint8_t DEFAULT_11CH_COUNT = 11;
    static constexpr uint8_t DEFAULT_CHANNEL_COUNT = DEFAULT_24CH_COUNT;
    static constexpr uint8_t NUM_CHANNELS = DEFAULT_CHANNEL_COUNT; // Backwards-compatible alias
    static constexpr uint8_t ENCODER_BUTTON_INDEX = 7;
    static constexpr uint8_t MAX_TRACKED_REMOTES = 8;

    static uint8_t compiledChannelProfile();

    // Default constructor: 24-ch or 11-ch tables according to VANNOW_CHANNEL_PROFILE
    SystemController();

    // Parameterized constructor: custom channel configurations and optional custom remote mappings
    SystemController(const ChannelConfig* channelConfigs, size_t channelCount,
                     const RemoteMapping* remoteMappings = nullptr, size_t mappingCount = 0);

    ~SystemController();

    // Initialize all registered physical channels, safety timers, and restore persisted states
    void begin();

    // Update all channels (called in loop for transitions, timers, and debounce)
    void update();

    // Dispatch incoming SwitchMessage commands with anti-replay validation and routing
    void dispatchMessage(const uint8_t* senderMac, const SwitchMessage& msg);

    // Read the main 12V battery voltage (analog divisor read on GPIO 1)
    float readMainBatteryVoltage();

    // Replay protection access
    AntiReplayFilter& getAntiReplayFilter();

    // Channel accessors for status inspection and testing
    Channel* getChannel(uint8_t index) const;
    Channel* getChannelByName(const char* name) const;
    int8_t getChannelIndexByName(const char* name) const;
    uint8_t getChannelCount() const;

    // Remote mapping management
    void setRemoteMappings(const RemoteMapping* mappings, size_t count);
    void addRemoteMapping(uint8_t remoteId, uint8_t buttonIndex, int16_t targetChannelIndex,
                          SpecialRemoteAction specialAction = SpecialRemoteAction::None);

    // NVS state persistence operations
    void loadPersistedStates();
    void saveChannelState(uint8_t channelIndex);

    // Water pump timed shower configuration (in milliseconds)
    void setPumpShowerTimeout(uint32_t ms);
    uint32_t getPumpShowerTimeout() const;
    void setPumpChannelIndex(int8_t channelIndex);
    int8_t getPumpChannelIndex() const;

    int8_t getFocusChannel(uint8_t remoteId) const;

    // Authoritative default configurations
    static const ChannelConfig DEFAULT_24CH_CONFIG[DEFAULT_24CH_COUNT];
    static const ChannelConfig DEFAULT_11CH_CONFIG[DEFAULT_11CH_COUNT];
    static const RemoteMapping DEFAULT_REMOTE_MAPPINGS[20];
    static const RemoteMapping DEFAULT_11CH_REMOTE_MAPPINGS[20];
    static const size_t DEFAULT_REMOTE_MAPPING_COUNT;
    static const size_t DEFAULT_11CH_REMOTE_MAPPING_COUNT;

private:
    void initChannels(const ChannelConfig* channelConfigs, size_t channelCount);
    static void onChannelChanged(uint8_t channelIndex, void* context);
    void rememberFocus(uint8_t remoteId, int16_t channelIndex);
    void loadAntiReplayState();
    void saveAntiReplayState(uint8_t remoteId);

    Channel* _channels[MAX_CHANNELS];
    uint8_t _channelCount;

    RemoteMapping _remoteMappings[MAX_REMOTE_MAPPINGS];
    size_t _remoteMappingCount;

    AntiReplayFilter _antiReplay;
    uint32_t _pumpShowerTimeoutMs;
    int8_t _pumpChannelIndex;
    int8_t _focusChannel[MAX_TRACKED_REMOTES + 1];

    // Configuration parameters for main battery reading
    static constexpr uint8_t BATTERY_ADC_PIN = 1;
    static constexpr float DIVIDER_RATIO = (100.0f + 18.0f) / 18.0f; // Divisor resistor values: 100k and 18k
};

#endif // SYSTEM_CONTROLLER_H

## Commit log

2026-07-06 doc: update prototype specs and hardware evaluation for ESP32-S3 central unit
2026-07-06 feat(protocol): define unified SwitchMessage and ActionType enums and fix baseline callbacks
    [main.cpp]
2026-07-06 feat(central): implement DimmableChannel with LEDC PWM and ramping
2026-07-06 feat(central): integrate SystemController in main and fix ESP-NOW callback signature
    [main.cpp]
2026-07-06 feat(remote): implement ButtonHandler for click and hold events
2026-07-06 feat(remote): implement EncoderHandler for rotary EC11 decoding and button switch
2026-07-06 feat(remote): implement PowerManager to handle activity timeout and deep sleep
2026-07-06 test: configure native testing environment and add Arduino mock library
2026-07-06 test(remote): implement unit tests for ButtonHandler, EncoderHandler, and PowerManager
2026-07-06 refactor: decouple Channel.h and protocol.h from Arduino.h framework headers
2026-07-06 feat(wireless): implement shared WirelessManager library to abstract ESP-NOW and Wi-Fi
2026-07-06 test: ignore wireless library in native environment
2026-07-06 feat(central): refactor main to utilize WirelessManager helper class
2026-07-06 feat(remote): refactor main to utilize WirelessManager helper class
2026-07-06 refactor(remote): encapsulate transmission and battery logic into RemoteSender class
2026-09-10 chore(hardware): rename central_pcb to central-pcb and configure ato project
    [default.kicad_pcb]
2026-09-10 docs: add logic audit and reference datasheets
    [XIAO_ESP32C6_Pinout.xlsx, modular.kicad_pcb, profet.kicad_pcb]
2026-09-10 fix(central): resolve GPIO19/20 USB-JTAG conflict and align firmware pin mappings (H-01, FC-01)
    [modular.kicad_pcb, profet.kicad_pcb]
2026-09-10 fix(central): correct battery telemetry divider ratio, use analogReadMilliVolts and add Zener protection (FC-03, H-07)
    [modular.kicad_pcb, profet.kicad_pcb]
2026-09-10 fix(hardware): connect pump flyback diode to override terminal output pin to protect switch contacts (H-06)
    [modular.kicad_pcb, profet.kicad_pcb]
2026-09-10 fix(remote): move BATTERY_ADC_PIN from GPIO4 (strapping pin) to GPIO6 (safe analog pin) (FR-05)
    [main.cpp]
2026-09-10 fix(remote): prevent returning stale delivery status on transmission timeout (FR-02)
    [RemoteSender.cpp]
2026-09-10 fix(remote, central): return 0.0V battery sentinel when battery is dead or disconnected and accept it in central alerts (FR-03)
    [RemoteSender.cpp, SystemController.cpp]
2026-09-10 fix(remote): stop Wi-Fi and deinitialize ESP-NOW before entering deep sleep (FR-10)
    [PowerManager.cpp]
2026-09-10 fix(remote): add GPIO1 (encoder B) to wakeupPins to ensure CCW rotation wakes the device (FR-06)
    [main.cpp]
2026-09-10 fix(remote): implement release debouncing on buttons and encoder switch to prevent spurious events (FR-11)
    [EncoderHandler.cpp, test_remote_handlers.cpp]
2026-09-10 feat(firmware): implement diode binary matrix handler and button scanning
2026-09-10 feat(hardware): update central PCB layout and Atopile definitions
    [modular.kicad_pcb, profet.kicad_pcb]
2026-09-10 feat(skills): add schematic design and verification skill with automotive references
2026-09-10 feat(enclosures): add build123d parametric 3D CAD models, generation scripts, and renders
    [central_enclosure_base.step, central_enclosure_base.stl, central_enclosure_lid.step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]
2026-09-10 feat(enclosures): fix CAD geometry, implement software z-buffer renderer, and add parametric-cad-enclosures skill
    [central_enclosure_base.step, central_enclosure_base.stl, central_enclosure_lid.step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]
2026-09-10 feat(pcb): add central carrier board layouts and raytraced 3D verification renders
    [profet_framed.kicad_pcb]
2026-09-10 feat(firmware): implement Tier 1 critical safety and reliability features
    - Add NVS state persistence (Preferences.h) with settled debounce wear leveling for dimmable channels and configurable boot restoration policy
    - Implement Central Task Watchdog Timer (WDT) with 10s timeout and FreeRTOS packet queue to eliminate thread safety violations between wifi_task and loopTask
    - Implement RFC 6479 64-packet sliding window anti-replay filter with 32-bit monotonic sequence counters in SwitchMessage
    - Add configurable auto-off safety timer (10 min) to DigitalChannel for Channel 4 (Water Pump) with boot-off safety constraint
    - Add mock Preferences support in firmware/lib/arduino_mock/ and comprehensi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
2026-09-10 feat(hardware): implement automated KiCad 3D PCB rendering and STEP CAD export
    - Add headless PCB rendering script (hardware/central-pcb/scripts/render_pcb.py) supporting both native kicad-cli and Flatpak org.kicad.KiCad.
    - Add clean Edge.Cuts board outline and 4x M3 corner mounting holes to profet and modular PCB layouts.
    - Fix series resistor coordinates (R35 and R6) from unplaced origin (0,0) to analog divider cluster at (234,160).
    - Generate high-resolution 1440p raytraced 3D isometric and orthographic renders, silkscreen vector graphics, and 3D STEP models.
    - Create engineering reference guide (.agents/skills/schematic-design/references/pcb_rendering_and_visualization.md) and link in SK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
    [modular.kicad_pcb, profet.kicad_pcb, profet_framed.kicad_pcb]
2026-09-10 docs(skills): create pcb-rendering engineering skill and reference guides
    - Add .agents/skills/pcb-rendering/SKILL.md covering headless KiCad raytracing, Edge.Cuts integrity, 3D STEP export, and ECAD/MCAD clash detection in build123d.
    - Add reference guides for raytracing camera/lighting parameters (raytracing_parameters_guide.md) and programmatic ECAD/MCAD clash detection (ecad_mcad_clash_detection.md).
    - Bundle portable render_pcb.py automation script in skill directory with dynamic project root discovery.
    - Index pcb-rendering skill in AGENTS.md and docs/README.md.
2026-09-10 feat(hardware): implement Atopile schematics and KiCad layouts for cockpit hub and entrance remote PCBs
    [default.kicad_pcb]
2026-09-10 feat(firmware): implement 5-minute timed shower mode for water pump with acoustic chirp and LED notification
2026-09-10 feat(hardware): physical layout, procedural routing, 0 DRC violations and 3D CAD models for entrance-remote-pcb
    [default.kicad_pcb, entrance_remote_pcb.step]
2026-09-10 feat(hardware): physical layout, procedural routing, 0 DRC violations and 3D CAD models for cockpit-pcb
    [cockpit_pcb.step, default.kicad_pcb]
2026-09-10 docs(skills): incorporate procedural routing, 0-DRC rules, and plain text formatting in pcb-rendering and schematic-design skills
2026-09-11 feat(hardware): physical layout, procedural routing, 0 DRC violations and 3D CAD models for central-pcb
    [default.kicad_pcb, profet.kicad_pcb]
2026-09-11 fix(firmware): resolve cold-boot deep-sleep trap, provisioned MAC pairing, Nyquist sampling rate, and entrance remote mapping
    [PowerManager.cpp, RemoteSender.cpp, main.cpp]
2026-09-11 feat(hardware): add automotive 12V TVS and reverse-polarity protection, wire SPDT bypass return, and update LCSC BOM SKUs
2026-09-11 docs: update tracking dashboard with audit resolutions, 28/28 test suite, and automotive protections
    [default.kicad_pcb]
2026-09-11 feat(central): expand architecture to 24 channels and add 3D parametric enclosure
    [central_24ch_enclosure_base.step, central_24ch_enclosure_base.stl, central_24ch_enclosure_lid.step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]
2026-09-11 feat(hardware): implement zero-DRC 24-channel PCB layout, 3D renders, and ECAD/MCAD clearance verification
    - Route all 24 physical channels (14 BTS5008 PROFETs, 10 PC817 optos, MP1584EN socket, AO4407A P-FET, TVS clamp, ADC divider) with zero DRC violations and zero unconnected items
    - Apply decoupled orthogonal layer assignment and South corridor highway fan-out
    - Generate high-fidelity 3D raytraced renders (isometric with floor shadow, top, bottom), 2D vector silkscreen SVG, and populated 3D STEP assembly solid
    - Verify zero geometric clash (0.0 mm^3 interference) against 24-channel parametric enclosure base and lid in build123d
    - Update pcb-rendering and parametric-cad-enclosures engineer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
    [profet_24ch.kicad_pcb, profet_24ch.step]
2026-09-11 fix(firmware): close shower, encoder, and digital-channel FSM defects
    Ignore pump StartHold keep-alives, keep shower/chirp off generic digital outputs, emit DoubleClick, give the encoder exclusive GPIO 20 with focus-zone dimming, add a latching cockpit image, and persist anti-replay plus remote sequence counters in NVS.
    [DigitalChannel.cpp, RemoteSender.cpp]
2026-09-11 fix(hardware): restore pump flyback, D10 LED net, and 24-ch load terminals
    Clamp the ADC with BAT54S, attach 1N5408 diodes to the 11-channel pump output, map XIAO D10 to GPIO 18, and give VanCentralController24Ch real screw-terminal nets so the schematic matches the carrier.
2026-09-11 docs(skills): rewrite firmware and PCB skills to match the 24-channel tree
    Replace invented packet APIs and the wrong XIAO D4=GPIO4 map with the real SwitchMessage, gesture contract, native-test helpers, and profet_24ch layout/DRC paths.
2026-09-11 feat(enclosures): add a cockpit box that fits the 55x45 mm hub
    Raise the base to clear a socketed XIAO, center the north slot on J4-J6, and size the M3 standoffs for a short heat-set insert. Leave the timestamp-only central/remote STEP re-exports out of this commit.
    [cockpit_enclosure_base.step, cockpit_enclosure_base.stl, cockpit_enclosure_lid.step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]
2026-09-12 feat(central): select 11- or 24-channel maps with VANNOW_CHANNEL_PROFILE
    Default env stays 24-ch. Flash the legacy 150x95 mm PROFET carrier with -e esp32-s3-profet-11ch so GPIO 18 stays the DC-DC opto instead of an awning load.
2026-09-16 Fix HIGH/MEDIUM bugs from main branch audit
    ## Critical Fixes (HIGH severity)
    [HIGH-01] Flash Wear: Anti-replay NVS write deduplication
    - Added conditional writes in saveAntiReplayState() to check if maxSeq/bitmap changed
    - Prevents ~10k-100k unnecessary flash writes per month
    - Extends NVS lifetime from 2-12 months to years
    [HIGH-02] Packet Queue Overflow: Increased queue depth 16→32
    - Mitigates packet drops during Serial/NVS blocking
    - Handles bursty traffic during hold gestures (7 packets/sec)
    ## Security Fix (MEDIUM-04)
    Anti-Replay Window Lost on Reboot
    - Fixed loadAntiReplayState() to actually restore windowBitmap from NVS
    - Closes replay vulnerability: up to 64 packets could be r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
    [SystemController.cpp, main.cpp, test_channels.cpp]
